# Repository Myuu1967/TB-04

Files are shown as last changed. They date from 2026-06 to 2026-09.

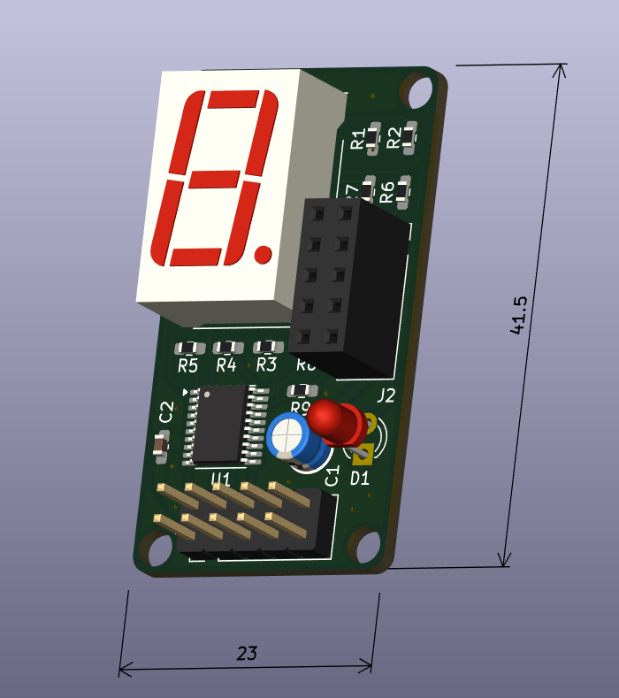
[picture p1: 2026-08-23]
peripherals/7segIF/スクリーンショット (879).png

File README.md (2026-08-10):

# TB-04

自作 4bit CPU **TB-04** のプロジェクトリポジトリです。
TD4 ライクなアーキテクチャをベースに、ALU とデコーダを ROM 実装した独自設計の 4bit CPU です。

回路図・PCB（KiCAD）から、アセンブラ・シミュレータ・テストプログラムまでを世代ごとにまとめています。

## バージョン構成

| 世代 | アドレス幅 | 状態 | ディレクトリ |
|---|---|---|---|
| **ver1** | 4bit（16命令） | 実機完成・全命令動作 | [`ver1/`](ver1/) |
| ver2 | 8bit（256語・データは4bitのまま） | 設計中 | [`ver2/`](ver2/) |
| ver3 | （12bit 化予定） | 構想中 | 追加予定 |

> ver2 以降は、本リポジトリの `ver1/` と並べて追加していきます。

## ver1 の中身

```
ver1/
  hardware/   KiCAD プロジェクト（回路図・PCB・カスタムシンボル/フットプリント）
  sim/        Python による CPU コアシミュレータ・アセンブラ・対話シミュレータ
  tools/      ROM データ生成ツール（ALU / デコーダ / プログラム）・アセンブラ・ロジアナ表示ツール
  codes/      サンプルプログラム・命令テスト（.ASM / .bin / .hex）
  pico_codes/ デバッグ用 簡易ロジックアナライザの Pico 側ファームウェア（MicroPython）
```

ハードウェアの詳細・KiCAD ライブラリの登録方法は [`ver1/hardware/README.md`](ver1/hardware/README.md) を参照してください。

### サンプルプログラム

実機で動かしたデモです。いずれも **16語ROM・4bit・16命令**という制約の中に収めています。

| プログラム | 内容 |
|---|---|
| [`LED_FLOW`](ver1/codes/LED_FLOW.ASM) | 流れるLED（シフト命令なしで実現） |
| [`counter`](ver1/codes/counter.asm) | カウントアップ／ダウン（IN で切替） |
| [`FIBONACCI`](ver1/codes/FIBONACCI.ASM) | フィボナッチ数列 mod 16（ピサノ周期 π(16)=24 で循環） |
| [`RAMEN_TIMER`](ver1/codes/RAMEN_TIMER.ASM) | ラーメンタイマー（TD4 オマージュ） |
| [`KAKEZAN_44`](ver1/codes/KAKEZAN_44.ASM) | かけ算 四四。4×4=16 が4bitで 0 になるのを停止条件に転用 |
| [`LIFE_CA`](ver1/codes/LIFE_CA.ASM) | 1次元セルオートマトン。あふれビットを帰還させ周期15で消えない |
| [`PRED_PREY`](ver1/codes/PRED_PREY.ASM) | 捕食者と被食者の個体数振動（周期6・足し算と引き算だけ） |
| [`MIXED_CORD`](ver1/codes/MIXED_CORD.ASM) | 上記7デモを1個の256語ROMに同梱。ROM上位ニブルの手動セレクタで切替 |

このほかに命令・ポートの動作確認用が17本あります。各プログラムの解説・出力列・アセンブル方法は [`ver1/codes/README.md`](ver1/codes/README.md) を参照してください。

## アーキテクチャ（ver1）

| 項目 | 仕様 |
|---|---|
| データ幅 | 4bit |
| アドレス幅 | 4bit |
| 汎用レジスタ | R0〜R3 |
| フラグ | C（キャリー）、Z（ゼロ） |
| 命令数 | 16命令（OPC 4bit） |
| ALU | ROM 実装（3bit opcode、8演算） |
| デコーダ | ROM 実装（28C256 × 2 並列） |
| プログラム ROM | 28C256 |
| 制御タイミング | 4フェーズ（WB → FCH → DCR → EXE、WB 始まり） |
| スタック | なし |

### 制御タイミングの要点

- 通常命令は開始から2クロック目でフェッチ、4クロック目で実行（全命令ディレイスロットなしの4クロック動作）
- ジャンプ命令のアドレス切り替えは EXE フェーズで実施（ディレイスロット回避）
- フラグは EXE で無条件ラッチ。`MOV`/`MOVI`/`OUT`/`OUTI` は C,Z を 0 クリアするため、**フラグを立てる演算命令の直後に分岐命令（JNC/JZ）を置く**運用とする

## シミュレータの起動

```
cd ver1/sim
python sim.py                        # デフォルト（counter）
python sim.py --prog counter         # 0〜F カウンタ
python sim.py --prog adder           # 加算デモ
python sim.py --prog counter --step  # 1ステップ実行
python sim.py --in 5                 # IN ポートを 5 に設定
```

## ROM データの生成

```
cd ver1/tools
python gen_alu_rom.py        # ALU ROM（alu_rom.bin / .hex）
python gen_decoder_rom.py    # デコーダ ROM（decoder_u22 / u23）
python gen_prog_rom.py       # プログラム ROM
```

## 関連記事

- 設計編 「【TB-04】4bitCPUの設計」: <https://tanuki-bayashin.hatenablog.com/entry/2026/05/27/140048>
- 完成編 「【TB-04】4bitCPUの完成（アドレス4bitバージョン）」: <https://tanuki-bayashin.hatenablog.com/entry/2026/06/20/164917>
- ソースコード編 「【TB-04】4bitCPUのソースコード編（シリーズ完結）」: <https://tanuki-bayashin.hatenablog.com/entry/2026/06/25/220134>
- ロジックアナライザー編 「ラズベリーパイPicoによる簡易ロジックアナライザー」: <https://tanuki-bayashin.hatenablog.com/entry/2026/06/28/074330>

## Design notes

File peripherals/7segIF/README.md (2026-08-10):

# 7segIF — TB-04 用 4bit→7セグメント表示ユニット

本回路は ちぇりーたくあん氏 の nlp リポジトリ（<https://github.com/cherry-takuan/nlp> 、`nlp-16a/Hardware/debug`、CC BY-SA 4.0）を一部参考にし、改変して作成しています。本ユニットのハードウェアも CC BY-SA 4.0 で公開します。

自作 4bit CPU **TB-04** の OUT ポート（4bit）に外付けし、`0`〜`F` を1桁の7セグメントLEDに表示する周辺ユニットです。本体改造は不要で、OUT ポート端子に接続するだけで動作します。ver1／ver2 どちらとも組み合わせられる**版非依存**ユニットのため、リポジトリ直下の `peripherals/` に置いています。

## 構成

| 項目 | 内容 |
|---|---|
| MCU | CH32V003F4P6（WCH・RISC-V, TSSOP-20） |
| 表示器 | LTS-6960HR（コモンアノード・赤・1桁） |
| 電源 | 5V 単一（TB-04 の 74HC 系と共通） |
| デコード方式 | MCU のルックアップテーブル（`0`〜`F` → セグメントパターン） |
| コネクタ | J1（TB-04 OUT 入力）／J2（WCH-Link ＋ UART 兼用ヘッダ） |

## ディレクトリ

```
peripherals/7segIF/
  hardware/            回路図・基板（KiCAD, CC BY-SA 4.0）※完成時にコピー
  firmware/
    main.c             通常版（0〜F をリアルタイム表示）
    main_dp_blink.c    お遊び版（DP を 0.5 秒周期で点滅）
  LICENSE              CC BY-SA 4.0（ハードウェア設計に適用）
  README.md            このファイル
```

## 実配線

- 入力（TB-04 OUT → J1）: `D0=PC0  D1=PC1  D2=PC2  D3=PC3`（PORTC[3:0]）
- 出力（→ 7セグ, 各3.3K）: `a=PD0 b=PD1 c=PD2 d=PD3 e=PD4 f=PD5 g=PD6 DP=PD7`（PORTD[7:0]）
- コモンアノードのため、セグメントは MCU ピン LOW(0) で点灯。

## ファームのビルド・書き込み（MounRiver Studio ＋ WCH SPL）

1. CH32V003F4P6 の新規プロジェクトを作成し、生成される `User/main.c` を `firmware/main.c`（または `main_dp_blink.c`）の内容で**置き換える**。`main()` を持つファイルは1つだけにすること。
2. 初回書き込み時にコードプロテクトで弾かれる場合は、WCH-LinkUtility の `Target → Clear All Code Flash-Protect` で保護解除。接続リセットは **by power off**（本基板は NRST 線をヘッダに出していないため）。
3. **seg b（PD1）は既定で SDI（単線デバッグ）ピン**。ファーム側で SDI を無効化しないと seg b が点灯しません（本リポジトリのファームは対応済み：`GPIO_PinRemapConfig(GPIO_Remap_SDI_Disable, ENABLE)`）。SDI 無効化後はライブデバッグ不可、再書き込みは power-off unlock で行います。
4. **DP（PD7）は既定 NRST**。DP を光らせるにはオプションバイト `RST_MODE` を GPIO 側に設定します（数字 `a`〜`g` のみなら不要）。

## ライセンス

- **ハードウェア**（`hardware/`）: CC BY-SA 4.0。詳細・帰属は [`LICENSE`](./LICENSE) を参照。
- **ファームウェア**（`firmware/`）: ちぇりー氏の著作物に由来しない独自実装で、上記 CC BY-SA の対象外です。

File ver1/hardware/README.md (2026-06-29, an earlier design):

# TB-04

自作4bitCPU **TB-04** のKiCADプロジェクトです。

## 概要

TD4ライクなアーキテクチャをベースに独自設計した4bitCPUです。
ALUとデコーダをROM実装し、汎用レジスタR0〜R3、フラグC/Zを持ちます。

## 現バージョン: 4bitアドレス版

| 項目 | 仕様 |
|---|---|
| データ幅 | 4bit |
| アドレス幅 | 4bit（16命令） |
| 汎用レジスタ | R0〜R3 |
| フラグ | C（キャリー）、Z（ゼロ） |
| ALU | ROM実装（8演算） |
| デコーダ | ROM実装（2個並列） |
| プログラムROM | 28C256（ZIFソケット） |
| 制御タイミング | 4フェーズ（FCH/DCR/EXE/WB） |

> 注記（2026-06-30）: 回路図を一部修正しました。PCBは現在、この修正を反映する改訂作業中（工事中）です。

## 将来の拡張予定

- 8bitアドレス版
- 12bitアドレス版

## ライブラリの登録

このリポジトリにはカスタムシンボル・フットプリントが含まれています。
回路図・PCBを正しく開くには、KiCADのライブラリパスに以下を登録してください。

### シンボルライブラリ

`環境設定 → シンボルライブラリを管理` で以下を追加:

| ライブラリ名 | ファイル |
|---|---|
| `New_Library` | `symbols/New_Library.kicad_sym` |
| `originalCPU` | `symbols/originalCPU.kicad_sym` |
| `74HC161` | `symbols/74HC161N.kicad_sym` |

### フットプリントライブラリ

`環境設定 → フットプリントライブラリを管理` で以下を追加:

| ライブラリ名 | フォルダ |
|---|---|
| `Library` | `footprints/Library.pretty` |

## KiCADプロジェクト構成

| シート | 内容 |
|---|---|
| TB04addr4bitVer3.kicad_sch | トップシート（電源・WEデコード） |
| RS.kicad_sch | レジスタR0〜R3（74HC161 × 4 + 74HC253 × 3） |
| RS01.kicad_sch | 追加レジスタ・プログラム入力 |
| ROM_ALU_Decoder.kicad_sch | 28C256 × 4 + PC + フラグ |
| ALU.kicad_sch | LEDモニターインターフェース |
| clk_rst.kicad_sch | クロック・リセット |
| TB04addr4bitVer3.kicad_pcb | PCBレイアウト |

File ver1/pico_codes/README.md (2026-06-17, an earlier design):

# pico_codes — Pico 簡易ロジックアナライザ（送信側）

デバッグに使用した自作ロジックアナライザの **Raspberry Pi Pico 側ファームウェア**（MicroPython）です。
PC 側の表示ツールは [`../tools/logic_monitor.py`](../tools/logic_monitor.py) を使います。

## forLogiAna.py

- Pico の **GP2〜GP8 を 7ch（CH0〜CH6）の入力**として読み取り、`UART0`（GP0=TX / GP1=RX、115200bps）で CSV 形式に送信します
- フォーマット: `経過秒,CH0,CH1,...,CH6`（10Hz サンプリング）
- 入力は分圧抵抗（例: 1kΩ + 2kΩ）経由で接続

## 使い方

1. Pico に MicroPython を書き込み、`forLogiAna.py` を `main.py` として配置（または実行）
2. Pico の GP0/GP1 を USB シリアル変換に接続し、PC 側で COM ポートを確認
3. PC 側で `python ../tools/logic_monitor.py`（COM ポートはスクリプト内の設定に合わせる）

> ロジックアナライザの製作経緯・回路の詳細は別記事で解説予定です。

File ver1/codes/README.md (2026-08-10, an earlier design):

# ver1 サンプルプログラム

自作 4bit CPU **TB-04 ver1**（データ4bit／アドレス4bit／16命令）で実機動作させたプログラム集です。

各プログラムは `.ASM`（ソース）と `.bin` / `.hex`（アセンブル済みROMイメージ）の3点セットで置いてあります。`.hex` は Intel HEX 形式で、そのまま 28C256 に焼けます。

## ver1 の制約

このCPUの制約を知っていると、コードの書き方の理由が見えてきます。

- **プログラムROMは16語**（PCが4bit）。つまり **1本あたり最大16命令**。ほとんどのデモが「ちょうど16命令」で収まっているのはそのためです
- **汎用レジスタは R0〜R3 の4本**だけ。即値は4bit（0〜15）
- **フラグ保持の機構がない**（C・Z は EXE フェーズで無条件ラッチされ、`MOV`/`MOVI`/`OUT`/`OUTI` は C,Z を0クリアしてしまう）
  → **フラグを立てる命令（`ADD`/`SUB`/`ADDI`/`SUBI`/`AND`/`OR`/`XOR`、`IN` の Z）の直後に分岐命令（`JNC`/`JZ`）を置く**のがver1の運用規約です。退避や表示は分岐より後に回します
- 4bit演算なので加減算はすべて **mod 16**。この「あふれ」を仕様として利用しているデモがいくつかあります

## アセンブルのしかた

```
cd ver1/tools
python tanuki_asm.py    ../codes/counter.asm    -o ../codes/counter      # 16語・単一ページ
python tanuki_asm256.py ../codes/MIXED_CORD.ASM -o ../codes/MIXED_CORD   # 256語・マルチページ
```

`.bin` と `.hex` が生成されます（`--no-bin` で抑止）。通常は `tanuki_asm.py` を使い、後述の `MIXED_CORD` だけ 256語版を使います。

---

## デモプログラム

| ファイル | 内容 | 出力 |
|---|---|---|
| [`LED_FLOW.ASM`](LED_FLOW.ASM) | 流れるLED | IN=0: `1,3,6,12,8,12,6,3`（8周期・往復）／IN≠0: `3,6,12,8`（4周期・一方向） |
| [`counter.asm`](counter.asm) | カウントアップ／ダウン | IN=0: `15→0` ダウン／IN≠0: `1→15→0` アップ |
| [`FIBONACCI.ASM`](FIBONACCI.ASM) | フィボナッチ数列 mod 16 | 周期24 `1,2,3,5,8,13,5,2,7,9,0,9,9,2,11,13,8,5,13,2,15,1,0,1` |
| [`RAMEN_TIMER.ASM`](RAMEN_TIMER.ASM) | ラーメンタイマー（TD4オマージュ） | `1`→`3`→`0,7` 点滅×16→`15` で停止 |
| [`KAKEZAN_44.ASM`](KAKEZAN_44.ASM) | かけ算 四四（4×4の全16積） | `1,2,3,4／2,4,6,8／3,6,9,12／4,8,12,0` で停止 |
| [`LIFE_CA.ASM`](LIFE_CA.ASM) | 1次元セルオートマトン | 周期15 `1,2,4,8,3,6,12,11,5,10,7,14,15,13,9` |
| [`PRED_PREY.ASM`](PRED_PREY.ASM) | 捕食者と被食者の個体数振動 | 周期6 (被食,捕食)=`(15,8)(15,15)(8,15)(1,8)(1,1)(8,1)` |
| [`TASHIZAN_44.ASM`](TASHIZAN_44.ASM) | 四の段を延々出力（`KAKEZAN_44` の停止なし版） | ※ `.bin`/`.hex` は未生成 |
| [`MIXED_CORD.ASM`](MIXED_CORD.ASM) | 上記7デモを1個の256語ROMに同梱（後述） | ページ切替で選択 |

### LED_FLOW — 流れるLED

`OUTI` でパターン列を直接出すだけの構成で、**シフト命令を使わずに**流れるLEDを実現しています。IN の値で往復パターンと一方向パターンを切り替えます（`IN`→`JZ` で分岐）。お披露目向きの一本。

### counter — カウントアップ／ダウン

`IN`→`JZ` で分岐し、`ADDI R0,1` を回すか `SUBI R0,1` を回すかを選びます。`IN` が Z フラグを更新することを利用した最小の分岐例です。

### FIBONACCI — フィボナッチ数列 mod 16

4bitレジスタなので自然に mod 16 になります。フィボナッチ数列を mod m で取ると必ず循環し（**ピサノ周期**）、π(16) = 24 項です。目印は「0 の次に 9 が2回続く」ところと、`15`（全点灯）。7命令/項のループで、`XOR R2,R2` をゼロクリアに使っています。

### RAMEN_TIMER — ラーメンタイマー

`ADDI R0,1` を C が立つまで回す（＝16回）ことを時間の単位に使う遅延ループです。`JNC` でループを作り、区切りごとに `OUTI` で表示を変え、最後に `15`（全点灯）を出して自己ループで停止します。

### KAKEZAN_44 — かけ算 四四

足し算の繰り返しで i×j を作ります。見どころは**レジスタ不足を「終了フラグの転用」で解決**しているところ。4×4=16 は4bitで 0 に落ちて Z=1 が立つので、これをそのまま停止条件に使い、外側ループ用のカウンタを不要にしています。おかげで R0=作業/内側カウンタ、R1=積、R2=被乗数、R3=定数4 の**4本ちょうど**で成立し、**16語ROMにちょうど16命令**で収まりました。

### LIFE_CA — “生きている”1次元セルオートマトン

4セル（=OUT の4LED）だけの素直なセルオートマトンは、線形性のせいで必ず全滅（→0000）してしまいます。そこで**あふれたビットを帰還させて自己再生させる** 4bit最大長LFSR（周期15）＝「Rule60＋帰還」にしました。種 `0001` から非ゼロ15状態を巡回し、消えません。

- 左シフト = `ADD R1,R1`（C = あふれた最上位）
- `JNC` で分岐 → C=1 のとき `XOR R1,M`（帰還タップ M=`0b0011`）
- `IN`→`AND`（マスク `0b0111`）→`OR` でセルを注入し、インタラクティブに軌道をかき乱せます

**XOR / AND / OR を全部使う**のもこのプログラムの役どころです。なお本家コンウェイのライフゲームは盤面用のRAMが要るので ver1 では不可能で、これは ver2（データメモリ導入）への動機になりました。

### PRED_PREY — 捕食者と被食者の個体数振動

本物のロトカ・ヴォルテラ方程式は `prey×pred` の積の項が要るので、乗算のない4bit・16命令では重すぎます。そこで平衡点 K=8 まわりの**線形振動子**を**シンプレクティック更新**（pred の更新に、更新後の prey' を使う）で解き、軌道が閉じる周期6の個体数サイクルにしました。**足し算と引き算だけ**で成立します。

```
prey' = prey + (K - pred)     ; 捕食者が少ないと草食が増える
pred' = pred + (prey' - K)    ; 草食が多いと肉食が増える（更新後の prey' を使う）
```

線形写像 M = [[1,-1],[1,0]] は M⁶ = I（固有値 e^{±iπ/3}）なので、mod 16 でも**厳密に周期6**になります。初期値 prey=8, pred=1 で 1〜15 をフルスイングし、草食のピークから**1世代遅れて**肉食がピークを迎える位相遅れが観察できます。条件分岐を使わない純算術＋`JMP` なので、フラグ運用規約の制約を受けません。

> 軌道は平衡点 (8,8) を通らない閉軌道です。「被食==捕食」になるループが2回（`(15,15)` と `(1,1)`）あり、そこでは LED の見た目が変わらないため止まって見えますが、実際は循環し続けています。

### MIXED_CORD — 7デモを1個のROMに同梱

上の7デモを**16語ページ境界に `.org` で並べて**、256語のROM1個にまとめたものです。

| ページ | デモ | | ページ | デモ |
|---|---|---|---|---|
| `0x00` | LED_FLOW | | `0x80` | LIFE_CA |
| `0x20` | Counter | | `0xA0` | RAMEN_TIMER |
| `0x40` | FIBONACCI | | `0xC0` | PRED_PREY |
| `0x60` | TASHIZAN_44 | | | |

**切り替えはプログラムROM（28C256）の上位ニブル A4–A7 を手動セレクタで選ぶだけ**です。PC 本体は4bitのままで、各デモは自ページ内でループし `JMP` も下位4bitで同ページ内に閉じるので、ページの外へは出ません。**CPU側の変更は不要**で、A4–A7 を選択可能にするだけで動きます（実機確認済み）。

ソフトだけでメニュー切替を作ることはできません。`JMP` が下位4bitしか書けずページを跨げないためで、ハード側のページセレクタが素直な解になります。

アセンブルには **`tanuki_asm256.py`** を使ってください（ラベルを16語ページ単位でスコープ化し、`JMP`/`JZ`/`JNC` を下位4bitで符号化、ページ跨ぎはエラーにします）。

---

## 命令の動作確認用

実機の立ち上げ・デバッグ時に、命令やポートを1つずつ潰していくために書いたものです。ほとんどが16語を埋める形になっています。

| ファイル | 確認内容 |
|---|---|
| `NOP.ASM` | `NOP` ×16（PCが進むことの確認） |
| `MOV.ASM` | `IN` で値を入れて R0〜R3 の全転送組み合わせ |
| `MOVI.ASM` | `MOVI 0`〜`MOVI 15`（即値16通り） |
| `ADD.ASM` | `IN` で値を入れてレジスタ間加算 |
| `ADDI.ASM` / `SUBI.ASM` | 即値 0〜15 の加算／減算（桁上げ・借りの確認） |
| `OUT_I.ASM` | `OUT` と `OUTI` の両方。`1,2,4,8,4,2,1` で単LEDが往復 |
| `JMP_N.ASM` | 全16番地への `JMP`（アドレス各ビットの確認） |
| `JNC.ASM` | `ADDI`→`JNC` のループと `SUBI`→`JZ` のループを両方通す |
| `IN_OUT.ASM` / `IN_ADD.ASM` / `IN_MOV.ASM` | IN ポートと各命令の組み合わせ |
| `IN_AND.ASM` / `IN_OR.ASM` / `IN_XOR.ASM` / `IN_SUB.ASM` | 論理演算・減算の全パターン掃引 |

`IN_AND.ASM` は実機デバッグで役に立った一本で、AND 命令の全レジスタ組み合わせを掃引しながらロジックアナライザでセレクト信号を同時観測し、**MUXの誤結線**（74HC253 の S1 と `/E2` の取り違え）を突き止めました。

---

## 関連

- 設計の解説: [【TB-04】4bitCPUの設計](https://tanuki-bayashin.hatenablog.com/entry/2026/05/27/140048)
- 完成の様子とデモ動画: [【TB-04】4bitCPUの完成（アドレス4bitバージョン）](https://tanuki-bayashin.hatenablog.com/entry/2026/06/20/164917)
- ROM生成・アセンブラ・シミュレータの解説: [【TB-04】4bitCPUのソースコード編](https://tanuki-bayashin.hatenablog.com/entry/2026/06/25/220134)
- シミュレータでの実行方法はリポジトリ直下の [README](../../README.md) を参照

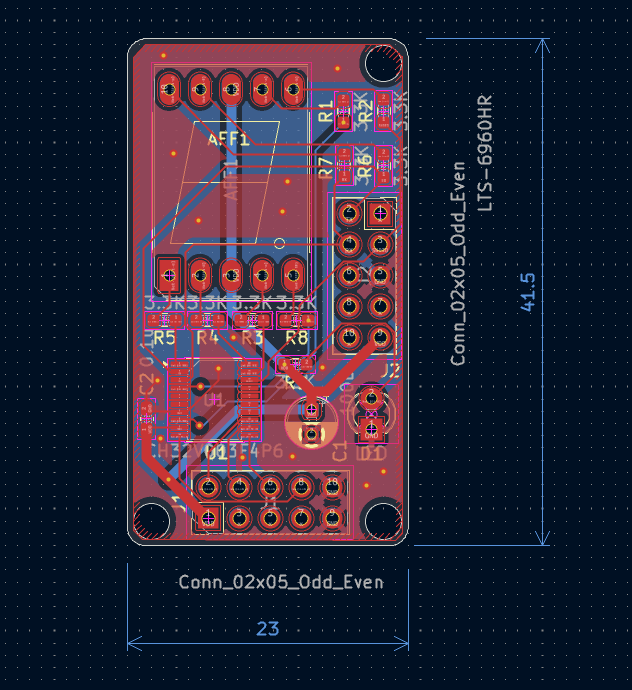
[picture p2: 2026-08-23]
peripherals/7segIF/スクリーンショット (878).png

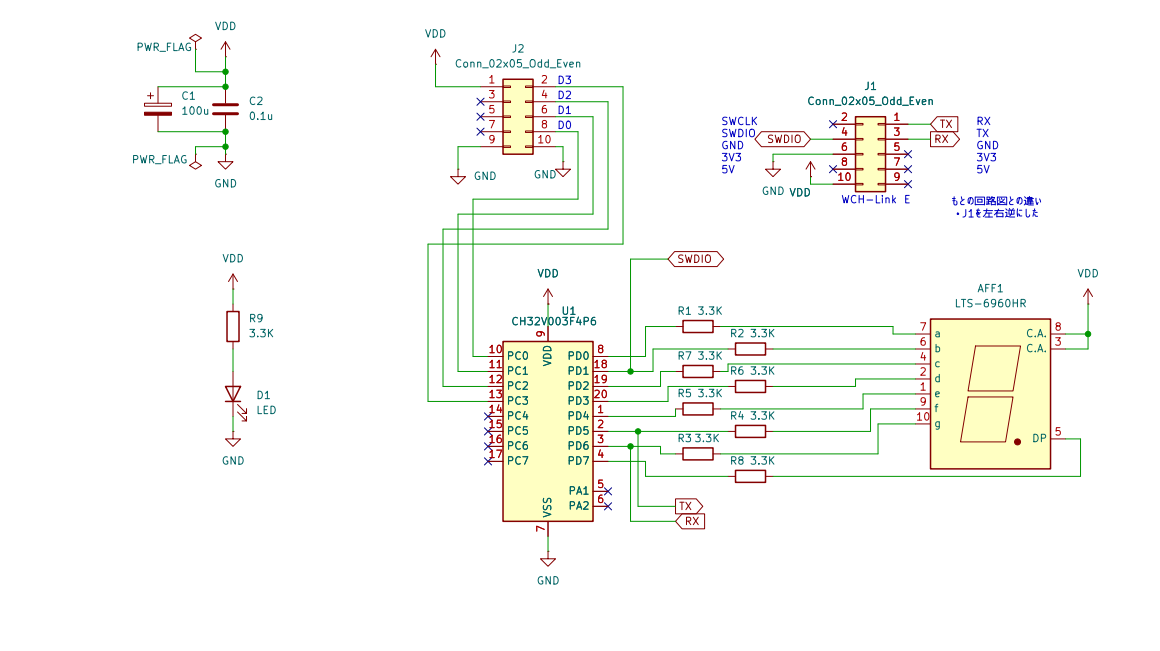
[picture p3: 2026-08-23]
peripherals/7segIF/スクリーンショット (913).png

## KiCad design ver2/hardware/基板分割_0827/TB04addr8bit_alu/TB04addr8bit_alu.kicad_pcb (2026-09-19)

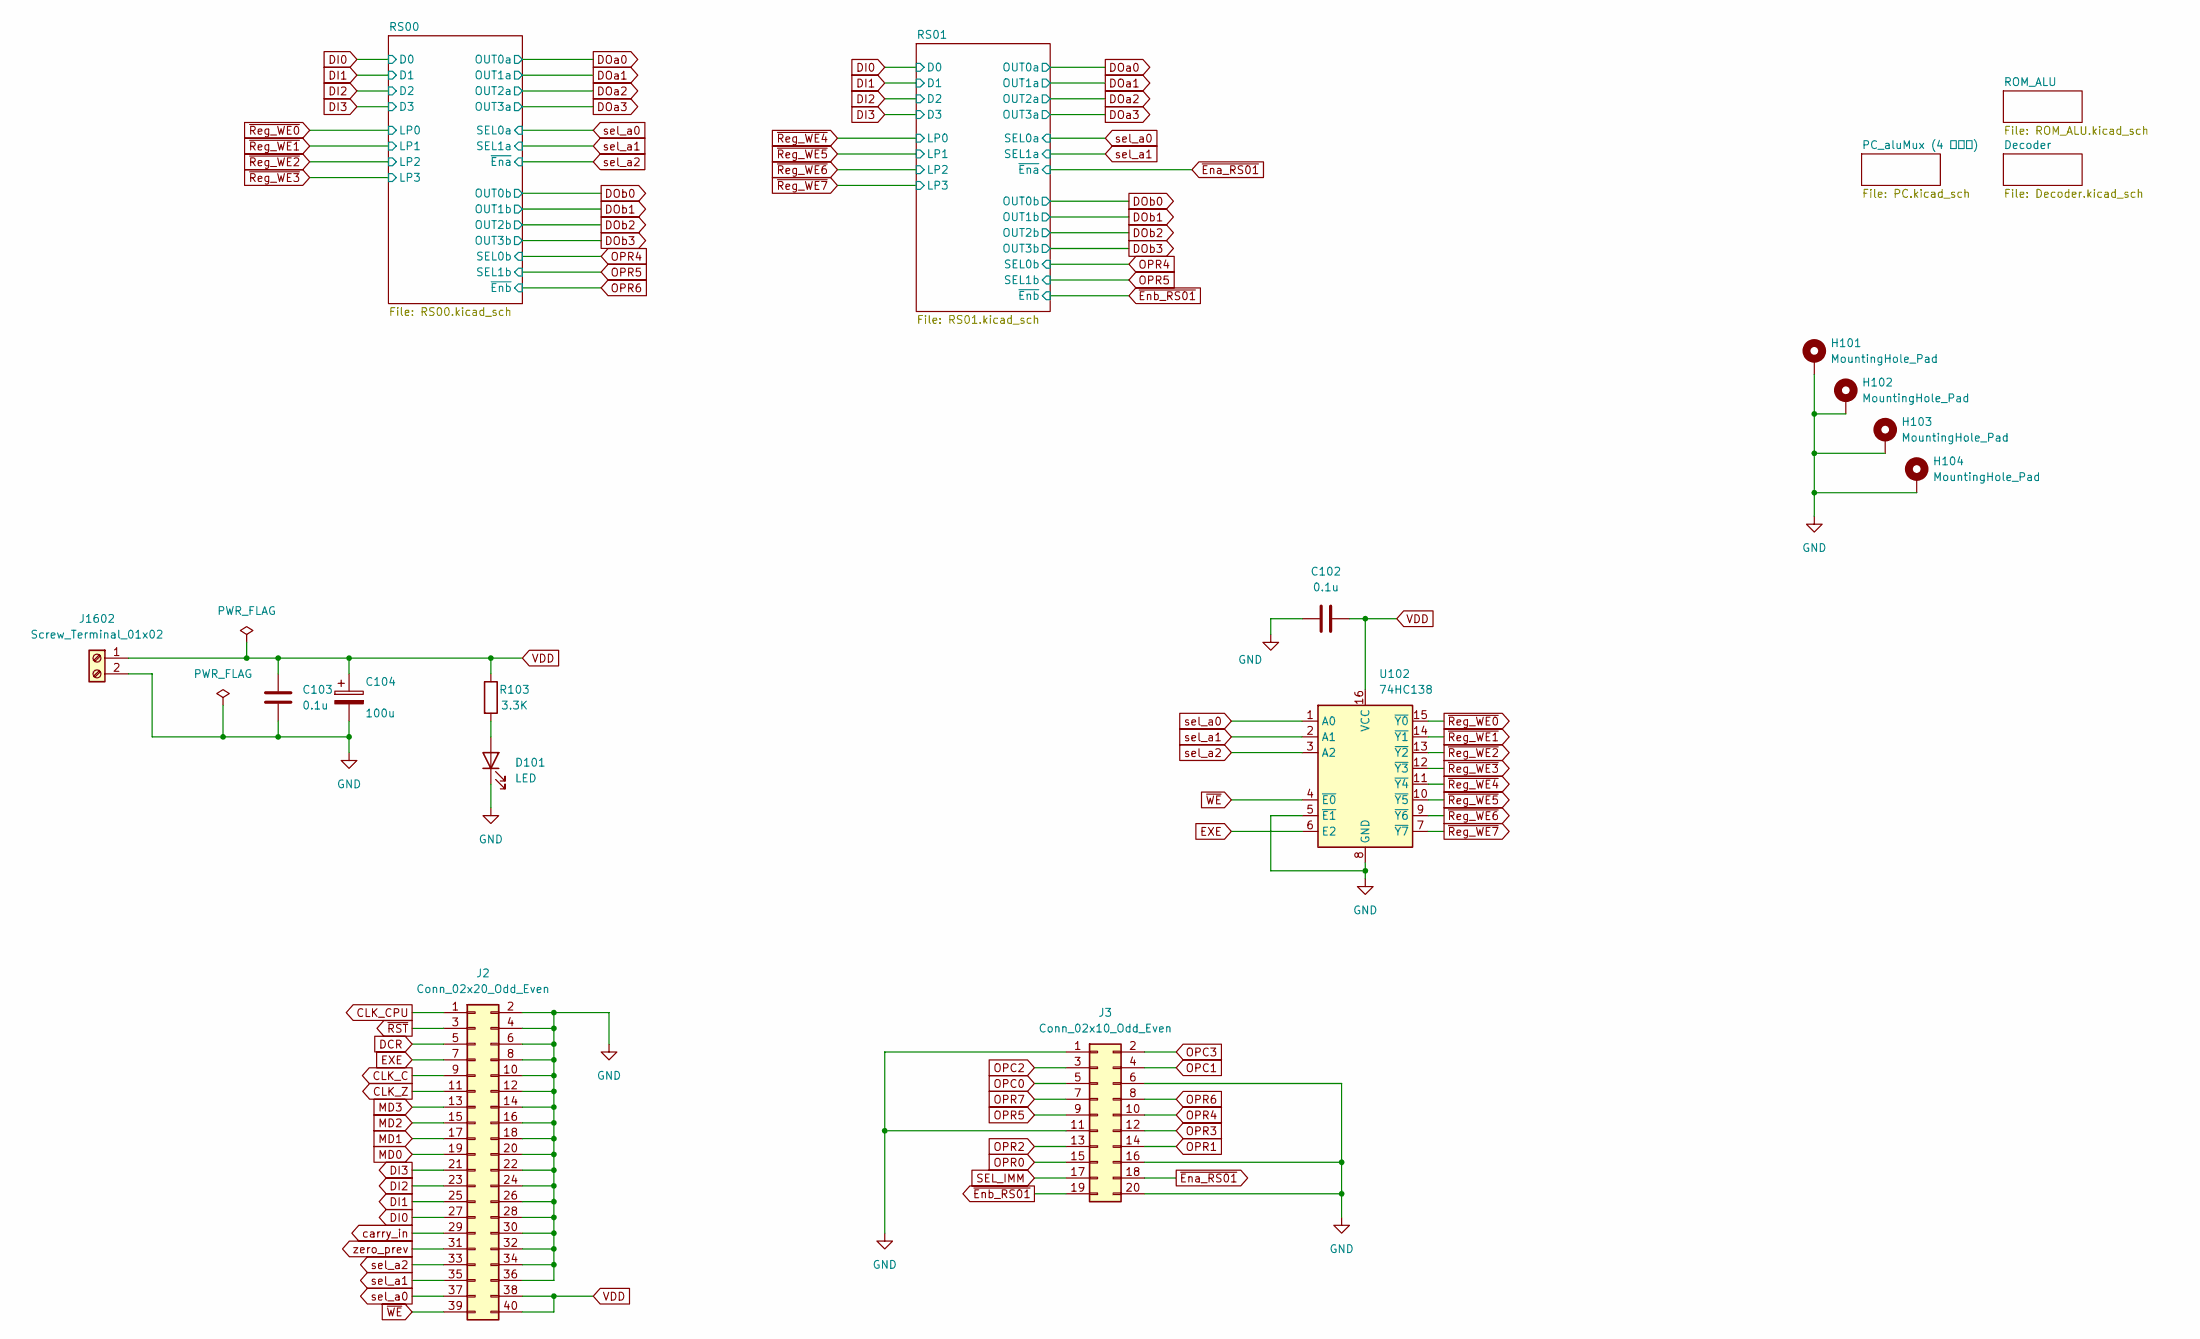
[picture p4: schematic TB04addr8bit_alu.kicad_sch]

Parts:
C102, C103: 0.1u; C_Disc_D4.3mm_W1.9mm_P5.00mm
C104: 100u; CP_Radial_D5.0mm_P2.00mm
D101: LED; LED_D3.0mm_Clear
H101, H102, H103, H104: MountingHole_Pad; MountingHole_3.2mm_M3_Pad_Via
J2: Conn_02x20_Odd_Even; PinSocket_2x20_P2.54mm_Vertical
J3: Conn_02x10_Odd_Even; PinSocket_2x10_P2.54mm_Vertical
J1602: Screw_Terminal_01x02; TerminalBlock_MaiXu_MX126-5.0-02P_1x02_P5.00mm
R103: 3.3K; R_Axial_DIN0207_L6.3mm_D2.5mm_P7.62mm_Horizontal
U102: 74HC138; DIP-16_W7.62mm_Socket

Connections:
CLK_C: J2.9; also elsewhere on the board
CLK_CPU: J2.1; also elsewhere on the board
CLK_Z: J2.11; also elsewhere on the board
DCR: J2.5; also elsewhere on the board
DI0: J2.27; also elsewhere on the board
DI1: J2.25; also elsewhere on the board
DI2: J2.23; also elsewhere on the board
DI3: J2.21; also elsewhere on the board
EXE: J2.7, U102.6 (E2)
GND: C102.2, C103.2, C104.2, D101.1 (K), H101.1 (1_1), H102.1 (1_1), H103.1 (1_1), H104.1 (1_1), J2.2, J2.4, J2.6, J2.8, J2.10, J2.12, J2.14, J2.16, J2.18, J2.20, J2.22, J2.24, J2.26, J2.28, J2.30, J2.32, J2.34, J2.36, J3.1, J3.6, J3.11, J3.16, J3.20, J1602.2, U102.5 (~E1), U102.8 (GND); also elsewhere on the board
MD0: J2.19; also elsewhere on the board
MD1: J2.17; also elsewhere on the board
MD2: J2.15; also elsewhere on the board
MD3: J2.13; also elsewhere on the board
unnamed: D101.2 (A), R103.2
OPC0: J3.5; also elsewhere on the board
OPC1: J3.4; also elsewhere on the board
OPC2: J3.3; also elsewhere on the board
OPC3: J3.2; also elsewhere on the board
OPR0: J3.15; also elsewhere on the board
OPR1: J3.14; also elsewhere on the board
OPR2: J3.13; also elsewhere on the board
OPR3: J3.12; also elsewhere on the board
OPR4: J3.10; also elsewhere on the board
OPR5: J3.9; also elsewhere on the board
OPR6: J3.8; also elsewhere on the board
OPR7: J3.7; also elsewhere on the board
SEL_IMM: J3.17; also elsewhere on the board
VDD: C102.1, C103.1, C104.1, J2.38, J2.40, J1602.1, R103.1, U102.16 (VCC); also elsewhere on the board
carry_in: J2.29; also elsewhere on the board
sel_a0: J2.37, U102.1 (A0); also elsewhere on the board
sel_a1: J2.35, U102.2 (A1); also elsewhere on the board
sel_a2: J2.33, U102.3 (A2); also elsewhere on the board
zero_prev: J2.31; also elsewhere on the board
~Ena_RS01: J3.18; also elsewhere on the board
~Enb_RS01: J3.19; also elsewhere on the board
~RST: J2.3; also elsewhere on the board
~Reg_WE0: U102.15 (~Y0); also elsewhere on the board
~Reg_WE1: U102.14 (~Y1); also elsewhere on the board
~Reg_WE2: U102.13 (~Y2); also elsewhere on the board
~Reg_WE3: U102.12 (~Y3); also elsewhere on the board
~Reg_WE4: U102.11 (~Y4); also elsewhere on the board
~Reg_WE5: U102.10 (~Y5); also elsewhere on the board
~Reg_WE6: U102.9 (~Y6); also elsewhere on the board
~Reg_WE7: U102.7 (~Y7); also elsewhere on the board
~WE: J2.39, U102.4 (~E0)

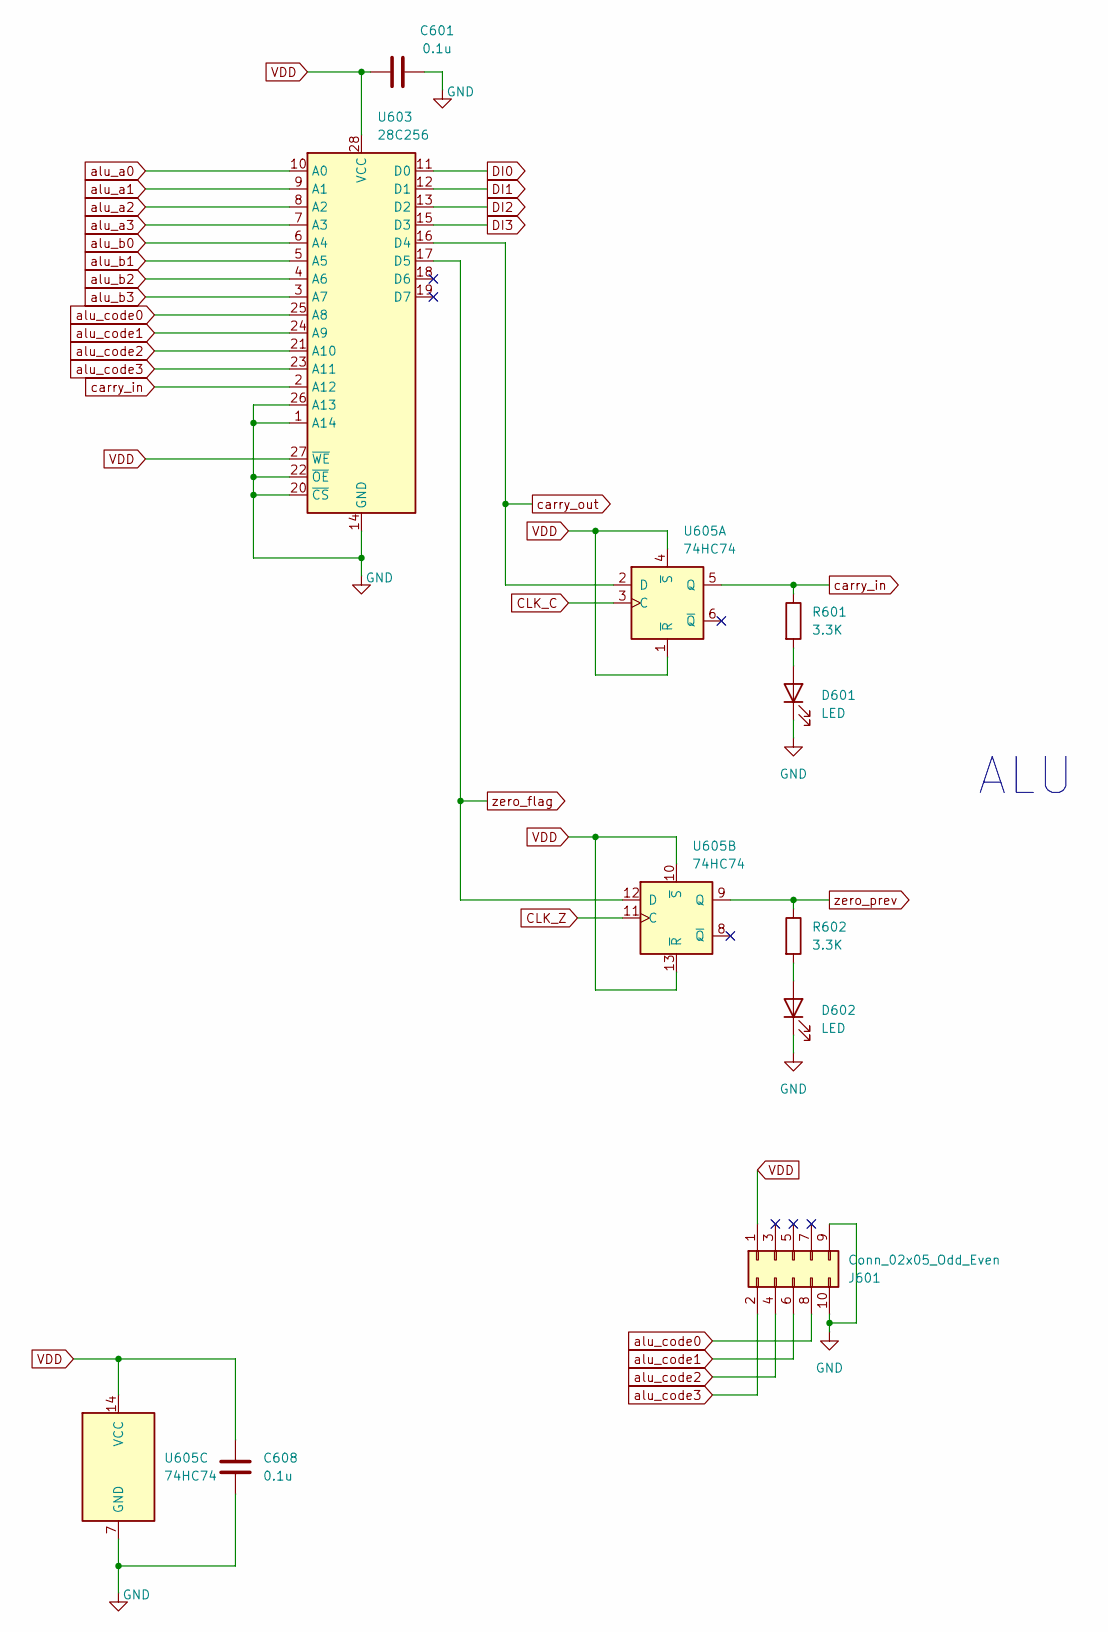
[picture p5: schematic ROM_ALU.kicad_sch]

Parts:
C601, C608: 0.1u; C_Disc_D4.3mm_W1.9mm_P5.00mm
D601, D602: LED; LED_D3.0mm_Clear
J601: Conn_02x05_Odd_Even; PinSocket_2x05_P2.54mm_Vertical
R601, R602: 3.3K; R_Axial_DIN0207_L6.3mm_D2.5mm_P7.62mm_Horizontal
U603: 28C256; DIP-28_W15.24mm_Socket
U605: 74HC74; DIP-14_W7.62mm_Socket

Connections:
CLK_C: U605.3 (C); also elsewhere on the board
CLK_Z: U605.11 (C); also elsewhere on the board
DI0: U603.11 (D0); also elsewhere on the board
DI1: U603.12 (D1); also elsewhere on the board
DI2: U603.13 (D2); also elsewhere on the board
DI3: U603.15 (D3); also elsewhere on the board
GND: C601.1, C608.2, D601.1 (K), D602.1 (K), J601.9, J601.10, U603.1 (A14), U603.14 (GND), U603.20 (~CS), U603.22 (~OE), U603.26 (A13), U605.7 (GND); also elsewhere on the board
unnamed: D601.2 (A), R601.2
unnamed: D602.2 (A), R602.2
VDD: C601.2, C608.1, J601.1, U603.27 (~WE), U603.28 (VCC), U605.1 (~R), U605.4 (~S), U605.10 (~S), U605.13 (~R), U605.14 (VCC); also elsewhere on the board
alu_a0: U603.10 (A0); also elsewhere on the board
alu_a1: U603.9 (A1); also elsewhere on the board
alu_a2: U603.8 (A2); also elsewhere on the board
alu_a3: U603.7 (A3); also elsewhere on the board
alu_b0: U603.6 (A4); also elsewhere on the board
alu_b1: U603.5 (A5); also elsewhere on the board
alu_b2: U603.4 (A6); also elsewhere on the board
alu_b3: U603.3 (A7); also elsewhere on the board
alu_code0: J601.8, U603.25 (A8); also elsewhere on the board
alu_code1: J601.6, U603.24 (A9); also elsewhere on the board
alu_code2: J601.4, U603.21 (A10); also elsewhere on the board
alu_code3: J601.2, U603.23 (A11); also elsewhere on the board
carry_in: R601.1, U603.2 (A12), U605.5 (Q); also elsewhere on the board
carry_out: U603.16 (D4), U605.2 (D)
zero_flag: U603.17 (D5), U605.12 (D)
zero_prev: R602.1, U605.9 (Q); also elsewhere on the board

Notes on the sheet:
ALU

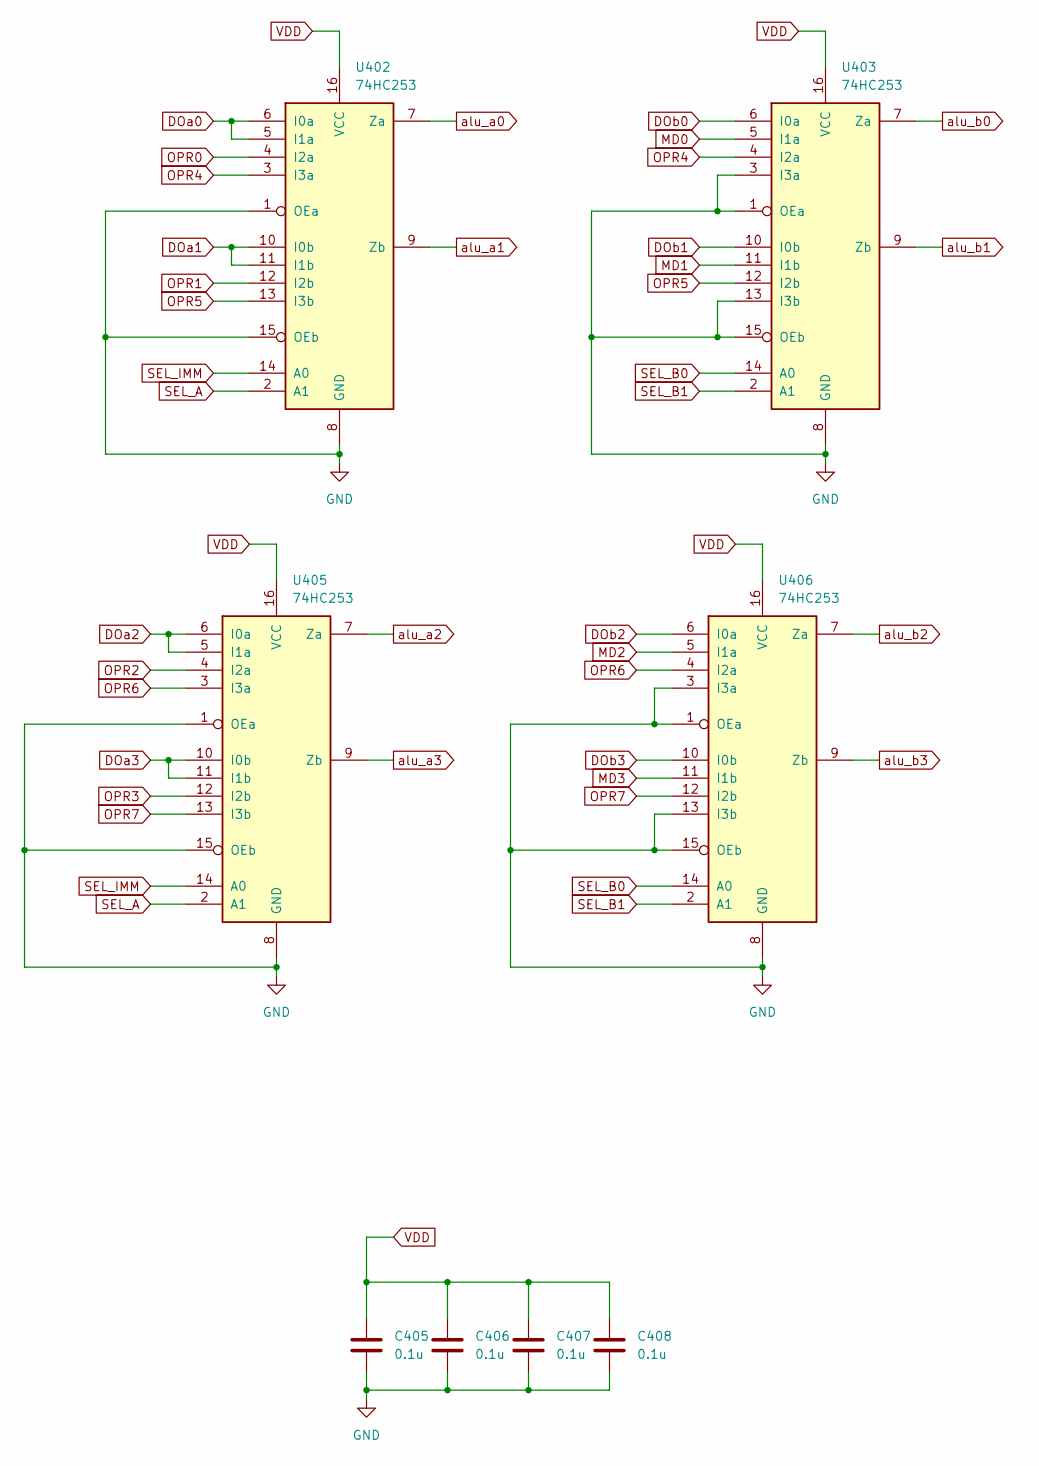
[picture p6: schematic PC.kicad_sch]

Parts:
C405, C406, C407, C408: 0.1u; C_Disc_D4.3mm_W1.9mm_P5.00mm
U402, U403, U405, U406: 74HC253; DIP-16_W7.62mm_Socket

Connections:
DOa0: U402.5 (I1a), U402.6 (I0a); also elsewhere on the board
DOa1: U402.10 (I0b), U402.11 (I1b); also elsewhere on the board
DOa2: U405.5 (I1a), U405.6 (I0a); also elsewhere on the board
DOa3: U405.10 (I0b), U405.11 (I1b); also elsewhere on the board
DOb0: U403.6 (I0a); also elsewhere on the board
DOb1: U403.10 (I0b); also elsewhere on the board
DOb2: U406.6 (I0a); also elsewhere on the board
DOb3: U406.10 (I0b); also elsewhere on the board
GND: C405.1, C406.1, C407.1, C408.1, U402.1 (OEa), U402.8 (GND), U402.15 (OEb), U403.1 (OEa), U403.3 (I3a), U403.8 (GND), U403.13 (I3b), U403.15 (OEb), U405.1 (OEa), U405.8 (GND), U405.15 (OEb), U406.1 (OEa), U406.3 (I3a), U406.8 (GND), U406.13 (I3b), U406.15 (OEb); also elsewhere on the board
MD0: U403.5 (I1a); also elsewhere on the board
MD1: U403.11 (I1b); also elsewhere on the board
MD2: U406.5 (I1a); also elsewhere on the board
MD3: U406.11 (I1b); also elsewhere on the board
OPR0: U402.4 (I2a); also elsewhere on the board
OPR1: U402.12 (I2b); also elsewhere on the board
OPR2: U405.4 (I2a); also elsewhere on the board
OPR3: U405.12 (I2b); also elsewhere on the board
OPR4: U402.3 (I3a), U403.4 (I2a); also elsewhere on the board
OPR5: U402.13 (I3b), U403.12 (I2b); also elsewhere on the board
OPR6: U405.3 (I3a), U406.4 (I2a); also elsewhere on the board
OPR7: U405.13 (I3b), U406.12 (I2b); also elsewhere on the board
SEL_A: U402.2 (A1), U405.2 (A1); also elsewhere on the board
SEL_B0: U403.14 (A0), U406.14 (A0); also elsewhere on the board
SEL_B1: U403.2 (A1), U406.2 (A1); also elsewhere on the board
SEL_IMM: U402.14 (A0), U405.14 (A0); also elsewhere on the board
VDD: C405.2, C406.2, C407.2, C408.2, U402.16 (VCC), U403.16 (VCC), U405.16 (VCC), U406.16 (VCC); also elsewhere on the board
alu_a0: U402.7 (Za); also elsewhere on the board
alu_a1: U402.9 (Zb); also elsewhere on the board
alu_a2: U405.7 (Za); also elsewhere on the board
alu_a3: U405.9 (Zb); also elsewhere on the board
alu_b0: U403.7 (Za); also elsewhere on the board
alu_b1: U403.9 (Zb); also elsewhere on the board
alu_b2: U406.7 (Za); also elsewhere on the board
alu_b3: U406.9 (Zb); also elsewhere on the board

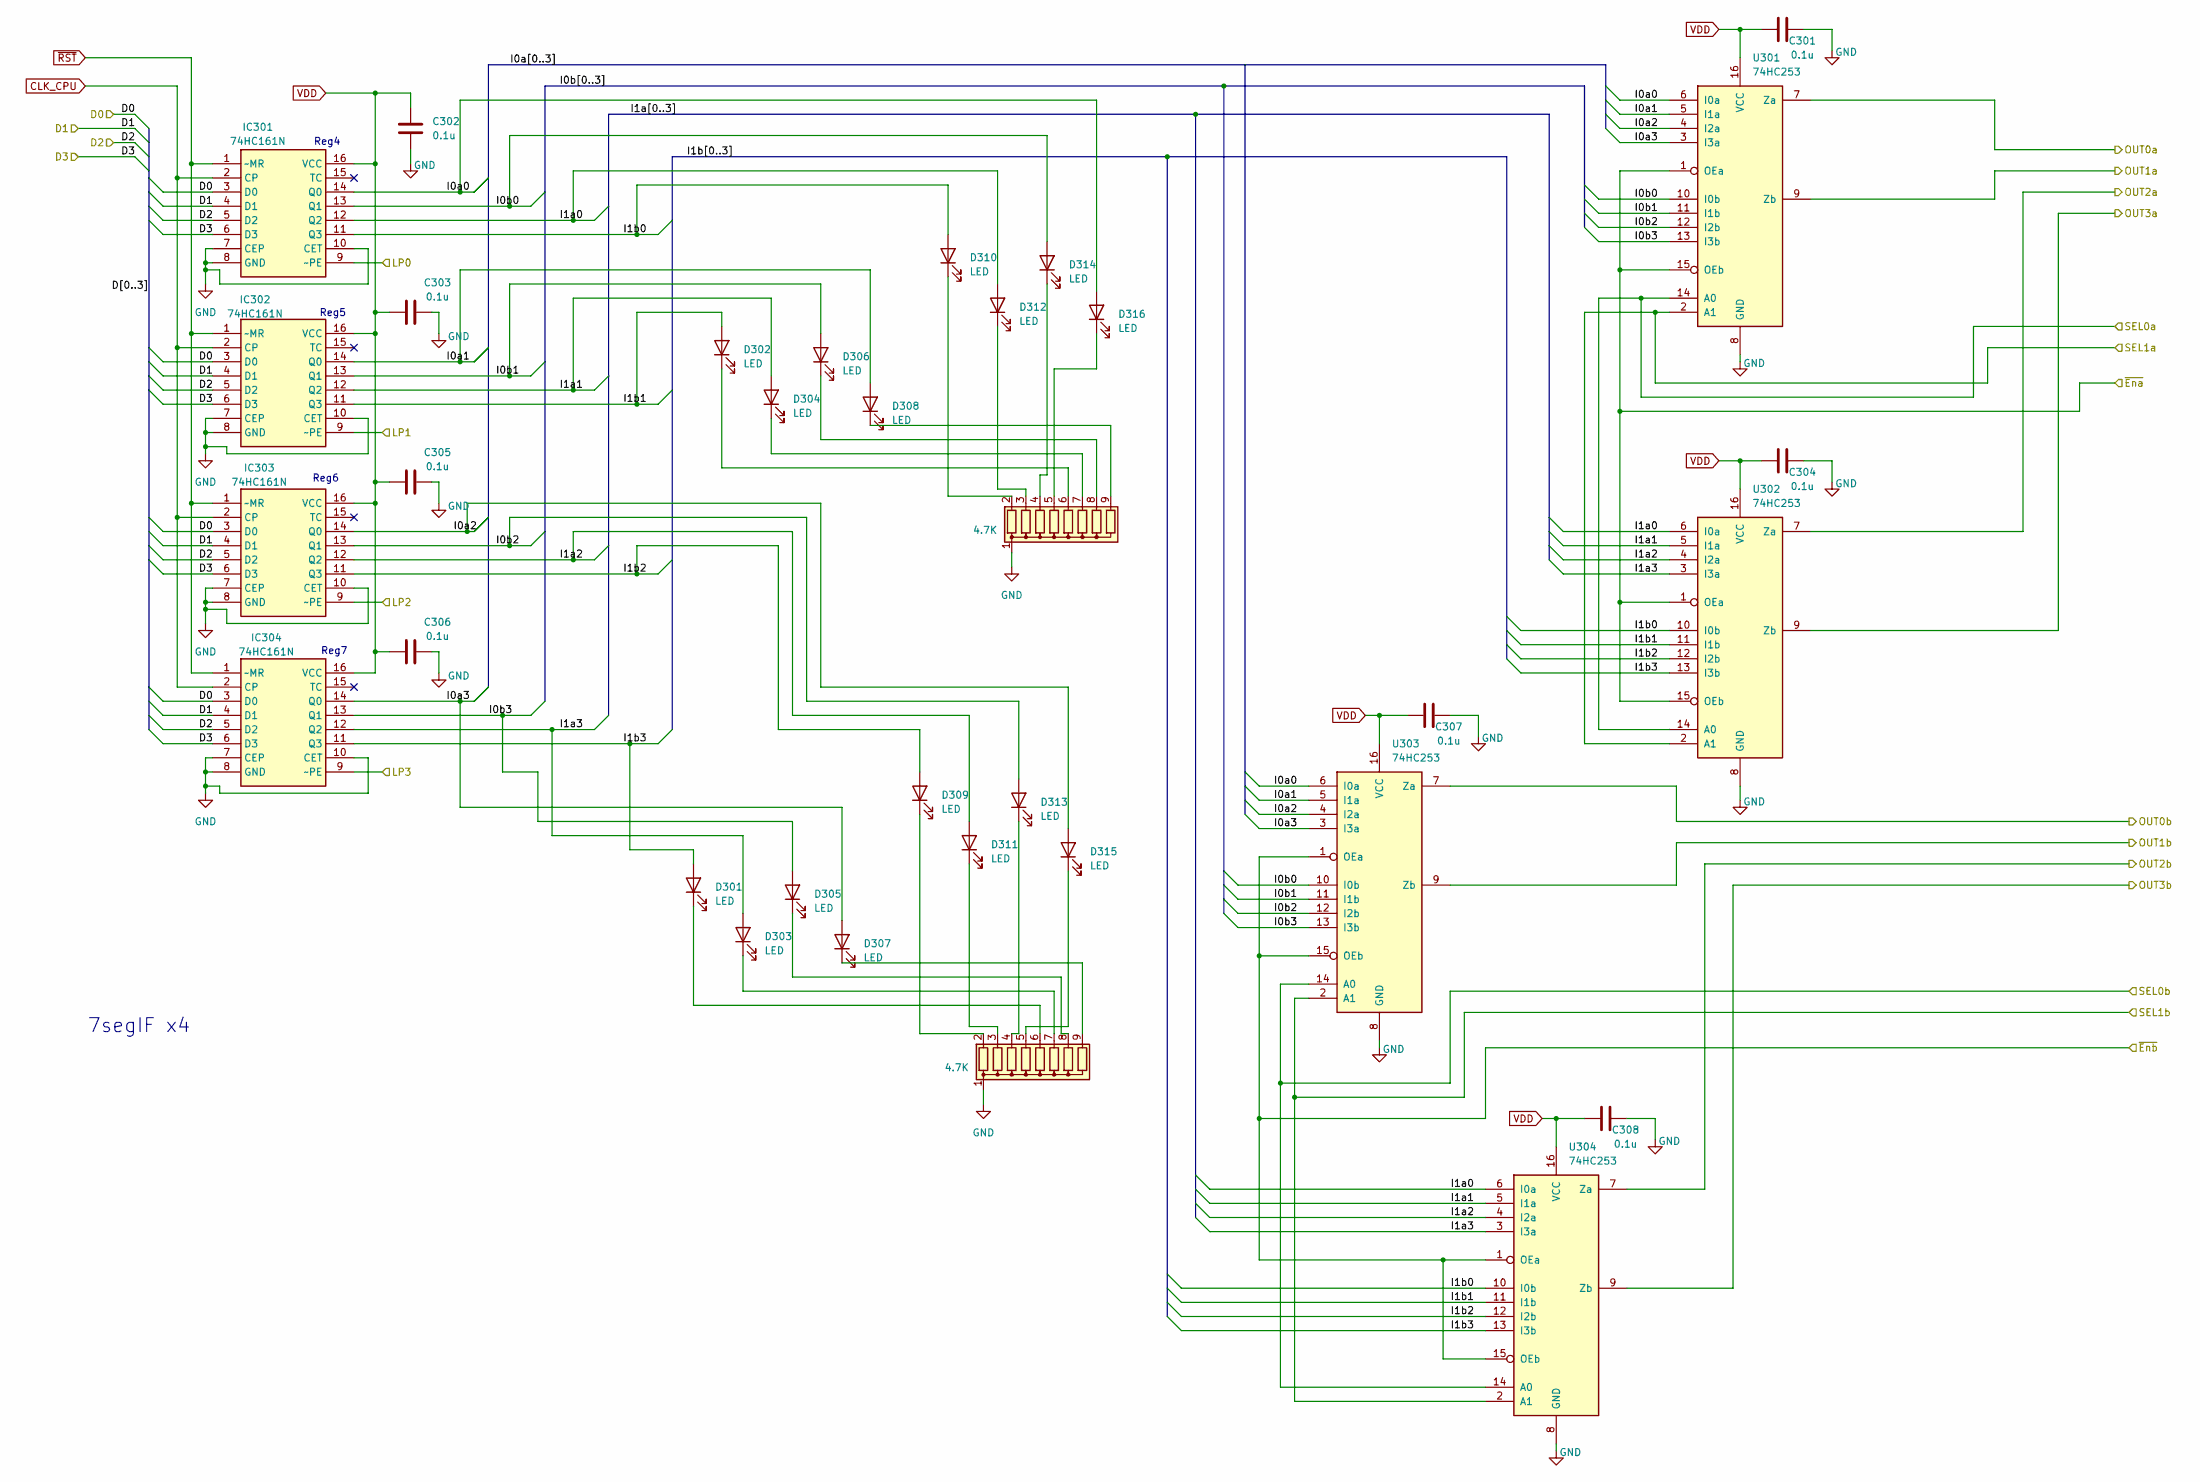
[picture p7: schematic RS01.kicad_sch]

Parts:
C301, C302, C303, C304, C305, C306, C307, C308: 0.1u; C_Disc_D4.3mm_W1.9mm_P5.00mm
D301, D302, D303, D304, D305, D306, D307, D308, D309, D310, D311, D312, D313, D314, D315, D316: LED; LED_D3.0mm_Clear
IC301, IC302, IC303, IC304: 74HC161N; DIP-16_W7.62mm_Socket; Manufacturer_Part_Number 74HC161N
RN301, RN302: 4.7K; R_Array_SIP9
U301, U302, U303, U304: 74HC253; DIP-16_W7.62mm_Socket

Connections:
/RS01/I0a0: D316.2 (A), IC301.14 (Q0), U301.6 (I0a), U303.6 (I0a)
/RS01/I0a1: D308.2 (A), IC302.14 (Q0), U301.5 (I1a), U303.5 (I1a)
/RS01/I0a2: D315.2 (A), IC303.14 (Q0), U301.4 (I2a), U303.4 (I2a)
/RS01/I0a3: D307.2 (A), IC304.14 (Q0), U301.3 (I3a), U303.3 (I3a)
/RS01/I0b0: D314.2 (A), IC301.13 (Q1), U301.10 (I0b), U303.10 (I0b)
/RS01/I0b1: D306.2 (A), IC302.13 (Q1), U301.11 (I1b), U303.11 (I1b)
/RS01/I0b2: D313.2 (A), IC303.13 (Q1), U301.12 (I2b), U303.12 (I2b)
/RS01/I0b3: D305.2 (A), IC304.13 (Q1), U301.13 (I3b), U303.13 (I3b)
/RS01/I1a0: D312.2 (A), IC301.12 (Q2), U302.6 (I0a), U304.6 (I0a)
/RS01/I1a1: D304.2 (A), IC302.12 (Q2), U302.5 (I1a), U304.5 (I1a)
/RS01/I1a2: D311.2 (A), IC303.12 (Q2), U302.4 (I2a), U304.4 (I2a)
/RS01/I1a3: D303.2 (A), IC304.12 (Q2), U302.3 (I3a), U304.3 (I3a)
/RS01/I1b0: D310.2 (A), IC301.11 (Q3), U302.10 (I0b), U304.10 (I0b)
/RS01/I1b1: D302.2 (A), IC302.11 (Q3), U302.11 (I1b), U304.11 (I1b)
/RS01/I1b2: D309.2 (A), IC303.11 (Q3), U302.12 (I2b), U304.12 (I2b)
/RS01/I1b3: D301.2 (A), IC304.11 (Q3), U302.13 (I3b), U304.13 (I3b)
CLK_CPU: IC301.2 (CP), IC302.2 (CP), IC303.2 (CP), IC304.2 (CP); also elsewhere on the board
DI0: IC301.3 (D0), IC302.3 (D0), IC303.3 (D0), IC304.3 (D0); also elsewhere on the board
DI1: IC301.4 (D1), IC302.4 (D1), IC303.4 (D1), IC304.4 (D1); also elsewhere on the board
DI2: IC301.5 (D2), IC302.5 (D2), IC303.5 (D2), IC304.5 (D2); also elsewhere on the board
DI3: IC301.6 (D3), IC302.6 (D3), IC303.6 (D3), IC304.6 (D3); also elsewhere on the board
DOa0: U301.7 (Za); also elsewhere on the board
DOa1: U301.9 (Zb); also elsewhere on the board
DOa2: U302.7 (Za); also elsewhere on the board
DOa3: U302.9 (Zb); also elsewhere on the board
DOb0: U303.7 (Za); also elsewhere on the board
DOb1: U303.9 (Zb); also elsewhere on the board
DOb2: U304.7 (Za); also elsewhere on the board
DOb3: U304.9 (Zb); also elsewhere on the board
GND: C301.1, C302.1, C303.1, C304.1, C305.1, C306.1, C307.1, C308.1, IC301.7 (CEP), IC301.8 (GND), IC301.10 (CET), IC302.7 (CEP), IC302.8 (GND), IC302.10 (CET), IC303.7 (CEP), IC303.8 (GND), IC303.10 (CET), IC304.7 (CEP), IC304.8 (GND), IC304.10 (CET), RN301.1 (common), RN302.1 (common), U301.8 (GND), U302.8 (GND), U303.8 (GND), U304.8 (GND); also elsewhere on the board
unnamed: D301.1 (K), RN301.6 (R5)
unnamed: D302.1 (K), RN302.6 (R5)
unnamed: D303.1 (K), RN301.7 (R6)
unnamed: D304.1 (K), RN302.7 (R6)
unnamed: D305.1 (K), RN301.8 (R7)
unnamed: D306.1 (K), RN302.8 (R7)
unnamed: D307.1 (K), RN301.9 (R8)
unnamed: D308.1 (K), RN302.9 (R8)
unnamed: D309.1 (K), RN301.2 (R1)
unnamed: D310.1 (K), RN302.2 (R1)
unnamed: D311.1 (K), RN301.3 (R2)
unnamed: D312.1 (K), RN302.3 (R2)
unnamed: D313.1 (K), RN301.4 (R3)
unnamed: D314.1 (K), RN302.4 (R3)
unnamed: D315.1 (K), RN301.5 (R4)
unnamed: D316.1 (K), RN302.5 (R4)
OPR4: U303.14 (A0), U304.14 (A0); also elsewhere on the board
OPR5: U303.2 (A1), U304.2 (A1); also elsewhere on the board
VDD: C301.2, C302.2, C303.2, C304.2, C305.2, C306.2, C307.2, C308.2, IC301.16 (VCC), IC302.16 (VCC), IC303.16 (VCC), IC304.16 (VCC), U301.16 (VCC), U302.16 (VCC), U303.16 (VCC), U304.16 (VCC); also elsewhere on the board
sel_a0: U301.14 (A0), U302.14 (A0); also elsewhere on the board
sel_a1: U301.2 (A1), U302.2 (A1); also elsewhere on the board
~Ena_RS01: U301.1 (OEa), U301.15 (OEb), U302.1 (OEa), U302.15 (OEb); also elsewhere on the board
~Enb_RS01: U303.1 (OEa), U303.15 (OEb), U304.1 (OEa), U304.15 (OEb); also elsewhere on the board
~RST: IC301.1 (~MR), IC302.1 (~MR), IC303.1 (~MR), IC304.1 (~MR); also elsewhere on the board
~Reg_WE4: IC301.9 (~PE); also elsewhere on the board
~Reg_WE5: IC302.9 (~PE); also elsewhere on the board
~Reg_WE6: IC303.9 (~PE); also elsewhere on the board
~Reg_WE7: IC304.9 (~PE); also elsewhere on the board

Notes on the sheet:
Reg5
Reg4
Reg7
7segIF x4
Reg6

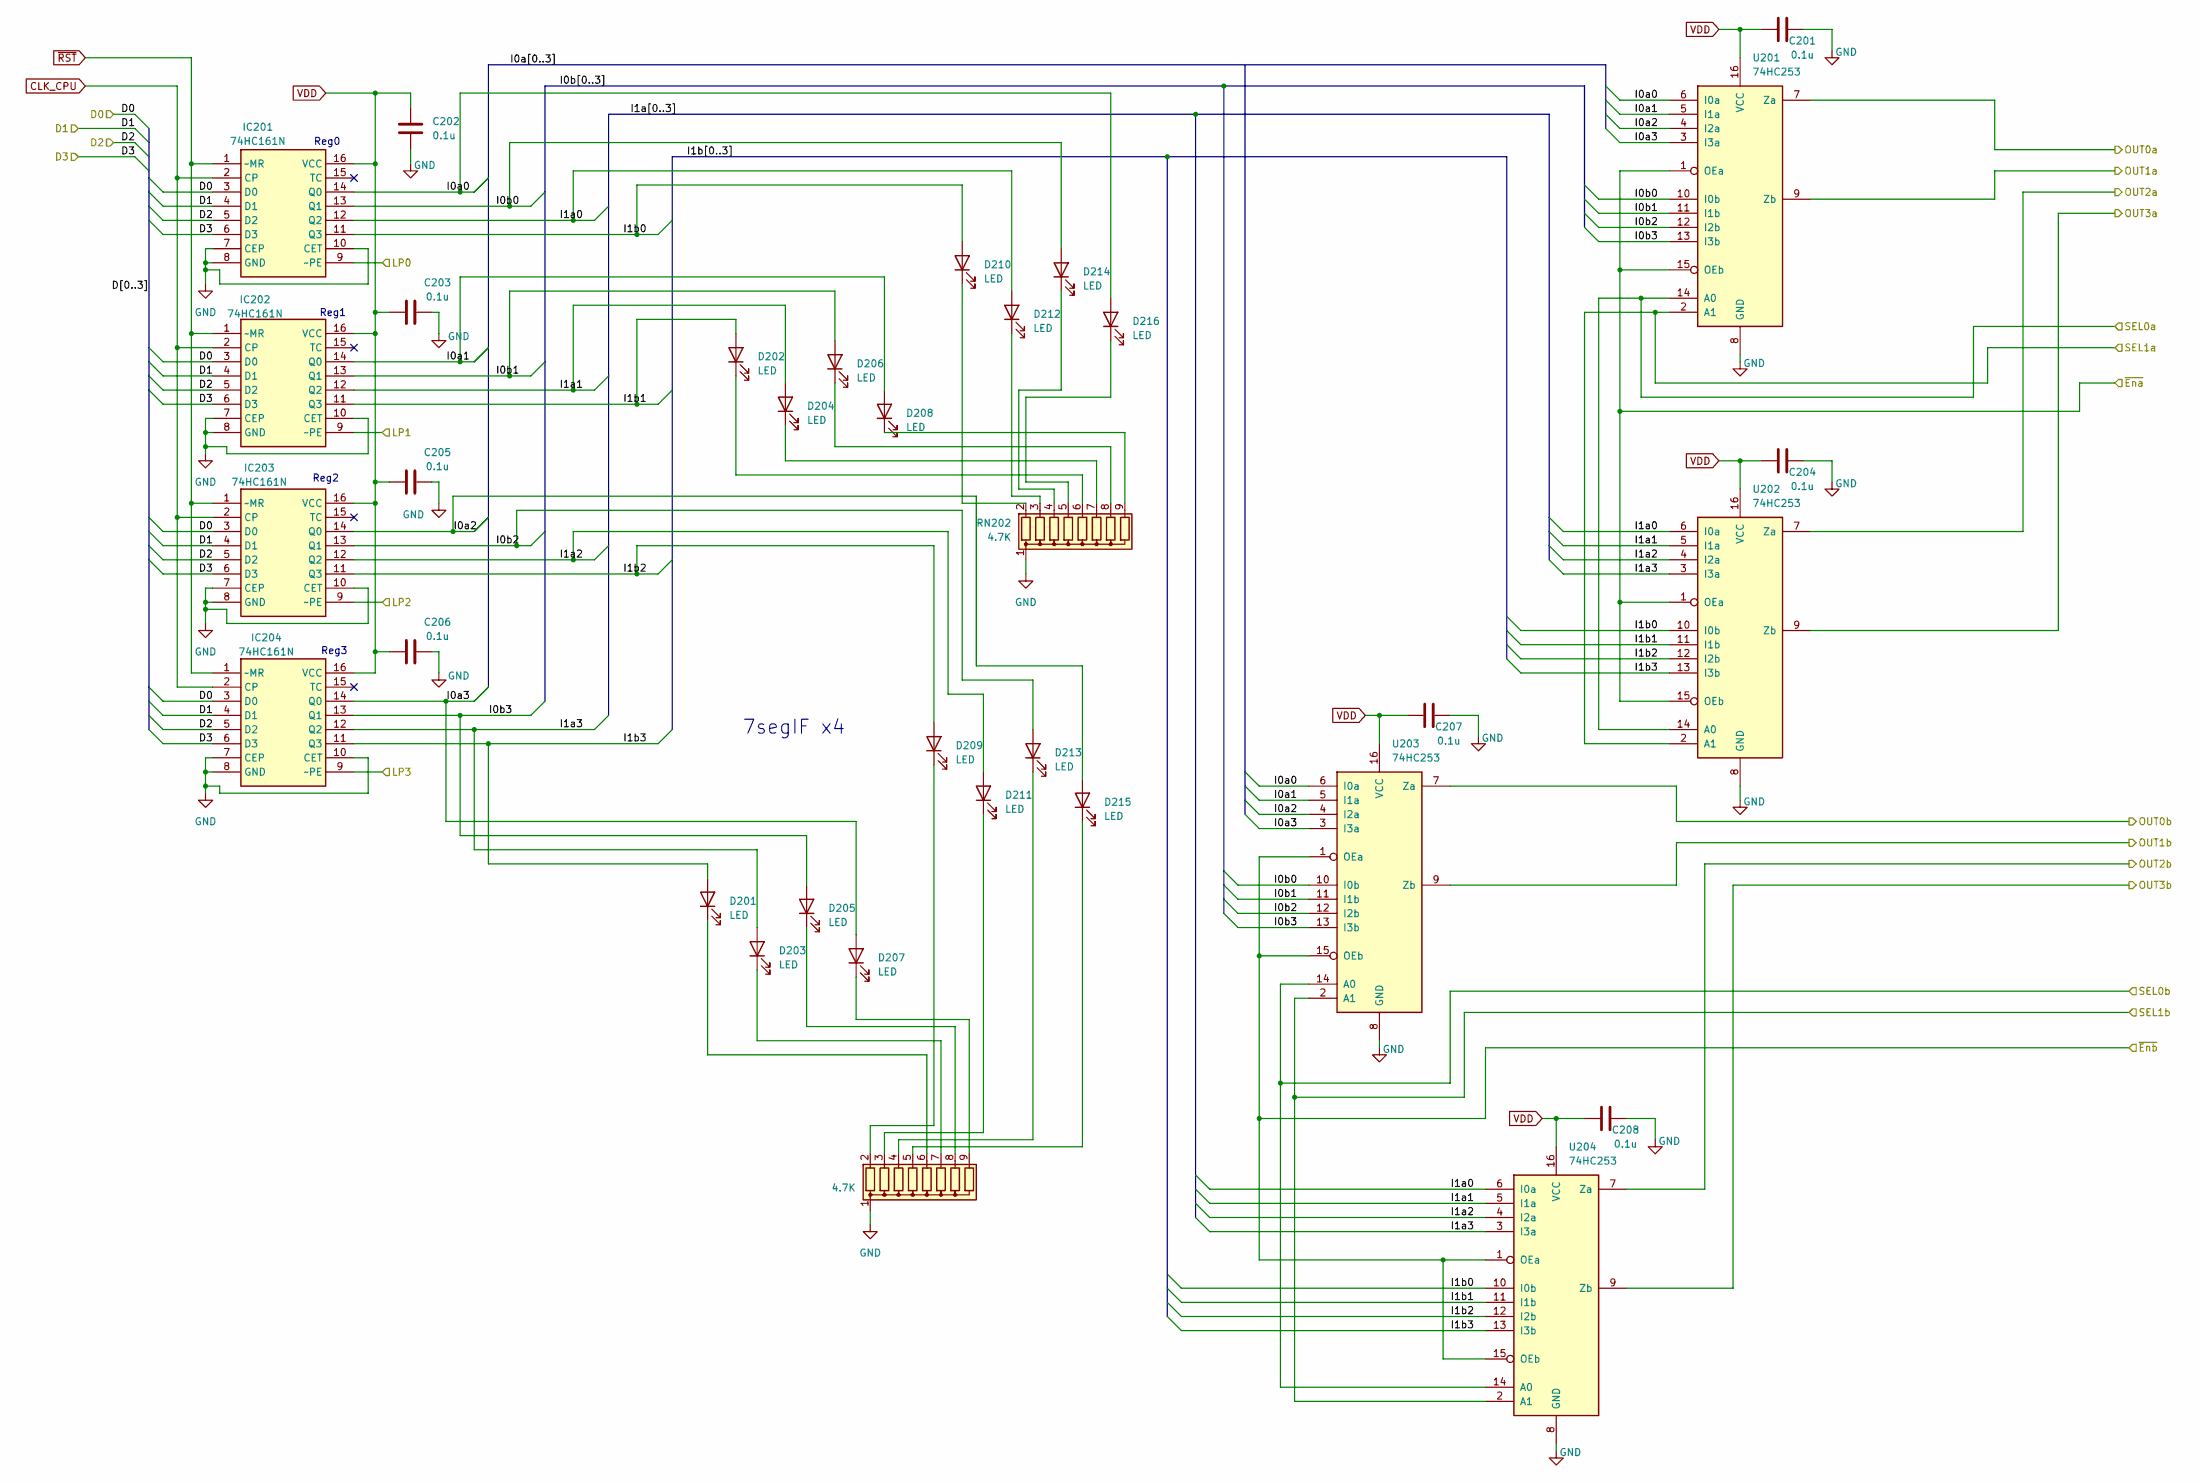
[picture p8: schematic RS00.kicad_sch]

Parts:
C201, C202, C203, C204, C205, C206, C207, C208: 0.1u; C_Disc_D4.3mm_W1.9mm_P5.00mm
D201, D202, D203, D204, D205, D206, D207, D208, D209, D210, D211, D212, D213, D214, D215, D216: LED; LED_D3.0mm_Clear
IC201, IC202, IC203, IC204: 74HC161N; DIP-16_W7.62mm_Socket; Manufacturer_Part_Number 74HC161N
RN201, RN202: 4.7K; R_Array_SIP9
U201, U202, U203, U204: 74HC253; DIP-16_W7.62mm_Socket

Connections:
/RS00/I0a0: D216.2 (A), IC201.14 (Q0), U201.6 (I0a), U203.6 (I0a)
/RS00/I0a1: D208.2 (A), IC202.14 (Q0), U201.5 (I1a), U203.5 (I1a)
/RS00/I0a2: D215.2 (A), IC203.14 (Q0), U201.4 (I2a), U203.4 (I2a)
/RS00/I0a3: D207.2 (A), IC204.14 (Q0), U201.3 (I3a), U203.3 (I3a)
/RS00/I0b0: D214.2 (A), IC201.13 (Q1), U201.10 (I0b), U203.10 (I0b)
/RS00/I0b1: D206.2 (A), IC202.13 (Q1), U201.11 (I1b), U203.11 (I1b)
/RS00/I0b2: D213.2 (A), IC203.13 (Q1), U201.12 (I2b), U203.12 (I2b)
/RS00/I0b3: D205.2 (A), IC204.13 (Q1), U201.13 (I3b), U203.13 (I3b)
/RS00/I1a0: D212.2 (A), IC201.12 (Q2), U202.6 (I0a), U204.6 (I0a)
/RS00/I1a1: D204.2 (A), IC202.12 (Q2), U202.5 (I1a), U204.5 (I1a)
/RS00/I1a2: D211.2 (A), IC203.12 (Q2), U202.4 (I2a), U204.4 (I2a)
/RS00/I1a3: D203.2 (A), IC204.12 (Q2), U202.3 (I3a), U204.3 (I3a)
/RS00/I1b0: D210.2 (A), IC201.11 (Q3), U202.10 (I0b), U204.10 (I0b)
/RS00/I1b1: D202.2 (A), IC202.11 (Q3), U202.11 (I1b), U204.11 (I1b)
/RS00/I1b2: D209.2 (A), IC203.11 (Q3), U202.12 (I2b), U204.12 (I2b)
/RS00/I1b3: D201.2 (A), IC204.11 (Q3), U202.13 (I3b), U204.13 (I3b)
CLK_CPU: IC201.2 (CP), IC202.2 (CP), IC203.2 (CP), IC204.2 (CP); also elsewhere on the board
DI0: IC201.3 (D0), IC202.3 (D0), IC203.3 (D0), IC204.3 (D0); also elsewhere on the board
DI1: IC201.4 (D1), IC202.4 (D1), IC203.4 (D1), IC204.4 (D1); also elsewhere on the board
DI2: IC201.5 (D2), IC202.5 (D2), IC203.5 (D2), IC204.5 (D2); also elsewhere on the board
DI3: IC201.6 (D3), IC202.6 (D3), IC203.6 (D3), IC204.6 (D3); also elsewhere on the board
DOa0: U201.7 (Za); also elsewhere on the board
DOa1: U201.9 (Zb); also elsewhere on the board
DOa2: U202.7 (Za); also elsewhere on the board
DOa3: U202.9 (Zb); also elsewhere on the board
DOb0: U203.7 (Za); also elsewhere on the board
DOb1: U203.9 (Zb); also elsewhere on the board
DOb2: U204.7 (Za); also elsewhere on the board
DOb3: U204.9 (Zb); also elsewhere on the board
GND: C201.1, C202.1, C203.1, C204.1, C205.1, C206.1, C207.1, C208.1, IC201.7 (CEP), IC201.8 (GND), IC201.10 (CET), IC202.7 (CEP), IC202.8 (GND), IC202.10 (CET), IC203.7 (CEP), IC203.8 (GND), IC203.10 (CET), IC204.7 (CEP), IC204.8 (GND), IC204.10 (CET), RN201.1 (common), RN202.1 (common), U201.8 (GND), U202.8 (GND), U203.8 (GND), U204.8 (GND); also elsewhere on the board
unnamed: D201.1 (K), RN201.6 (R5)
unnamed: D202.1 (K), RN202.6 (R5)
unnamed: D203.1 (K), RN201.7 (R6)
unnamed: D204.1 (K), RN202.7 (R6)
unnamed: D205.1 (K), RN201.8 (R7)
unnamed: D206.1 (K), RN202.8 (R7)
unnamed: D207.1 (K), RN201.9 (R8)
unnamed: D208.1 (K), RN202.9 (R8)
unnamed: D209.1 (K), RN201.2 (R1)
unnamed: D210.1 (K), RN202.2 (R1)
unnamed: D211.1 (K), RN201.3 (R2)
unnamed: D212.1 (K), RN202.3 (R2)
unnamed: D213.1 (K), RN201.4 (R3)
unnamed: D214.1 (K), RN202.4 (R3)
unnamed: D215.1 (K), RN201.5 (R4)
unnamed: D216.1 (K), RN202.5 (R4)
OPR4: U203.14 (A0), U204.14 (A0); also elsewhere on the board
OPR5: U203.2 (A1), U204.2 (A1); also elsewhere on the board
OPR6: U203.1 (OEa), U203.15 (OEb), U204.1 (OEa), U204.15 (OEb); also elsewhere on the board
VDD: C201.2, C202.2, C203.2, C204.2, C205.2, C206.2, C207.2, C208.2, IC201.16 (VCC), IC202.16 (VCC), IC203.16 (VCC), IC204.16 (VCC), U201.16 (VCC), U202.16 (VCC), U203.16 (VCC), U204.16 (VCC); also elsewhere on the board
sel_a0: U201.14 (A0), U202.14 (A0); also elsewhere on the board
sel_a1: U201.2 (A1), U202.2 (A1); also elsewhere on the board
sel_a2: U201.1 (OEa), U201.15 (OEb), U202.1 (OEa), U202.15 (OEb); also elsewhere on the board
~RST: IC201.1 (~MR), IC202.1 (~MR), IC203.1 (~MR), IC204.1 (~MR); also elsewhere on the board
~Reg_WE0: IC201.9 (~PE); also elsewhere on the board
~Reg_WE1: IC202.9 (~PE); also elsewhere on the board
~Reg_WE2: IC203.9 (~PE); also elsewhere on the board
~Reg_WE3: IC204.9 (~PE); also elsewhere on the board

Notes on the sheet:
7segIF x4
Reg3
Reg2
Reg0
Reg1

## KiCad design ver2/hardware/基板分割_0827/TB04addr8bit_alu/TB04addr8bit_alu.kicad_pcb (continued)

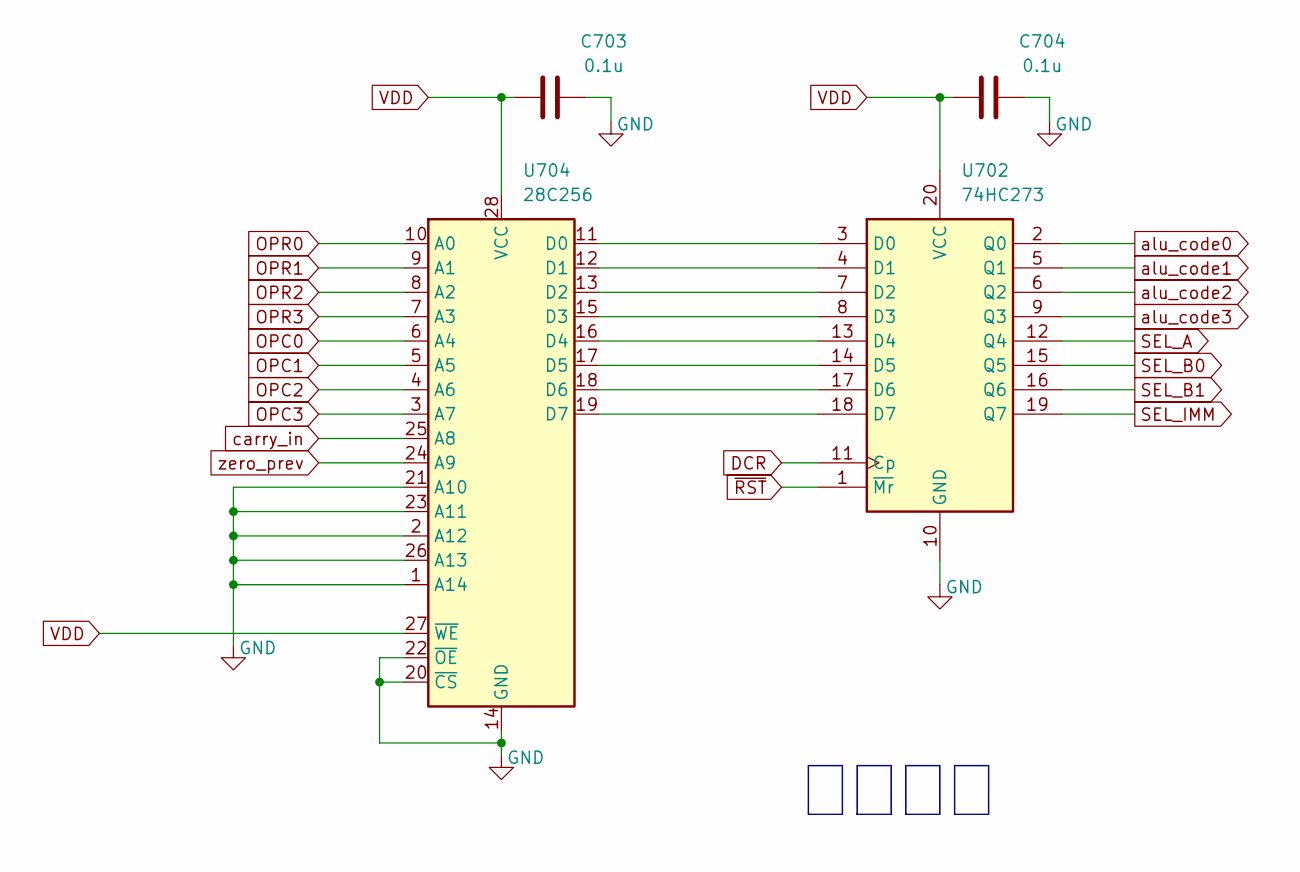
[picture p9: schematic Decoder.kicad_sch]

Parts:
C703, C704: 0.1u; C_Disc_D4.3mm_W1.9mm_P5.00mm
U702: 74HC273; DIP-20_W7.62mm_Socket
U704: 28C256; DIP-28_W15.24mm_Socket

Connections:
DCR: U702.11 (Cp); also elsewhere on the board
GND: C703.1, C704.1, U702.10 (GND), U704.1 (A14), U704.2 (A12), U704.14 (GND), U704.20 (~CS), U704.21 (A10), U704.22 (~OE), U704.23 (A11), U704.26 (A13); also elsewhere on the board
unnamed: U702.3 (D0), U704.11 (D0)
unnamed: U702.4 (D1), U704.12 (D1)
unnamed: U702.7 (D2), U704.13 (D2)
unnamed: U702.8 (D3), U704.15 (D3)
unnamed: U702.13 (D4), U704.16 (D4)
unnamed: U702.14 (D5), U704.17 (D5)
unnamed: U702.17 (D6), U704.18 (D6)
unnamed: U702.18 (D7), U704.19 (D7)
OPC0: U704.6 (A4); also elsewhere on the board
OPC1: U704.5 (A5); also elsewhere on the board
OPC2: U704.4 (A6); also elsewhere on the board
OPC3: U704.3 (A7); also elsewhere on the board
OPR0: U704.10 (A0); also elsewhere on the board
OPR1: U704.9 (A1); also elsewhere on the board
OPR2: U704.8 (A2); also elsewhere on the board
OPR3: U704.7 (A3); also elsewhere on the board
SEL_A: U702.12 (Q4); also elsewhere on the board
SEL_B0: U702.15 (Q5); also elsewhere on the board
SEL_B1: U702.16 (Q6); also elsewhere on the board
SEL_IMM: U702.19 (Q7); also elsewhere on the board
VDD: C703.2, C704.2, U702.20 (VCC), U704.27 (~WE), U704.28 (VCC); also elsewhere on the board
alu_code0: U702.2 (Q0); also elsewhere on the board
alu_code1: U702.5 (Q1); also elsewhere on the board
alu_code2: U702.6 (Q2); also elsewhere on the board
alu_code3: U702.9 (Q3); also elsewhere on the board
carry_in: U704.25 (A8); also elsewhere on the board
zero_prev: U704.24 (A9); also elsewhere on the board
~RST: U702.1 (~Mr); also elsewhere on the board

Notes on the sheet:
デコーダ

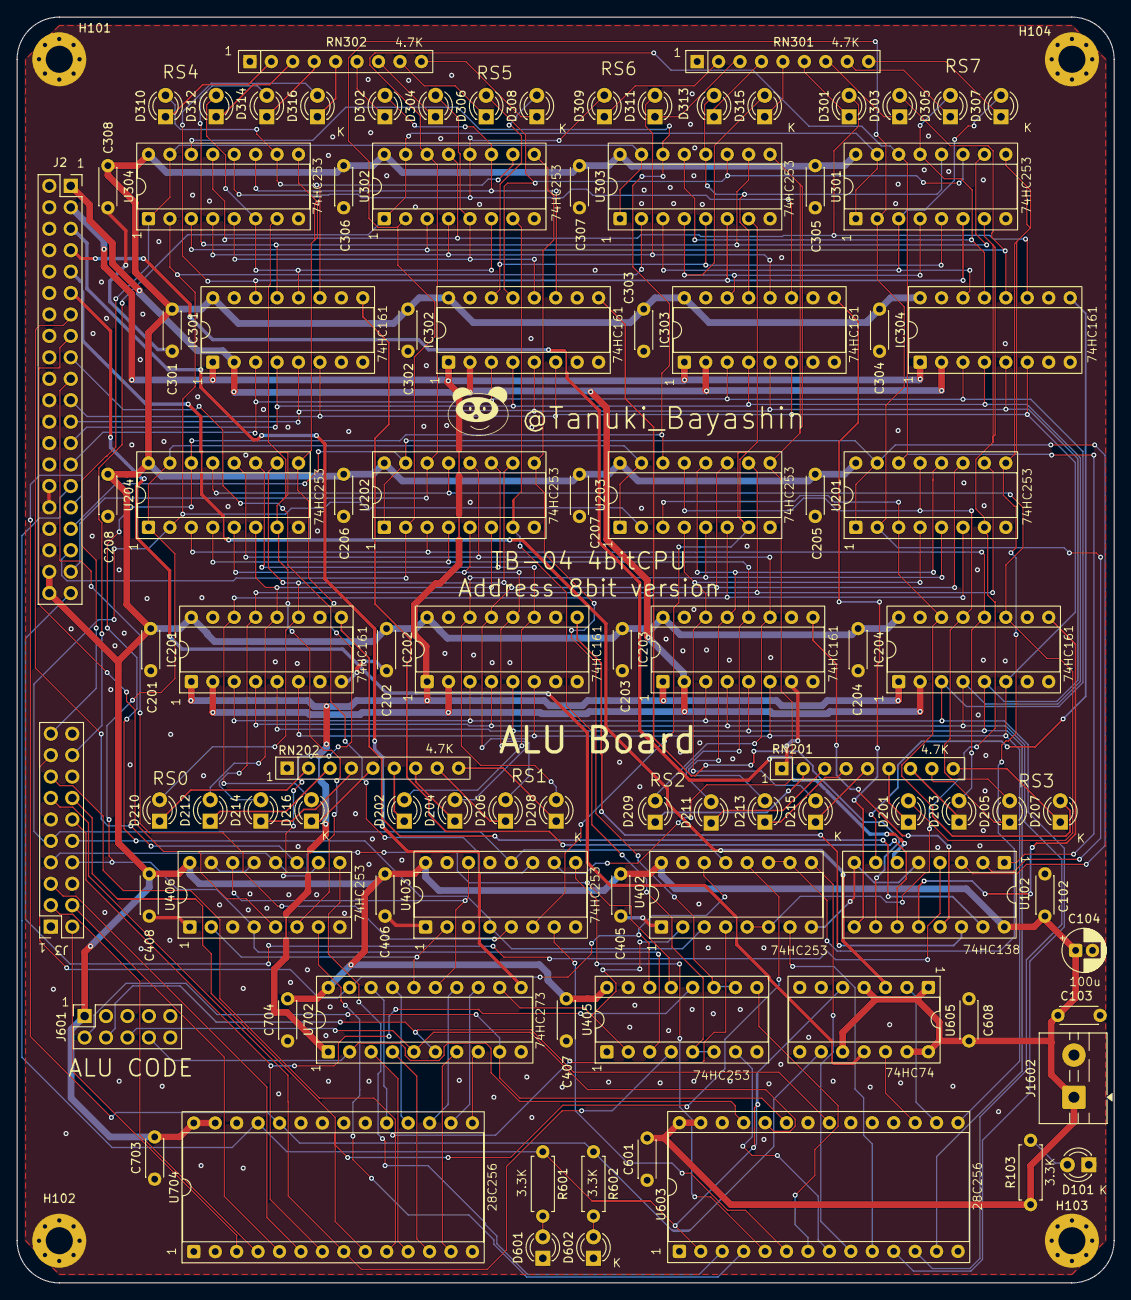
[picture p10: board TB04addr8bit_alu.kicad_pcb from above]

Board: 2 copper layers, 130.0 x 150.0 mm, 102 parts (0 on the bottom side), 145 nets.

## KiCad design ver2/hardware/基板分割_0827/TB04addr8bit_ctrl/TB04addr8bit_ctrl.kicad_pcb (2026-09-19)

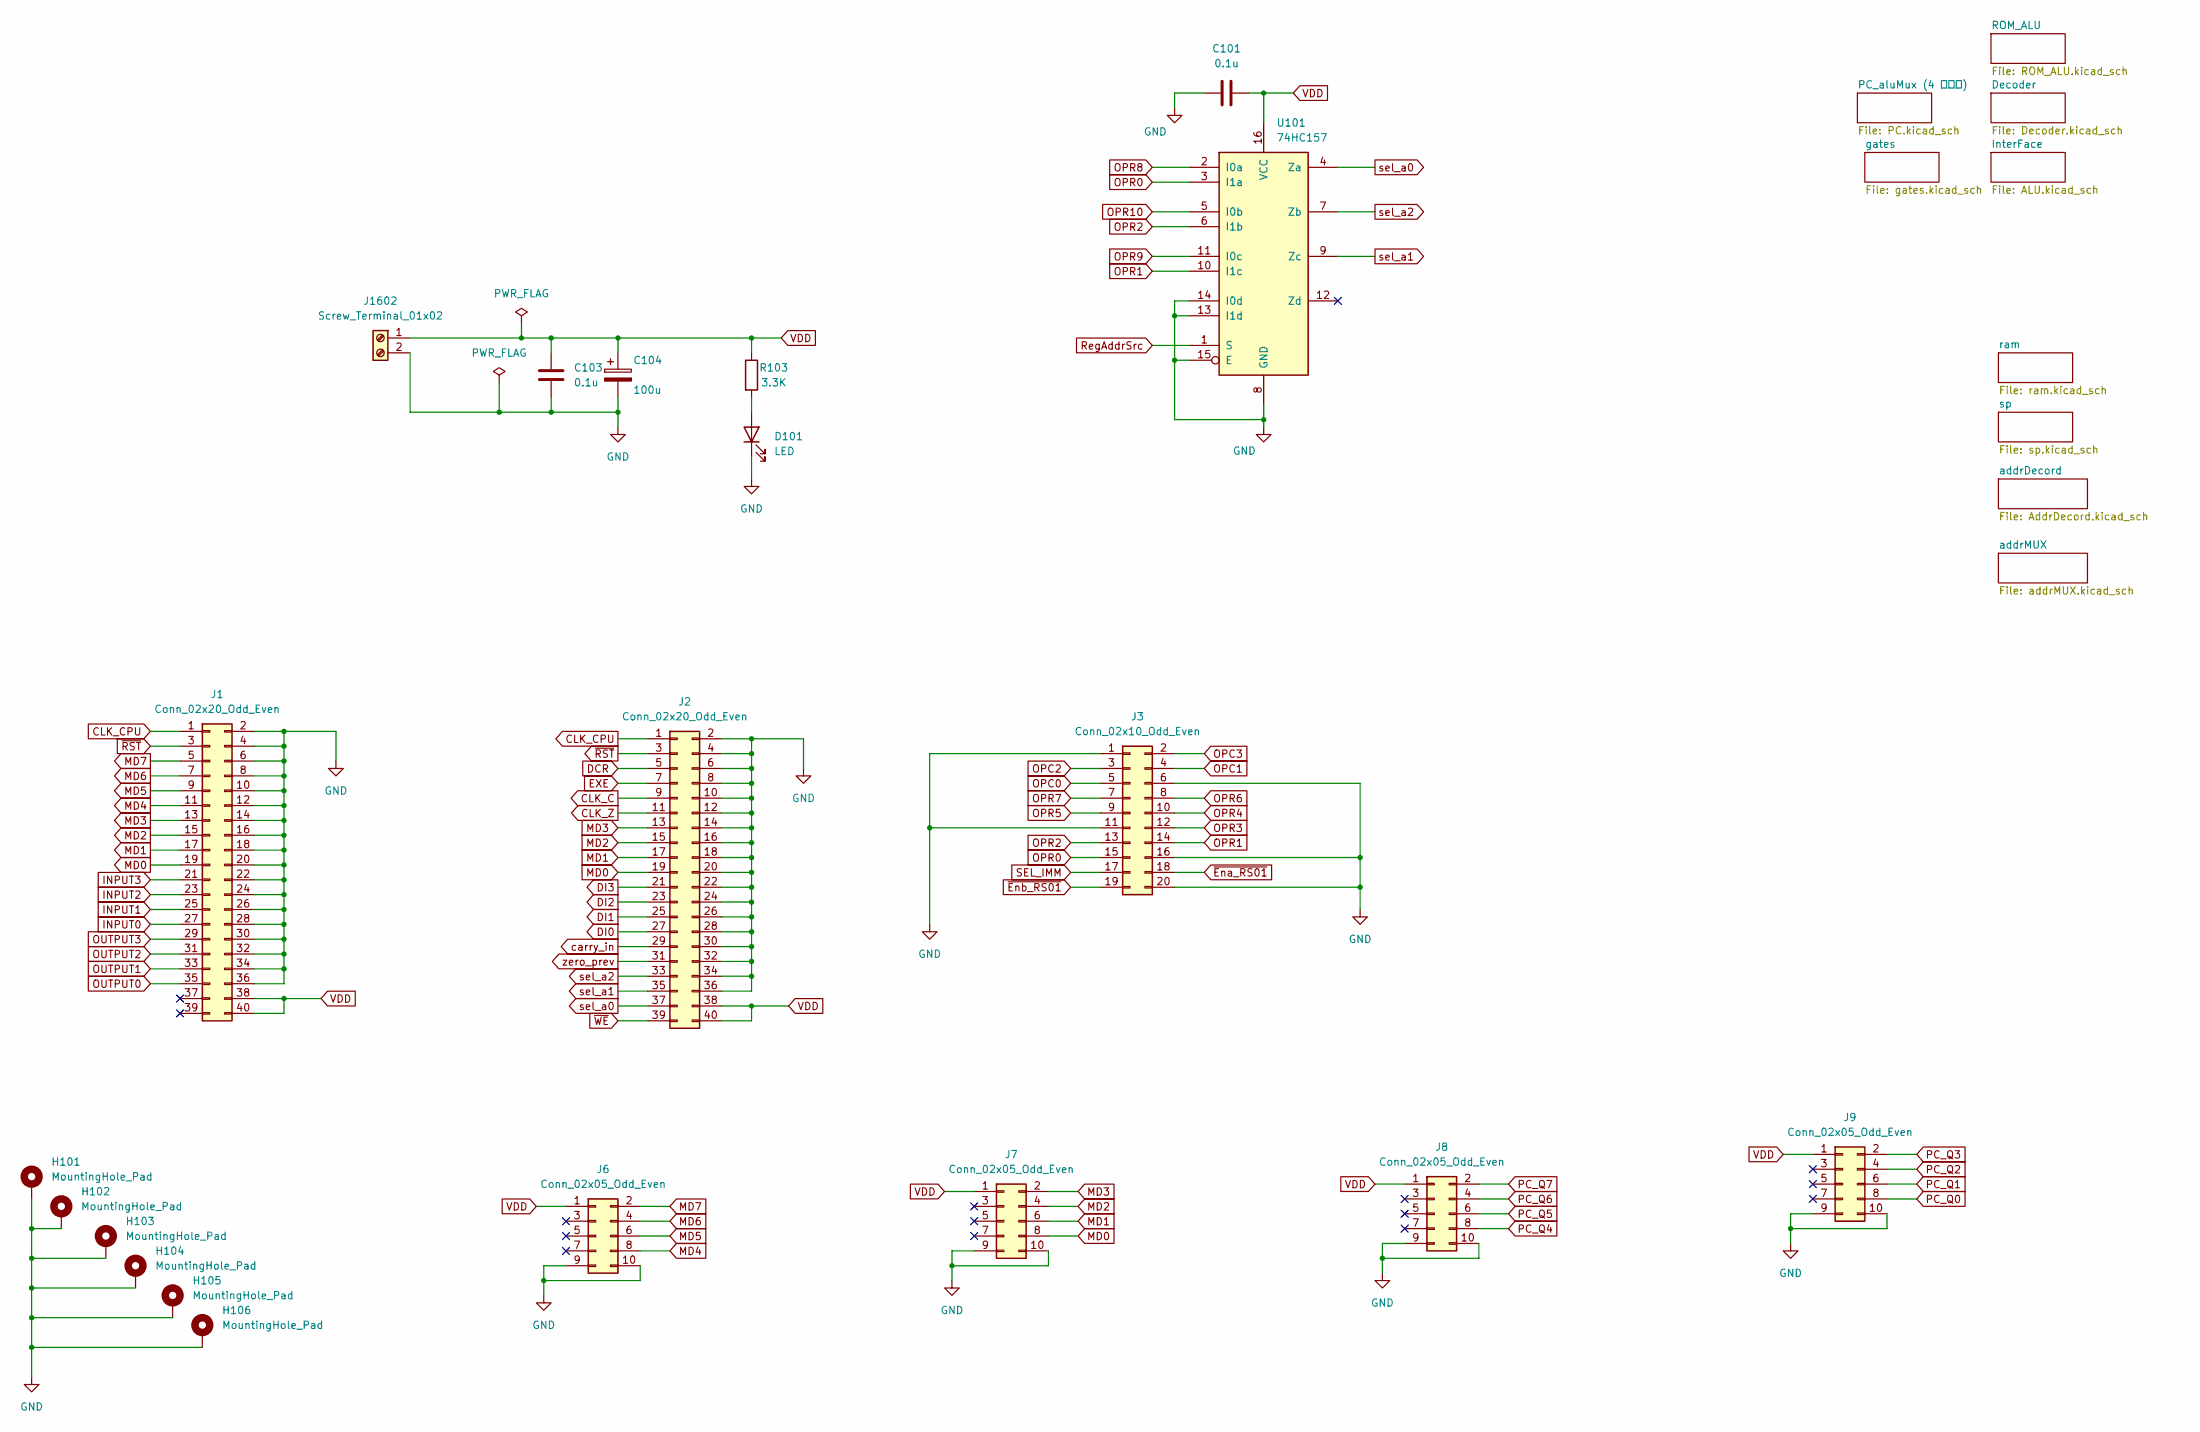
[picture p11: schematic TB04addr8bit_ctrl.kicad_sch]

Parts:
C101, C103: 0.1u; C_Disc_D4.3mm_W1.9mm_P5.00mm
C104: 100u; CP_Radial_D5.0mm_P2.00mm
D101: LED; LED_D3.0mm_Clear
H101, H102, H103, H104, H105, H106: MountingHole_Pad; MountingHole_3.2mm_M3_Pad_Via
J1, J2: Conn_02x20_Odd_Even; PinSocket_2x20_P2.54mm_Vertical
J3: Conn_02x10_Odd_Even; PinSocket_2x10_P2.54mm_Vertical
J6, J7, J8, J9: Conn_02x05_Odd_Even; PinSocket_2x05_P2.54mm_Vertical
J1602: Screw_Terminal_01x02; TerminalBlock_MaiXu_MX126-5.0-02P_1x02_P5.00mm
R103: 3.3K; R_Axial_DIN0207_L6.3mm_D2.5mm_P7.62mm_Horizontal
U101: 74HC157; DIP-16_W7.62mm_Socket

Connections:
CLK_C: J2.9; also elsewhere on the board
CLK_CPU: J1.1, J2.1; also elsewhere on the board
CLK_Z: J2.11; also elsewhere on the board
DCR: J2.5; also elsewhere on the board
DI0: J2.27; also elsewhere on the board
DI1: J2.25; also elsewhere on the board
DI2: J2.23; also elsewhere on the board
DI3: J2.21; also elsewhere on the board
EXE: J2.7; also elsewhere on the board
GND: C101.2, C103.2, C104.2, D101.1 (K), H101.1 (1_1), H102.1 (1_1), H103.1 (1_1), H104.1 (1_1), H105.1 (1_1), H106.1 (1_1), J1.2, J1.4, J1.6, J1.8, J1.10, J1.12, J1.14, J1.16, J1.18, J1.20, J1.22, J1.24, J1.26, J1.28, J1.30, J1.32, J1.34, J1.36, J2.2, J2.4, J2.6, J2.8, J2.10, J2.12, J2.14, J2.16, J2.18, J2.20, J2.22, J2.24, J2.26, J2.28, J2.30, J2.32, J2.34, J2.36, J3.1, J3.6, J3.11, J3.16, J3.20, J6.9, J6.10, J7.9, J7.10, J8.9, J8.10, J9.9, J9.10, J1602.2, U101.8 (GND), U101.13 (I1d), U101.14 (I0d), U101.15 (E); also elsewhere on the board
INPUT0: J1.27; also elsewhere on the board
INPUT1: J1.25; also elsewhere on the board
INPUT2: J1.23; also elsewhere on the board
INPUT3: J1.21; also elsewhere on the board
MD0: J1.19, J2.19, J7.8; also elsewhere on the board
MD1: J1.17, J2.17, J7.6; also elsewhere on the board
MD2: J1.15, J2.15, J7.4; also elsewhere on the board
MD3: J1.13, J2.13, J7.2; also elsewhere on the board
MD4: J1.11, J6.8; also elsewhere on the board
MD5: J1.9, J6.6; also elsewhere on the board
MD6: J1.7, J6.4; also elsewhere on the board
MD7: J1.5, J6.2; also elsewhere on the board
unnamed: D101.2 (A), R103.2
OPC0: J3.5; also elsewhere on the board
OPC1: J3.4; also elsewhere on the board
OPC2: J3.3; also elsewhere on the board
OPC3: J3.2; also elsewhere on the board
OPR0: J3.15, U101.3 (I1a); also elsewhere on the board
OPR1: J3.14, U101.10 (I1c); also elsewhere on the board
OPR2: J3.13, U101.6 (I1b); also elsewhere on the board
OPR3: J3.12; also elsewhere on the board
OPR4: J3.10; also elsewhere on the board
OPR5: J3.9; also elsewhere on the board
OPR6: J3.8; also elsewhere on the board
OPR7: J3.7; also elsewhere on the board
OPR8: U101.2 (I0a); also elsewhere on the board
OPR9: U101.11 (I0c); also elsewhere on the board
OPR10: U101.5 (I0b); also elsewhere on the board
OUTPUT0: J1.35; also elsewhere on the board
OUTPUT1: J1.33; also elsewhere on the board
OUTPUT2: J1.31; also elsewhere on the board
OUTPUT3: J1.29; also elsewhere on the board
PC_Q0: J9.8; also elsewhere on the board
PC_Q1: J9.6; also elsewhere on the board
PC_Q2: J9.4; also elsewhere on the board
PC_Q3: J9.2; also elsewhere on the board
PC_Q4: J8.8; also elsewhere on the board
PC_Q5: J8.6; also elsewhere on the board
PC_Q6: J8.4; also elsewhere on the board
PC_Q7: J8.2; also elsewhere on the board
RegAddrSrc: U101.1 (S); also elsewhere on the board
SEL_IMM: J3.17; also elsewhere on the board
VDD: C101.1, C103.1, C104.1, J1.38, J1.40, J2.38, J2.40, J6.1, J7.1, J8.1, J9.1, J1602.1, R103.1, U101.16 (VCC); also elsewhere on the board
carry_in: J2.29; also elsewhere on the board
sel_a0: J2.37, U101.4 (Za)
sel_a1: J2.35, U101.9 (Zc)
sel_a2: J2.33, U101.7 (Zb); also elsewhere on the board
zero_prev: J2.31; also elsewhere on the board
~Ena_RS01: J3.18; also elsewhere on the board
~Enb_RS01: J3.19; also elsewhere on the board
~RST: J1.3, J2.3; also elsewhere on the board
~WE: J2.39; also elsewhere on the board

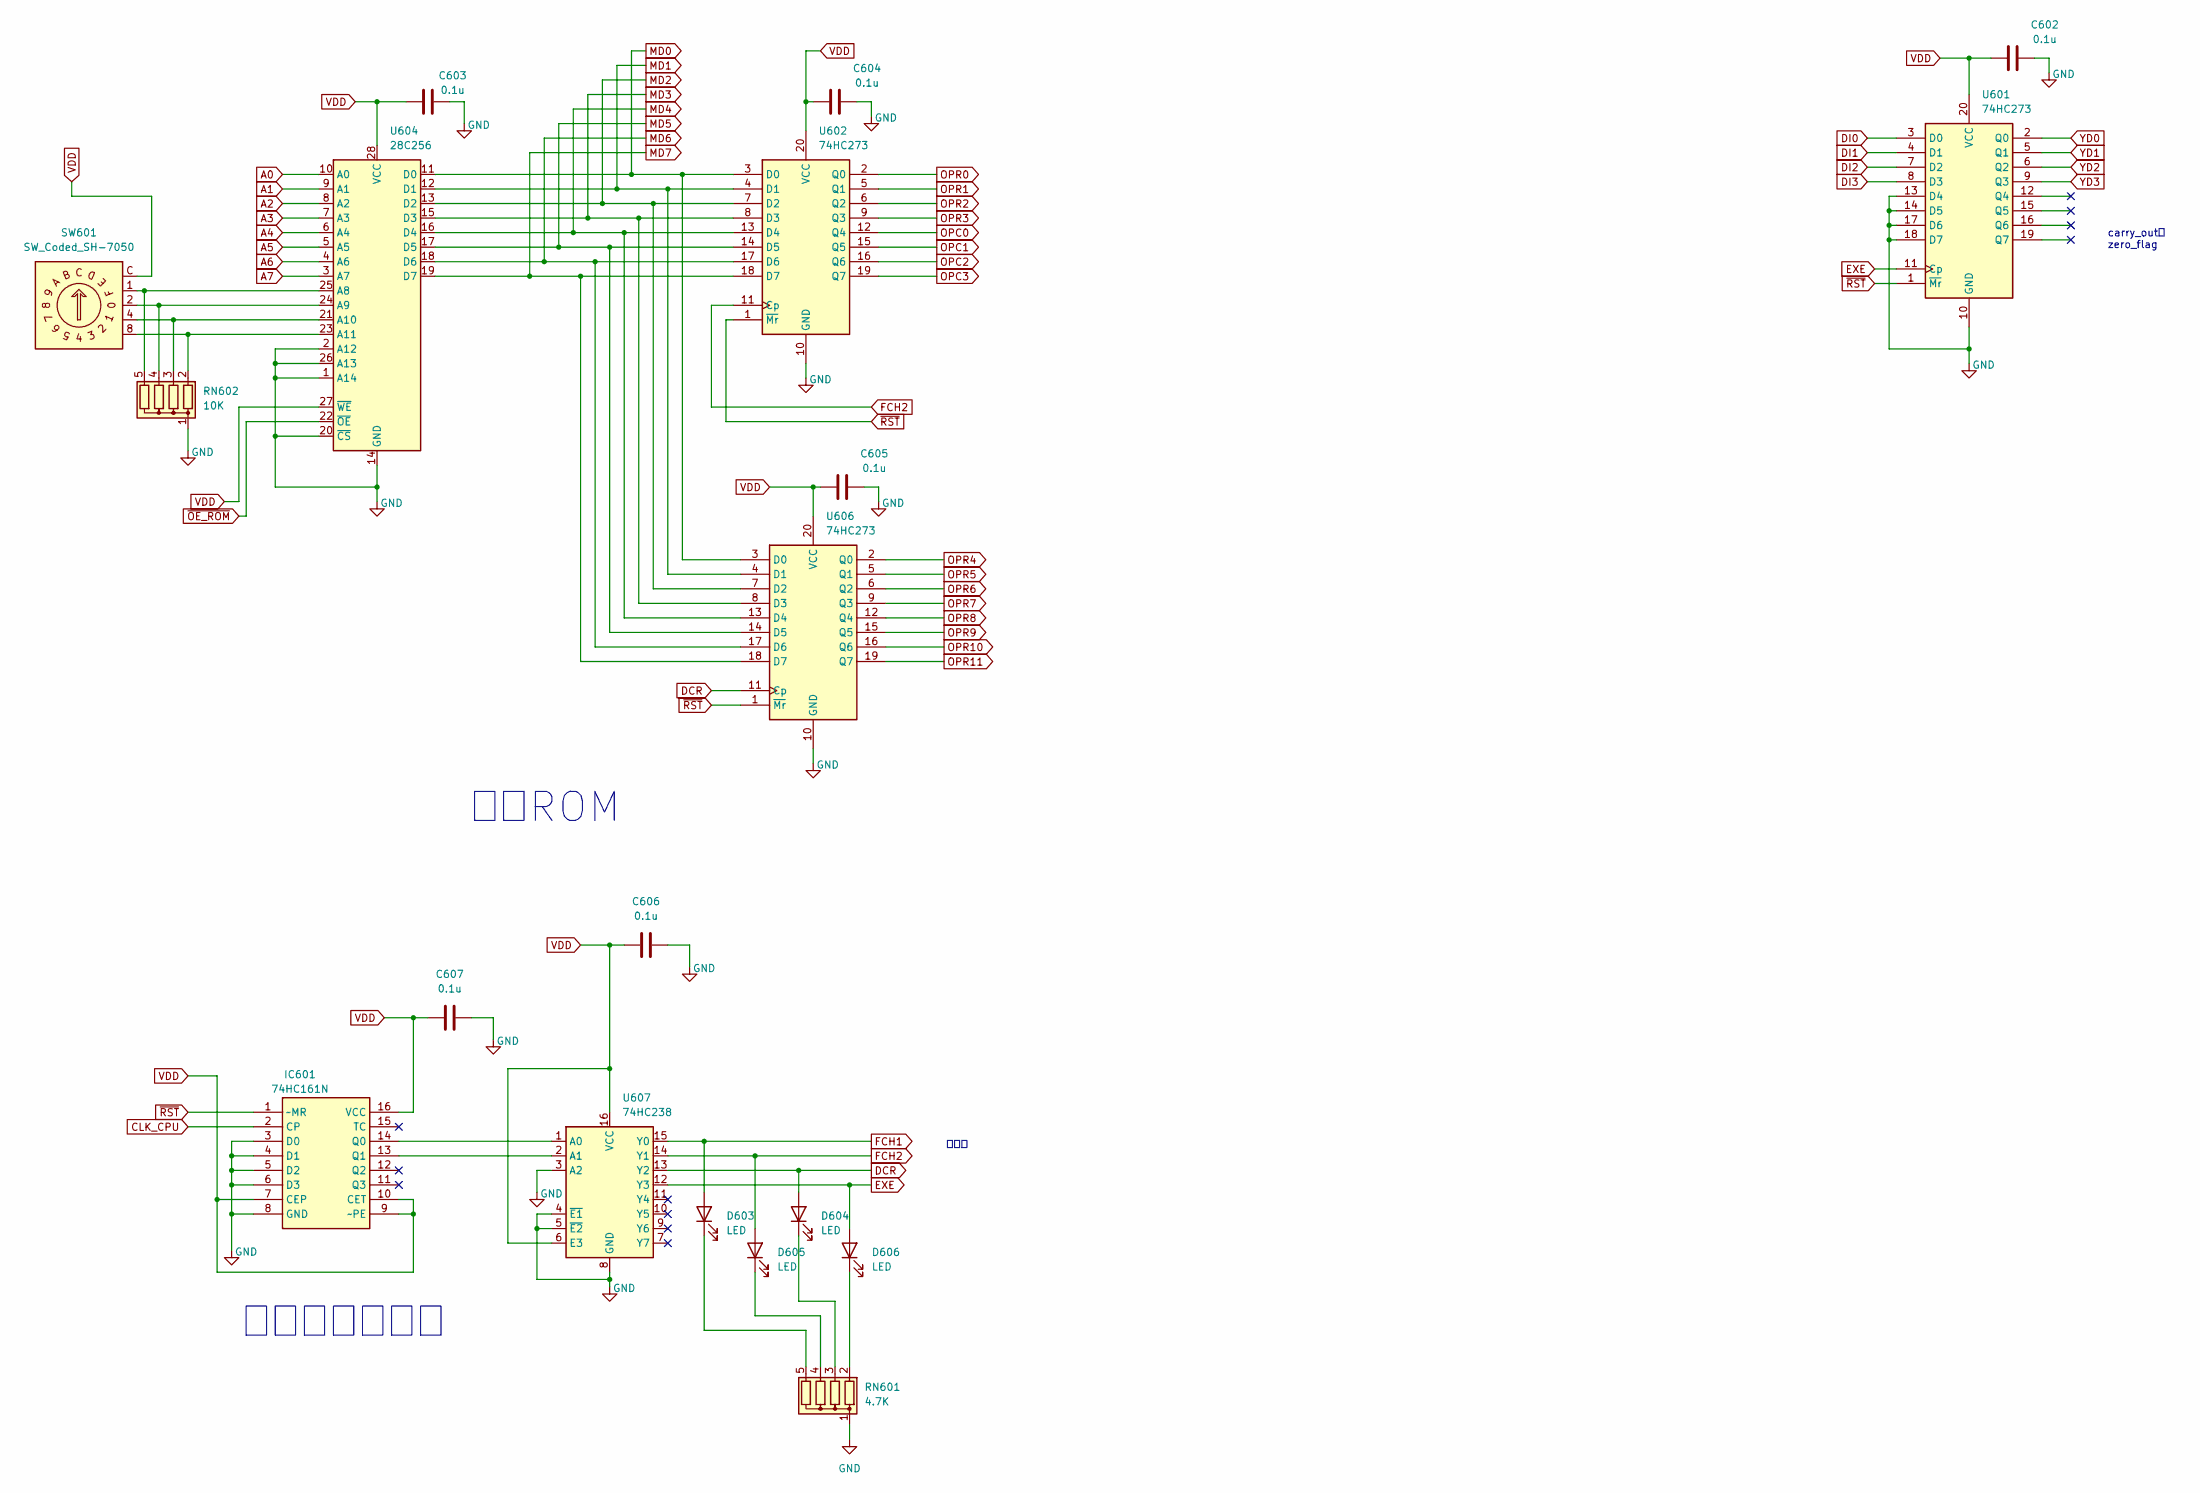
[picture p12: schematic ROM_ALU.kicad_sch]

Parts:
C602, C603, C604, C605, C606, C607: 0.1u; C_Disc_D4.3mm_W1.9mm_P5.00mm
D603, D604, D605, D606: LED; LED_D3.0mm_Clear
IC601: 74HC161N; DIP-16_W7.62mm_Socket; Manufacturer_Part_Number 74HC161N
RN601: 4.7K; R_Array_SIP5
RN602: 10K; R_Array_SIP5
SW601: SW_Coded_SH-7050; dip_rotary_sw
U601, U602, U606: 74HC273; DIP-20_W7.62mm_Socket
U604: 28C256; DIP_Socket-28_W11.9mm_W12.7mm_W15.24mm_W17.78mm_W18.5mm_3M_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
U607: 74HC238; DIP-16_W7.62mm_Socket

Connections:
A0: U604.10 (A0); also elsewhere on the board
A1: U604.9 (A1); also elsewhere on the board
A2: U604.8 (A2); also elsewhere on the board
A3: U604.7 (A3); also elsewhere on the board
A4: U604.6 (A4); also elsewhere on the board
A5: U604.5 (A5); also elsewhere on the board
A6: U604.4 (A6); also elsewhere on the board
A7: U604.3 (A7); also elsewhere on the board
CLK_CPU: IC601.2 (CP); also elsewhere on the board
DCR: D604.2 (A), U606.11 (Cp), U607.13 (Y2); also elsewhere on the board
DI0: U601.3 (D0); also elsewhere on the board
DI1: U601.4 (D1); also elsewhere on the board
DI2: U601.7 (D2); also elsewhere on the board
DI3: U601.8 (D3); also elsewhere on the board
EXE: D606.2 (A), U601.11 (Cp), U607.12 (Y3); also elsewhere on the board
FCH1: D603.2 (A), U607.15 (Y0); also elsewhere on the board
FCH2: D605.2 (A), U602.11 (Cp), U607.14 (Y1); also elsewhere on the board
GND: C602.1, C603.1, C604.1, C605.1, C606.2, C607.2, IC601.3 (D0), IC601.4 (D1), IC601.5 (D2), IC601.6 (D3), IC601.8 (GND), RN601.1 (common), RN602.1 (common), U601.10 (GND), U601.13 (D4), U601.14 (D5), U601.17 (D6), U601.18 (D7), U602.10 (GND), U604.1 (A14), U604.2 (A12), U604.14 (GND), U604.20 (~CS), U604.26 (A13), U606.10 (GND), U607.3 (A2), U607.4 (~E1), U607.5 (~E2), U607.8 (GND); also elsewhere on the board
MD0: U602.3 (D0), U604.11 (D0), U606.3 (D0); also elsewhere on the board
MD1: U602.4 (D1), U604.12 (D1), U606.4 (D1); also elsewhere on the board
MD2: U602.7 (D2), U604.13 (D2), U606.7 (D2); also elsewhere on the board
MD3: U602.8 (D3), U604.15 (D3), U606.8 (D3); also elsewhere on the board
MD4: U602.13 (D4), U604.16 (D4), U606.13 (D4); also elsewhere on the board
MD5: U602.14 (D5), U604.17 (D5), U606.14 (D5); also elsewhere on the board
MD6: U602.17 (D6), U604.18 (D6), U606.17 (D6); also elsewhere on the board
MD7: U602.18 (D7), U604.19 (D7), U606.18 (D7); also elsewhere on the board
unnamed: D603.1 (K), RN601.5 (R4)
unnamed: D604.1 (K), RN601.3 (R2)
unnamed: D605.1 (K), RN601.4 (R3)
unnamed: D606.1 (K), RN601.2 (R1)
unnamed: IC601.14 (Q0), U607.1 (A0)
unnamed: IC601.13 (Q1), U607.2 (A1)
unnamed: RN602.2 (R1), SW601.8, U604.23 (A11)
unnamed: RN602.3 (R2), SW601.4, U604.21 (A10)
unnamed: RN602.4 (R3), SW601.2, U604.24 (A9)
unnamed: RN602.5 (R4), SW601.1, U604.25 (A8)
OPC0: U602.12 (Q4); also elsewhere on the board
OPC1: U602.15 (Q5); also elsewhere on the board
OPC2: U602.16 (Q6); also elsewhere on the board
OPC3: U602.19 (Q7); also elsewhere on the board
OPR0: U602.2 (Q0); also elsewhere on the board
OPR1: U602.5 (Q1); also elsewhere on the board
OPR2: U602.6 (Q2); also elsewhere on the board
OPR3: U602.9 (Q3); also elsewhere on the board
OPR4: U606.2 (Q0); also elsewhere on the board
OPR5: U606.5 (Q1); also elsewhere on the board
OPR6: U606.6 (Q2); also elsewhere on the board
OPR7: U606.9 (Q3); also elsewhere on the board
OPR8: U606.12 (Q4); also elsewhere on the board
OPR9: U606.15 (Q5); also elsewhere on the board
OPR10: U606.16 (Q6); also elsewhere on the board
OPR11: U606.19 (Q7); also elsewhere on the board
VDD: C602.2, C603.2, C604.2, C605.2, C606.1, C607.1, IC601.7 (CEP), IC601.9 (~PE), IC601.10 (CET), IC601.16 (VCC), SW601.C, U601.20 (VCC), U602.20 (VCC), U604.27 (~WE), U604.28 (VCC), U606.20 (VCC), U607.6 (E3), U607.16 (VCC); also elsewhere on the board
YD0: U601.2 (Q0); also elsewhere on the board
YD1: U601.5 (Q1); also elsewhere on the board
YD2: U601.6 (Q2); also elsewhere on the board
YD3: U601.9 (Q3); also elsewhere on the board
~OE_ROM: U604.22 (~OE); also elsewhere on the board
~RST: IC601.1 (~MR), U601.1 (~Mr), U602.1 (~Mr), U606.1 (~Mr); also elsewhere on the board

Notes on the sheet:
命令ROM
フェーズ発生器
正論理
carry_outと zero_flag

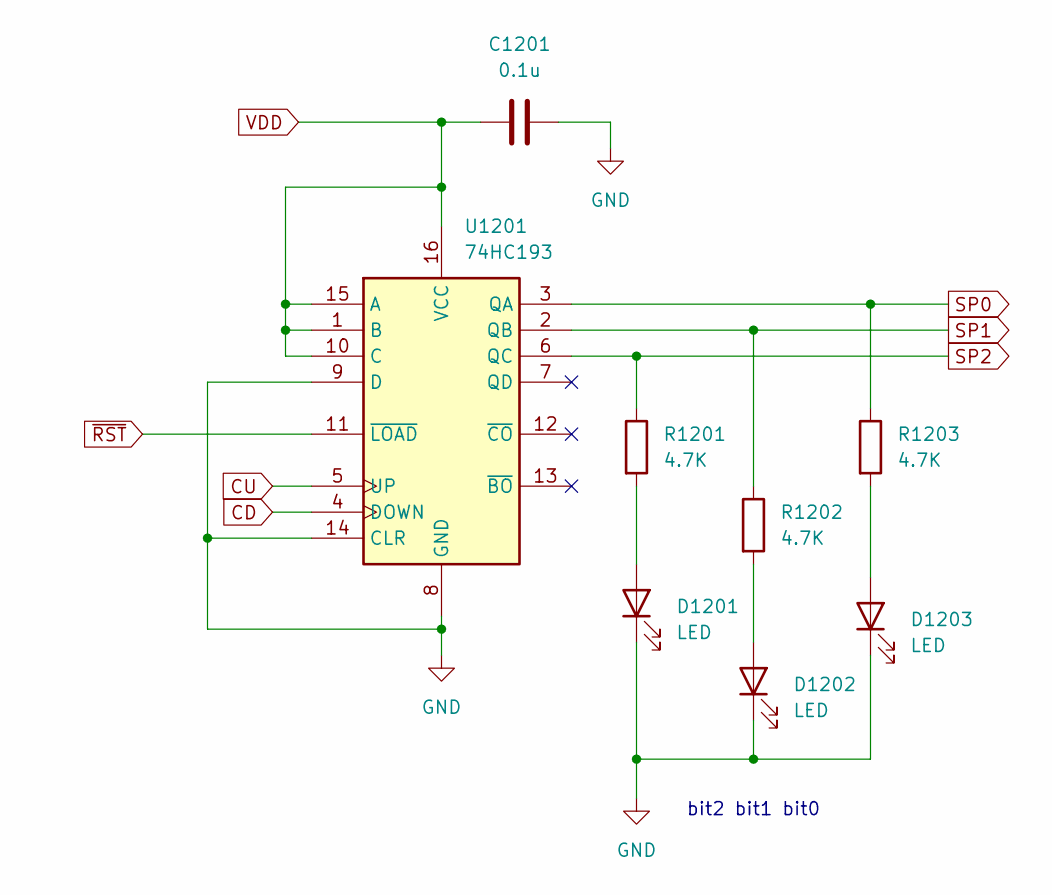
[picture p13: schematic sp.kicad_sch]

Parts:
C1201: 0.1u; C_Disc_D4.3mm_W1.9mm_P5.00mm
D1201, D1202, D1203: LED; LED_D3.0mm_Clear
R1201, R1202, R1203: 4.7K; R_Axial_DIN0207_L6.3mm_D2.5mm_P10.16mm_Horizontal
U1201: 74HC193; DIP-16_W7.62mm_Socket

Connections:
CD: U1201.4 (DOWN); also elsewhere on the board
CU: U1201.5 (UP); also elsewhere on the board
GND: C1201.2, D1201.1 (K), D1202.1 (K), D1203.1 (K), U1201.8 (GND), U1201.9 (D), U1201.14 (CLR); also elsewhere on the board
unnamed: D1201.2 (A), R1201.2
unnamed: D1202.2 (A), R1202.2
unnamed: D1203.2 (A), R1203.2
SP0: R1203.1, U1201.3 (QA); also elsewhere on the board
SP1: R1202.1, U1201.2 (QB); also elsewhere on the board
SP2: R1201.1, U1201.6 (QC); also elsewhere on the board
VDD: C1201.1, U1201.1 (B), U1201.10 (C), U1201.15 (A), U1201.16 (VCC); also elsewhere on the board
~RST: U1201.11 (~LOAD); also elsewhere on the board

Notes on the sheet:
bit2 bit1 bit0

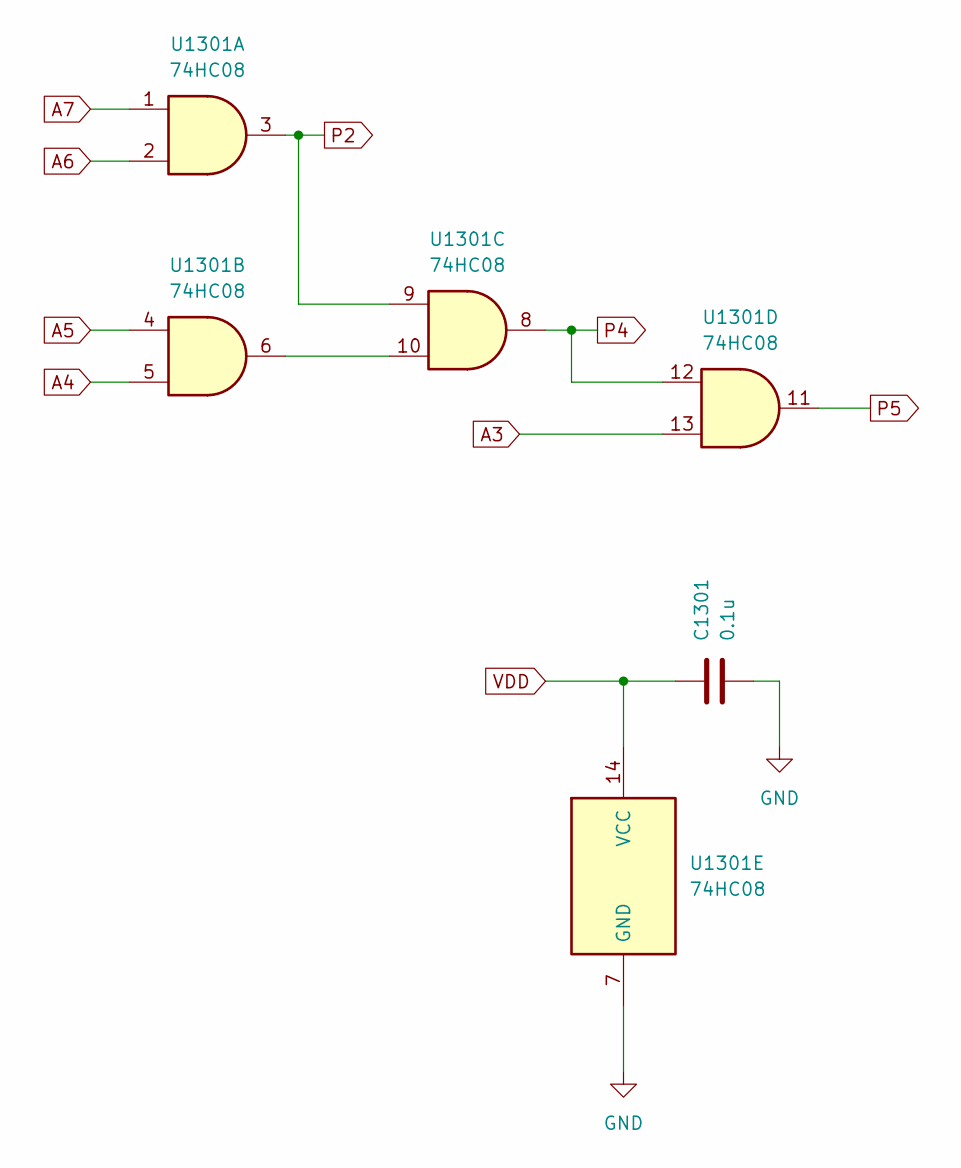
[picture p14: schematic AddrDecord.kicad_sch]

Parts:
C1301: 0.1u; C_Disc_D4.3mm_W1.9mm_P5.00mm
U1301: 74HC08; DIP-14_W7.62mm_Socket

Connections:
A3: U1301.13; also elsewhere on the board
A4: U1301.5; also elsewhere on the board
A5: U1301.4; also elsewhere on the board
A6: U1301.2; also elsewhere on the board
A7: U1301.1; also elsewhere on the board
GND: C1301.2, U1301.7 (GND); also elsewhere on the board
unnamed: U1301.6, U1301.10
P2: U1301.3, U1301.9; also elsewhere on the board
P4: U1301.8, U1301.12
P5: U1301.11; also elsewhere on the board
VDD: C1301.1, U1301.14 (VCC); also elsewhere on the board

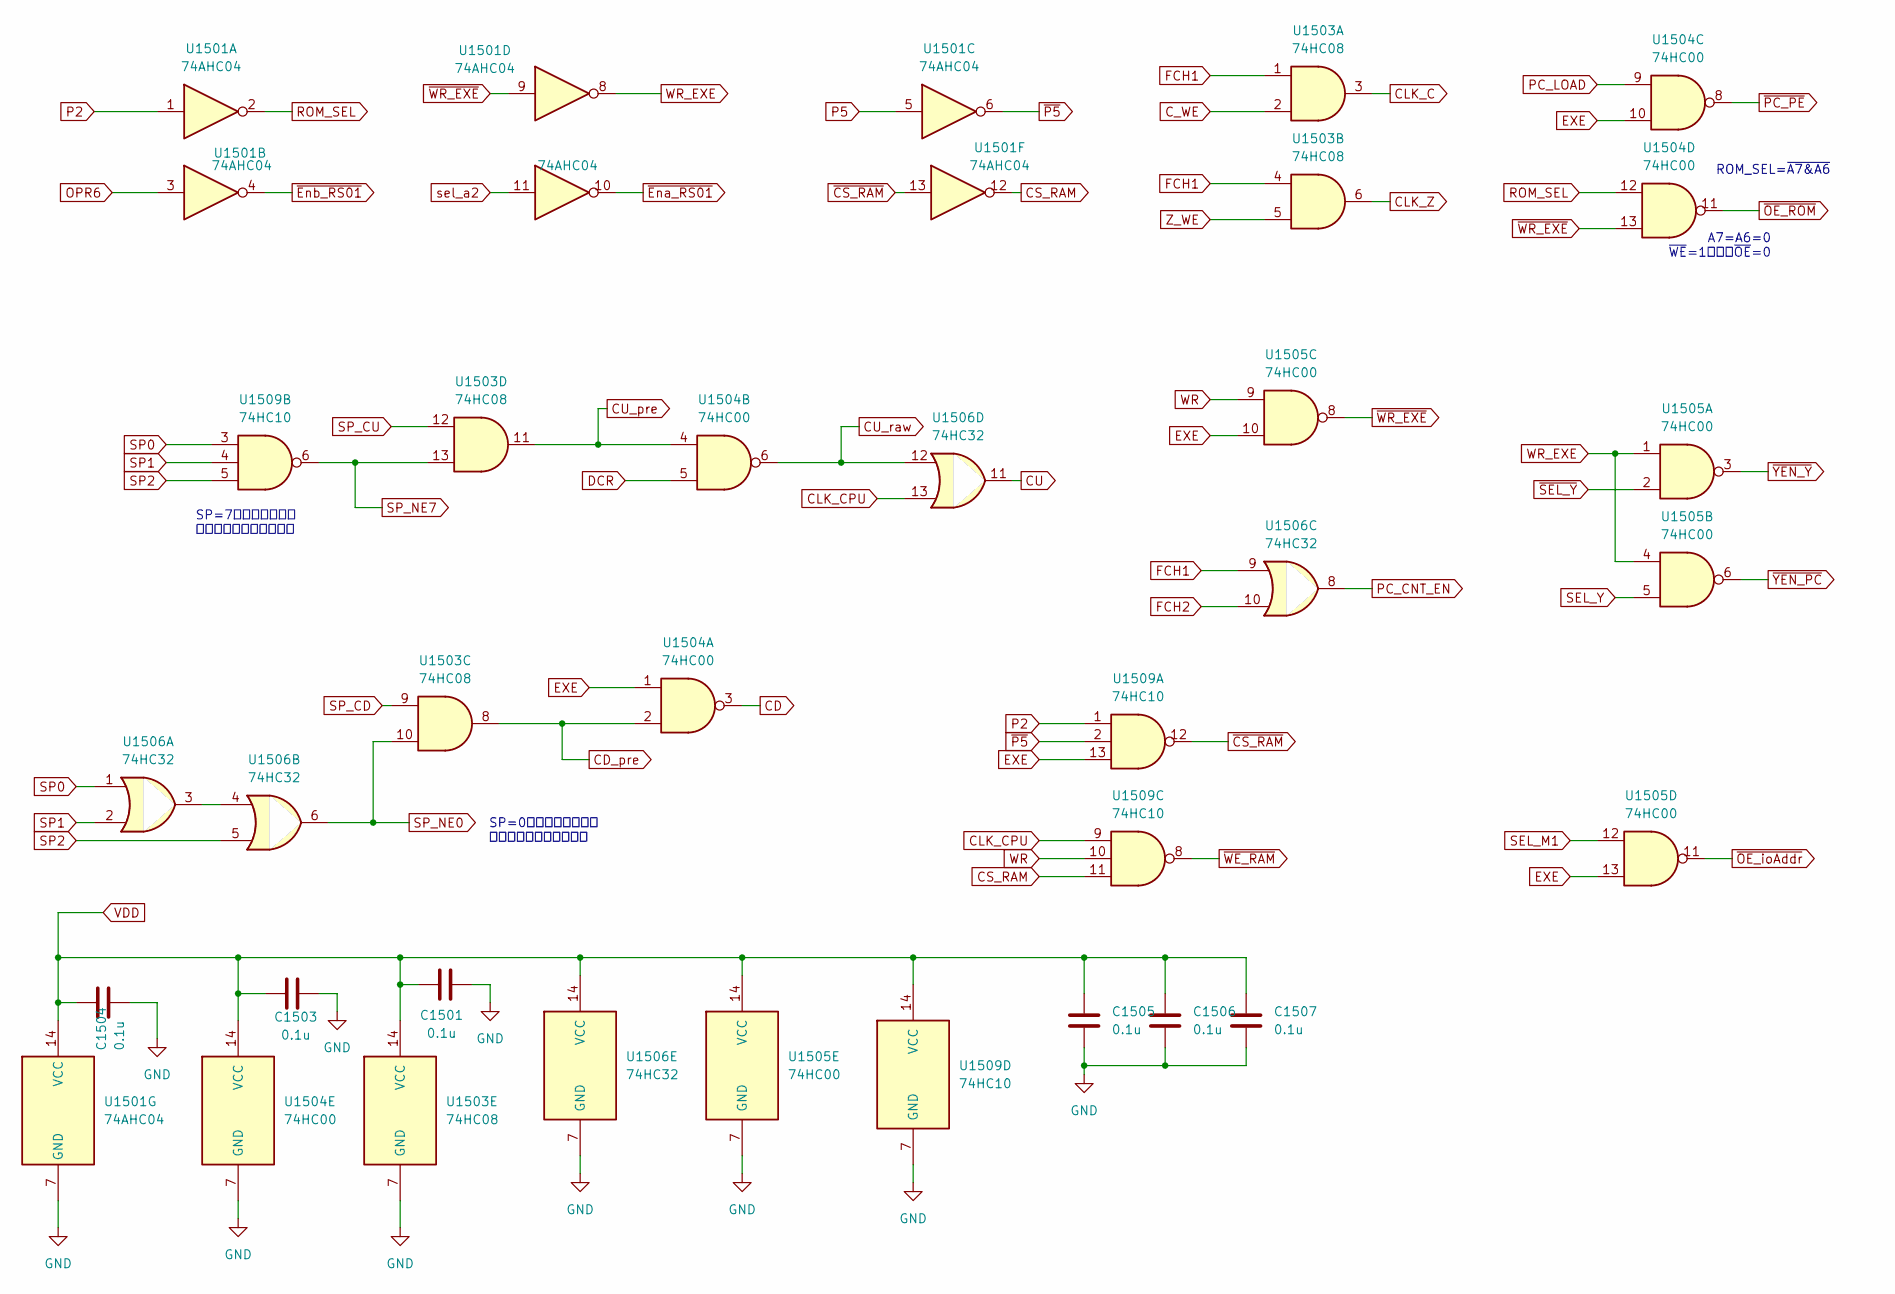
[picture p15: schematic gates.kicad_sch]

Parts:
C1501, C1503, C1504, C1505, C1506, C1507: 0.1u; C_Disc_D4.3mm_W1.9mm_P5.00mm
U1501: 74AHC04; DIP-14_W7.62mm_Socket
U1503: 74HC08; DIP-14_W7.62mm_Socket
U1504, U1505: 74HC00; DIP-14_W7.62mm_Socket
U1506: 74HC32; DIP-14_W7.62mm_Socket
U1509: 74HC10; DIP-14_W7.62mm_Socket

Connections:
CD: U1504.3; also elsewhere on the board
CD_pre: U1503.8, U1504.2
CLK_C: U1503.3; also elsewhere on the board
CLK_CPU: U1506.13, U1509.9; also elsewhere on the board
CLK_Z: U1503.6; also elsewhere on the board
CS_RAM: U1501.12, U1509.11
CU: U1506.11; also elsewhere on the board
CU_pre: U1503.11, U1504.4
CU_raw: U1504.6, U1506.12
C_WE: U1503.2; also elsewhere on the board
DCR: U1504.5; also elsewhere on the board
EXE: U1504.1, U1504.10, U1505.10, U1505.13, U1509.13; also elsewhere on the board
FCH1: U1503.1, U1503.4, U1506.9; also elsewhere on the board
FCH2: U1506.10; also elsewhere on the board
GND: C1501.2, C1503.2, C1504.2, C1505.1, C1506.1, C1507.1, U1501.7 (GND), U1503.7 (GND), U1504.7 (GND), U1505.7 (GND), U1506.7 (GND), U1509.7 (GND); also elsewhere on the board
unnamed: U1506.3, U1506.4
OPR6: U1501.3; also elsewhere on the board
P2: U1501.1, U1509.1; also elsewhere on the board
P5: U1501.5; also elsewhere on the board
PC_CNT_EN: U1506.8; also elsewhere on the board
PC_LOAD: U1504.9; also elsewhere on the board
ROM_SEL: U1501.2, U1504.12
SEL_M1: U1505.12; also elsewhere on the board
SEL_Y: U1505.5; also elsewhere on the board
SP0: U1506.1, U1509.3; also elsewhere on the board
SP1: U1506.2, U1509.4; also elsewhere on the board
SP2: U1506.5, U1509.5; also elsewhere on the board
SP_CD: U1503.9; also elsewhere on the board
SP_CU: U1503.12; also elsewhere on the board
SP_NE0: U1503.10, U1506.6
SP_NE7: U1503.13, U1509.6
VDD: C1501.1, C1503.1, C1504.1, C1505.2, C1506.2, C1507.2, U1501.14 (VCC), U1503.14 (VCC), U1504.14 (VCC), U1505.14 (VCC), U1506.14 (VCC), U1509.14 (VCC); also elsewhere on the board
WR: U1505.9, U1509.10; also elsewhere on the board
WR_EXE: U1501.8, U1505.1, U1505.4
Z_WE: U1503.5; also elsewhere on the board
sel_a2: U1501.11; also elsewhere on the board
~CS_RAM: U1501.13, U1509.12; also elsewhere on the board
~Ena_RS01: U1501.10; also elsewhere on the board
~Enb_RS01: U1501.4; also elsewhere on the board
~OE_ROM: U1504.11; also elsewhere on the board
~OE_ioAddr: U1505.11; also elsewhere on the board
~P5: U1501.6, U1509.2
~PC_PE: U1504.8; also elsewhere on the board
~SEL_Y: U1505.2; also elsewhere on the board
~WE_RAM: U1509.8; also elsewhere on the board
~WR_EXE: U1501.9, U1504.13, U1505.8
~YEN_PC: U1505.6; also elsewhere on the board
~YEN_Y: U1505.3; also elsewhere on the board

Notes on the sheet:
ROM_SEL=~{A7&A6}
A7=A6=0 ~{WE}=1のとき~{OE}=0
SP=7のときそれ以上 カウントアップさせない
SP=0のときそれ以下に カウントダウンさせない

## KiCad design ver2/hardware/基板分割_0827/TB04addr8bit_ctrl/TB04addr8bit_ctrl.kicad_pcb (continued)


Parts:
C401, C402, C403, C404: 0.1u; C_Disc_D4.3mm_W1.9mm_P5.00mm
IC401, IC402: 74HC161N; DIP-16_W7.62mm_Socket; Manufacturer_Part_Number 74HC161N
U401, U404: 74HC157; DIP-16_W7.62mm_Socket

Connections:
CLK_CPU: IC401.2 (CP), IC402.2 (CP); also elsewhere on the board
GND: C401.1, C402.1, C403.1, C404.1, IC401.8 (GND), IC402.8 (GND), U401.8 (GND), U401.15 (E), U404.8 (GND), U404.15 (E); also elsewhere on the board
MD0: U401.10 (I1c); also elsewhere on the board
MD1: U401.6 (I1b); also elsewhere on the board
MD2: U401.13 (I1d); also elsewhere on the board
MD3: U401.3 (I1a); also elsewhere on the board
MD4: U404.3 (I1a); also elsewhere on the board
MD5: U404.13 (I1d); also elsewhere on the board
MD6: U404.6 (I1b); also elsewhere on the board
MD7: U404.10 (I1c); also elsewhere on the board
unnamed: IC401.10 (CET), IC402.15 (TC)
OPR4: U401.11 (I0c); also elsewhere on the board
OPR5: U401.5 (I0b); also elsewhere on the board
OPR6: U401.14 (I0d); also elsewhere on the board
OPR7: U401.2 (I0a); also elsewhere on the board
OPR8: U404.2 (I0a); also elsewhere on the board
OPR9: U404.14 (I0d); also elsewhere on the board
OPR10: U404.5 (I0b); also elsewhere on the board
OPR11: U404.11 (I0c); also elsewhere on the board
PC0: IC402.3 (D0), U401.9 (Zc)
PC1: IC402.4 (D1), U401.7 (Zb)
PC2: IC402.5 (D2), U401.12 (Zd)
PC3: IC402.6 (D3), U401.4 (Za)
PC4: IC401.3 (D0), U404.4 (Za)
PC5: IC401.4 (D1), U404.12 (Zd)
PC6: IC401.5 (D2), U404.7 (Zb)
PC7: IC401.6 (D3), U404.9 (Zc)
PC_CNT_EN: IC401.7 (CEP), IC402.7 (CEP), IC402.10 (CET); also elsewhere on the board
PC_Q0: IC402.14 (Q0); also elsewhere on the board
PC_Q1: IC402.13 (Q1); also elsewhere on the board
PC_Q2: IC402.12 (Q2); also elsewhere on the board
PC_Q3: IC402.11 (Q3); also elsewhere on the board
PC_Q4: IC401.14 (Q0); also elsewhere on the board
PC_Q5: IC401.13 (Q1); also elsewhere on the board
PC_Q6: IC401.12 (Q2); also elsewhere on the board
PC_Q7: IC401.11 (Q3); also elsewhere on the board
SEL_PC: U401.1 (S), U404.1 (S); also elsewhere on the board
VDD: C401.2, C402.2, C403.2, C404.2, IC401.16 (VCC), IC402.16 (VCC), U401.16 (VCC), U404.16 (VCC); also elsewhere on the board
~PC_PE: IC401.9 (~PE), IC402.9 (~PE); also elsewhere on the board
~RST: IC401.1 (~MR), IC402.1 (~MR); also elsewhere on the board

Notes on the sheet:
PC_L
mAddrH
PC_H


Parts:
J801, J802, J803, J804: Conn_02x05_Odd_Even; PinSocket_2x05_P2.54mm_Vertical

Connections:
GND: J801.9, J801.10, J802.9, J802.10, J803.9, J803.10, J804.9, J804.10; also elsewhere on the board
OPC0: J801.8; also elsewhere on the board
OPC1: J801.6; also elsewhere on the board
OPC2: J801.4; also elsewhere on the board
OPC3: J801.2; also elsewhere on the board
OPR0: J802.8; also elsewhere on the board
OPR1: J802.6; also elsewhere on the board
OPR2: J802.4; also elsewhere on the board
OPR3: J802.2; also elsewhere on the board
OPR4: J803.8; also elsewhere on the board
OPR5: J803.6; also elsewhere on the board
OPR6: J803.4; also elsewhere on the board
OPR7: J803.2; also elsewhere on the board
OPR8: J804.8; also elsewhere on the board
OPR9: J804.6; also elsewhere on the board
OPR10: J804.4; also elsewhere on the board
OPR11: J804.2; also elsewhere on the board
VDD: J801.1, J802.1, J803.1, J804.1; also elsewhere on the board

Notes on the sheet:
7segIF x4


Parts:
C1101, C1102, C1103: 0.1u; C_Disc_D4.3mm_W1.9mm_P5.00mm
U1101: 6116; DIP-24_W15.24mm_Socket
U1102, U1103: 74HC244; DIP-20_W7.62mm_Socket

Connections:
A0: U1101.8 (A0); also elsewhere on the board
A1: U1101.7 (A1); also elsewhere on the board
A2: U1101.6 (A2); also elsewhere on the board
A3: U1101.5 (A3); also elsewhere on the board
A4: U1101.4 (A4); also elsewhere on the board
A5: U1101.3 (A5); also elsewhere on the board
A6: U1101.2 (A6); also elsewhere on the board
A7: U1101.1 (A7); also elsewhere on the board
GND: C1101.2, C1102.1, C1103.1, U1101.12 (GND), U1101.19 (A10), U1101.22 (A9), U1101.23 (A8), U1102.10 (GND), U1102.11 (2A3), U1102.13 (2A2), U1102.15 (2A1), U1102.17 (2A0), U1103.10 (GND); also elsewhere on the board
MD0: U1101.9 (D0), U1102.12 (1Y3), U1103.12 (1Y3); also elsewhere on the board
MD1: U1101.10 (D1), U1102.14 (1Y2), U1103.14 (1Y2); also elsewhere on the board
MD2: U1101.11 (D2), U1102.16 (1Y1), U1103.16 (1Y1); also elsewhere on the board
MD3: U1101.13 (D3), U1102.18 (1Y0), U1103.18 (1Y0); also elsewhere on the board
MD4: U1101.14 (D4), U1102.3 (2Y0), U1103.3 (2Y0); also elsewhere on the board
MD5: U1101.15 (D5), U1102.5 (2Y1), U1103.5 (2Y1); also elsewhere on the board
MD6: U1101.16 (D6), U1102.7 (2Y2), U1103.7 (2Y2); also elsewhere on the board
MD7: U1101.17 (D7), U1102.9 (2Y3), U1103.9 (2Y3); also elsewhere on the board
PC_Q0: U1103.8 (1A3); also elsewhere on the board
PC_Q1: U1103.6 (1A2); also elsewhere on the board
PC_Q2: U1103.4 (1A1); also elsewhere on the board
PC_Q3: U1103.2 (1A0); also elsewhere on the board
PC_Q4: U1103.17 (2A0); also elsewhere on the board
PC_Q5: U1103.15 (2A1); also elsewhere on the board
PC_Q6: U1103.13 (2A2); also elsewhere on the board
PC_Q7: U1103.11 (2A3); also elsewhere on the board
VDD: C1101.1, C1102.2, C1103.2, U1101.24 (VCC), U1102.20 (VCC), U1103.20 (VCC); also elsewhere on the board
WR: U1101.20 (~OE); also elsewhere on the board
YD0: U1102.8 (1A3); also elsewhere on the board
YD1: U1102.6 (1A2); also elsewhere on the board
YD2: U1102.4 (1A1); also elsewhere on the board
YD3: U1102.2 (1A0); also elsewhere on the board
~CS_RAM: U1101.18 (~CS); also elsewhere on the board
~WE_RAM: U1101.21 (~W); also elsewhere on the board
~YEN_PC: U1103.1 (1OE), U1103.19 (2OE); also elsewhere on the board
~YEN_Y: U1102.1 (1OE), U1102.19 (2OE); also elsewhere on the board

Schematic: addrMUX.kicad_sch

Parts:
C1401, C1402, C1403, C1404, C1407, C1408, C1409: 0.1u; C_Disc_D4.3mm_W1.9mm_P5.00mm
U1401: 74HC138; DIP-16_W7.62mm_Socket
U1402, U1403, U1404, U1405: 74HC244; DIP-20_W7.62mm_Socket
U1406: 74HC157; DIP-16_W7.62mm_Socket
U1407: 74HC139; DIP-16_W7.62mm_Socket

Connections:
A0: U1402.18 (1Y0), U1403.18 (1Y0), U1404.18 (1Y0), U1405.18 (1Y0); also elsewhere on the board
A1: U1402.14 (1Y2), U1403.16 (1Y1), U1404.16 (1Y1), U1405.16 (1Y1); also elsewhere on the board
A2: U1402.16 (1Y1), U1403.14 (1Y2), U1404.14 (1Y2), U1405.14 (1Y2); also elsewhere on the board
A3: U1402.12 (1Y3), U1403.12 (1Y3), U1404.12 (1Y3), U1405.12 (1Y3); also elsewhere on the board
A4: U1402.3 (2Y0), U1403.3 (2Y0), U1404.3 (2Y0), U1405.3 (2Y0); also elsewhere on the board
A5: U1402.5 (2Y1), U1403.5 (2Y1), U1404.5 (2Y1), U1405.5 (2Y1); also elsewhere on the board
A6: U1402.7 (2Y2), U1403.7 (2Y2), U1404.7 (2Y2), U1405.7 (2Y2); also elsewhere on the board
A7: U1402.9 (2Y3), U1403.9 (2Y3), U1404.9 (2Y3), U1405.9 (2Y3); also elsewhere on the board
EXE: U1401.6 (E2), U1403.1 (1OE), U1403.19 (2OE); also elsewhere on the board
GND: C1401.2, C1402.2, C1403.2, C1404.2, C1407.2, C1408.2, C1409.2, U1401.3 (A2), U1401.4 (~E0), U1401.5 (~E1), U1401.8 (GND), U1402.10 (GND), U1403.10 (GND), U1404.8 (1A3), U1404.10 (GND), U1405.10 (GND), U1406.8 (GND), U1406.10 (I1c), U1406.11 (I0c), U1406.13 (I1d), U1406.14 (I0d), U1406.15 (E), U1407.8 (GND); also elsewhere on the board
INPUT0: U1407.4 (O0); also elsewhere on the board
INPUT1: U1407.5 (O1); also elsewhere on the board
INPUT2: U1407.6 (O2); also elsewhere on the board
INPUT3: U1407.7 (O3); also elsewhere on the board
OPR4: U1402.2 (1A0), U1406.2 (I0a); also elsewhere on the board
OPR5: U1402.6 (1A2), U1406.5 (I0b); also elsewhere on the board
OPR6: U1402.4 (1A1); also elsewhere on the board
OPR7: U1402.8 (1A3); also elsewhere on the board
OPR8: U1402.17 (2A0), U1406.3 (I1a); also elsewhere on the board
OPR9: U1402.15 (2A1), U1406.6 (I1b); also elsewhere on the board
OPR10: U1402.13 (2A2); also elsewhere on the board
OPR11: U1402.11 (2A3); also elsewhere on the board
OUTPUT0: U1407.12 (O0); also elsewhere on the board
OUTPUT1: U1407.11 (O1); also elsewhere on the board
OUTPUT2: U1407.10 (O2); also elsewhere on the board
OUTPUT3: U1407.9 (O3); also elsewhere on the board
PC_Q0: U1403.2 (1A0); also elsewhere on the board
PC_Q1: U1403.4 (1A1); also elsewhere on the board
PC_Q2: U1403.6 (1A2); also elsewhere on the board
PC_Q3: U1403.8 (1A3); also elsewhere on the board
PC_Q4: U1403.17 (2A0); also elsewhere on the board
PC_Q5: U1403.15 (2A1); also elsewhere on the board
PC_Q6: U1403.13 (2A2); also elsewhere on the board
PC_Q7: U1403.11 (2A3); also elsewhere on the board
SEL_IMM: U1406.1 (S); also elsewhere on the board
SEL_M0: U1401.1 (A0), U1405.6 (1A2); also elsewhere on the board
SEL_M1: U1401.2 (A1); also elsewhere on the board
SP0: U1404.2 (1A0); also elsewhere on the board
SP1: U1404.4 (1A1); also elsewhere on the board
SP2: U1404.6 (1A2); also elsewhere on the board
VDD: C1401.1, C1402.1, C1403.1, C1404.1, C1407.1, C1408.1, C1409.1, U1401.16 (VCC), U1402.20 (VCC), U1403.20 (VCC), U1404.11 (2A3), U1404.13 (2A2), U1404.15 (2A1), U1404.17 (2A0), U1404.20 (VCC), U1405.8 (1A3), U1405.11 (2A3), U1405.13 (2A2), U1405.15 (2A1), U1405.17 (2A0), U1405.20 (VCC), U1406.16 (VCC), U1407.16 (VCC); also elsewhere on the board
port0: U1405.2 (1A0), U1406.4 (Za), U1407.2 (A0), U1407.14 (A0)
port1: U1405.4 (1A1), U1406.7 (Zb), U1407.3 (A1), U1407.13 (A1)
~OE_iAddr: U1401.13 (~Y2), U1407.1 (E)
~OE_ioAddr: U1405.1 (1OE), U1405.19 (2OE); also elsewhere on the board
~OE_mAddr: U1401.15 (~Y0), U1402.1 (1OE), U1402.19 (2OE)
~OE_oAddr: U1401.12 (~Y3), U1407.15 (E)
~OE_spAddr: U1401.14 (~Y1), U1404.1 (1OE), U1404.19 (2OE)

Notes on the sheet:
mAddr
I/Oチャネル指定用の244 他のアドレスを選択しないようにしている

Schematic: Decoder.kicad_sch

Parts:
C701, C702, C705, C706: 0.1u; C_Disc_D4.3mm_W1.9mm_P5.00mm
U701, U705: 74HC273; DIP-20_W7.62mm_Socket
U703, U706: 28C256; DIP-28_W15.24mm_Socket

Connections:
C_WE: U705.5 (Q1); also elsewhere on the board
DCR: U701.11 (Cp), U705.11 (Cp); also elsewhere on the board
GND: C701.1, C702.1, C705.1, C706.1, U701.10 (GND), U703.1 (A14), U703.2 (A12), U703.14 (GND), U703.20 (~CS), U703.21 (A10), U703.22 (~OE), U703.23 (A11), U703.26 (A13), U705.10 (GND), U706.1 (A14), U706.2 (A12), U706.14 (GND), U706.20 (~CS), U706.21 (A10), U706.22 (~OE), U706.23 (A11), U706.26 (A13); also elsewhere on the board
unnamed: U701.3 (D0), U703.11 (D0)
unnamed: U701.4 (D1), U703.12 (D1)
unnamed: U701.7 (D2), U703.13 (D2)
unnamed: U701.8 (D3), U703.15 (D3)
unnamed: U701.13 (D4), U703.16 (D4)
unnamed: U701.14 (D5), U703.17 (D5)
unnamed: U701.17 (D6), U703.18 (D6)
unnamed: U701.18 (D7), U703.19 (D7)
unnamed: U705.3 (D0), U706.11 (D0)
unnamed: U705.4 (D1), U706.12 (D1)
unnamed: U705.7 (D2), U706.13 (D2)
unnamed: U705.8 (D3), U706.15 (D3)
unnamed: U705.13 (D4), U706.16 (D4)
unnamed: U705.14 (D5), U706.17 (D5)
unnamed: U705.17 (D6), U706.18 (D6)
unnamed: U705.18 (D7), U706.19 (D7)
OPC0: U703.6 (A4), U706.6 (A4); also elsewhere on the board
OPC1: U703.5 (A5), U706.5 (A5); also elsewhere on the board
OPC2: U703.4 (A6), U706.4 (A6); also elsewhere on the board
OPC3: U703.3 (A7), U706.3 (A7); also elsewhere on the board
OPR0: U703.10 (A0), U706.10 (A0); also elsewhere on the board
OPR1: U703.9 (A1), U706.9 (A1); also elsewhere on the board
OPR2: U703.8 (A2), U706.8 (A2); also elsewhere on the board
OPR3: U703.7 (A3), U706.7 (A3); also elsewhere on the board
PC_LOAD: U701.15 (Q5); also elsewhere on the board
RegAddrSrc: U701.12 (Q4); also elsewhere on the board
SEL_M0: U701.5 (Q1); also elsewhere on the board
SEL_M1: U701.6 (Q2); also elsewhere on the board
SEL_PC: U701.9 (Q3); also elsewhere on the board
SEL_Y: U701.2 (Q0); also elsewhere on the board
SP_CD: U701.19 (Q7); also elsewhere on the board
SP_CU: U701.16 (Q6); also elsewhere on the board
VDD: C701.2, C702.2, C705.2, C706.2, U701.20 (VCC), U703.27 (~WE), U703.28 (VCC), U705.20 (VCC), U706.27 (~WE), U706.28 (VCC); also elsewhere on the board
WR: U705.9 (Q3); also elsewhere on the board
Z_WE: U705.6 (Q2); also elsewhere on the board
carry_in: U703.25 (A8), U706.25 (A8); also elsewhere on the board
zero_prev: U703.24 (A9), U706.24 (A9); also elsewhere on the board
~RST: U701.1 (~Mr), U705.1 (~Mr); also elsewhere on the board
~SEL_Y: U705.12 (Q4); also elsewhere on the board
~WE: U705.2 (Q0); also elsewhere on the board

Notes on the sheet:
デコーダ


Board: 2 copper layers, 210.0 x 170.0 mm, 101 parts (0 on the bottom side), 160 nets.

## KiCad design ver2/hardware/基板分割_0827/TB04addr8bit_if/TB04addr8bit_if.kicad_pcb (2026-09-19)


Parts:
C103: 0.1u; C_Disc_D4.3mm_W1.9mm_P5.00mm
C104: 100u; CP_Radial_D5.0mm_P2.00mm
D101: LED; LED_D3.0mm_Clear
J1: Conn_02x20_Odd_Even; PinSocket_2x20_P2.54mm_Vertical
J10, J11, J12, J13: Conn_02x05_Odd_Even; PinSocket_2x05_P2.54mm_Vertical
J101: USB_C_Receptacle_PowerOnly_6P; USB_C_receptacle_onlypower_tanuki
J1602: Screw_Terminal_01x02; TerminalBlock_MaiXu_MX126-5.0-02P_1x02_P5.00mm
R101, R102: 5.1K; R_Axial_DIN0207_L6.3mm_D2.5mm_P10.16mm_Horizontal
R103: 3.3K; R_Axial_DIN0207_L6.3mm_D2.5mm_P7.62mm_Horizontal
SW101: SW_SPDT; sw_slide

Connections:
CLK_CPU: J1.1; also elsewhere on the board
GND: C103.2, C104.2, D101.1 (K), J1.2, J1.4, J1.6, J1.8, J1.10, J1.12, J1.14, J1.16, J1.18, J1.20, J1.22, J1.24, J1.26, J1.28, J1.30, J1.32, J1.34, J1.36, J10.9, J10.10, J11.9, J11.10, J12.9, J12.10, J13.9, J13.10, J101.1 (B_12_GND), J101.6 (A12_GND), J1602.2, R101.1, R102.1; also elsewhere on the board
IN0_0: J10.8; also elsewhere on the board
IN0_1: J10.6; also elsewhere on the board
IN0_2: J10.4; also elsewhere on the board
IN0_3: J10.2; also elsewhere on the board
IN1_0: J11.8; also elsewhere on the board
IN1_1: J11.6; also elsewhere on the board
IN1_2: J11.4; also elsewhere on the board
IN1_3: J11.2; also elsewhere on the board
IN2_0: J12.8; also elsewhere on the board
IN2_1: J12.6; also elsewhere on the board
IN2_2: J12.4; also elsewhere on the board
IN2_3: J12.2; also elsewhere on the board
IN3_0: J13.8; also elsewhere on the board
IN3_1: J13.6; also elsewhere on the board
IN3_2: J13.4; also elsewhere on the board
IN3_3: J13.2; also elsewhere on the board
INPUT0: J1.27; also elsewhere on the board
INPUT1: J1.25; also elsewhere on the board
INPUT2: J1.23; also elsewhere on the board
INPUT3: J1.21; also elsewhere on the board
MD0: J1.19; also elsewhere on the board
MD1: J1.17; also elsewhere on the board
MD2: J1.15; also elsewhere on the board
MD3: J1.13; also elsewhere on the board
MD4: J1.11; also elsewhere on the board
MD5: J1.9; also elsewhere on the board
MD6: J1.7; also elsewhere on the board
MD7: J1.5; also elsewhere on the board
unnamed: D101.2 (A), R103.2
unnamed: J101.3 (A5_CC1), R102.2
unnamed: J101.2 (B9_VBUS), J101.5 (A9_VBUS), SW101.2 (B)
unnamed: J101.4 (B5_CC2), R101.2
OUTPUT0: J1.35; also elsewhere on the board
OUTPUT1: J1.33; also elsewhere on the board
OUTPUT2: J1.31; also elsewhere on the board
OUTPUT3: J1.29; also elsewhere on the board
VDD: C103.1, C104.1, J1.38, J1.40, J10.1, J11.1, J12.1, J13.1, J1602.1, R103.1, SW101.3 (C); also elsewhere on the board
~RST: J1.3; also elsewhere on the board

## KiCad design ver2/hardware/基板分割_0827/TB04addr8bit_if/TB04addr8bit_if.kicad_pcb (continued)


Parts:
C901, C902, C903, C904: 0.1u; C_Disc_D4.3mm_W1.9mm_P5.00mm
D901, D902, D903, D904, D905, D906, D907, D908, D909, D910, D911, D912, D913, D914, D915, D916: LED; LED_D3.0mm_Clear
J901, J902, J903, J904: Conn_02x05_Odd_Even; PinSocket_2x05_P2.54mm_Vertical
RN901, RN902: 4.7K; R_Array_SIP9
U901, U902, U903, U905: 74HC377; DIP-20_W7.62mm_Socket

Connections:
GND: C901.1, C902.1, C903.1, C904.1, J901.9, J901.10, J902.9, J902.10, J903.9, J903.10, J904.9, J904.10, RN901.1 (R1), RN902.1 (R1), U901.10 (GND), U901.13 (D4), U901.14 (D5), U901.17 (D6), U901.18 (D7), U902.10 (GND), U902.13 (D4), U902.14 (D5), U902.17 (D6), U902.18 (D7), U903.10 (GND), U903.13 (D4), U903.14 (D5), U903.17 (D6), U903.18 (D7), U905.10 (GND), U905.13 (D4), U905.14 (D5), U905.17 (D6), U905.18 (D7); also elsewhere on the board
MD0: U901.3 (D0), U902.3 (D0), U903.3 (D0), U905.3 (D0); also elsewhere on the board
MD1: U901.4 (D1), U902.4 (D1), U903.4 (D1), U905.4 (D1); also elsewhere on the board
MD2: U901.7 (D2), U902.7 (D2), U903.7 (D2), U905.7 (D2); also elsewhere on the board
MD3: U901.8 (D3), U902.8 (D3), U903.8 (D3), U905.8 (D3); also elsewhere on the board
unnamed: D901.2 (A), J901.2, U905.9 (Q3)
unnamed: D901.1 (K), RN901.2 (R1.2)
unnamed: D902.2 (A), J901.6, U905.5 (Q1)
unnamed: D902.1 (K), RN901.4 (R3.2)
unnamed: D903.2 (A), J901.4, U905.6 (Q2)
unnamed: D903.1 (K), RN901.3 (R2.2)
unnamed: D904.2 (A), J901.8, U905.2 (Q0)
unnamed: D904.1 (K), RN901.5 (R4.2)
unnamed: D905.2 (A), J902.2, U901.9 (Q3)
unnamed: D905.1 (K), RN901.6 (R5.2)
unnamed: D906.2 (A), J902.4, U901.6 (Q2)
unnamed: D906.1 (K), RN901.7 (R6.2)
unnamed: D907.2 (A), J902.6, U901.5 (Q1)
unnamed: D907.1 (K), RN901.8 (R7.2)
unnamed: D908.2 (A), J902.8, U901.2 (Q0)
unnamed: D908.1 (K), RN901.9 (R8.2)
unnamed: D909.2 (A), J903.2, U902.9 (Q3)
unnamed: D909.1 (K), RN902.2 (R1.2)
unnamed: D910.2 (A), J903.4, U902.6 (Q2)
unnamed: D910.1 (K), RN902.3 (R2.2)
unnamed: D911.2 (A), J903.6, U902.5 (Q1)
unnamed: D911.1 (K), RN902.4 (R3.2)
unnamed: D912.2 (A), J903.8, U902.2 (Q0)
unnamed: D912.1 (K), RN902.5 (R4.2)
unnamed: D913.2 (A), J904.2, U903.9 (Q3)
unnamed: D913.1 (K), RN902.6 (R5.2)
unnamed: D914.2 (A), J904.4, U903.6 (Q2)
unnamed: D914.1 (K), RN902.7 (R6.2)
unnamed: D915.2 (A), J904.6, U903.5 (Q1)
unnamed: D915.1 (K), RN902.8 (R7.2)
unnamed: D916.2 (A), J904.8, U903.2 (Q0)
unnamed: D916.1 (K), RN902.9 (R8.2)
OUTPUT0: U905.1 (~E); also elsewhere on the board
OUTPUT1: U901.1 (~E); also elsewhere on the board
OUTPUT2: U902.1 (~E); also elsewhere on the board
OUTPUT3: U903.1 (~E); also elsewhere on the board
VDD: C901.2, C902.2, C903.2, C904.2, J901.1, J902.1, J903.1, J904.1, U901.20 (VCC), U902.20 (VCC), U903.20 (VCC), U905.20 (VCC); also elsewhere on the board
~CLK_CPU: U901.11 (CP), U902.11 (CP), U903.11 (CP), U905.11 (CP); also elsewhere on the board


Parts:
C501, C502: 10u 16V; CP_Radial_D5.0mm_P2.00mm
C503, C504: 0.1u; C_Disc_D4.3mm_W1.9mm_P5.00mm
C505, C506: 22p; C_Disc_D4.3mm_W1.9mm_P5.00mm
D501, D502: LED; LED_D3.0mm_Clear
H501, H502, H503, H504: MountingHole_Pad; MountingHole_3.2mm_M3_Pad_Via
R501, R502: 1K; R_Axial_DIN0207_L6.3mm_D2.5mm_P10.16mm_Horizontal
R503, R506: 10K; R_Axial_DIN0207_L6.3mm_D2.5mm_P10.16mm_Horizontal
R504, R507, R509: 100K; R_Axial_DIN0207_L6.3mm_D2.5mm_P7.62mm_Horizontal
R505: 100; R_Axial_DIN0207_L6.3mm_D2.5mm_P10.16mm_Horizontal
R508, R510: 3.3K; R_Axial_DIN0207_L6.3mm_D2.5mm_P7.62mm_Horizontal
R511: 10M; R_Axial_DIN0207_L6.3mm_D2.5mm_P10.16mm_Horizontal
R512: 220K; R_Axial_DIN0207_L6.3mm_D2.5mm_P10.16mm_Horizontal
SW501, SW503: SW_Push; SW_Tactile_Straight_KSL0Axx1LFTR
SW502: sw rotary; SW_Rotary_1x9_Alpha_SR1712F-0109
U501: 74HC14; DIP-14_W7.62mm_Socket
U502: 4060; DIP-16_W7.62mm_Socket
Y501: 32.768KHz; PinSocket_1x02_P2.00mm_Vertical

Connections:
CLK_CPU: U501.8, U501.11; also elsewhere on the board
GND: C501.2, C502.2, C503.1, C504.2, C505.2, C506.2, D501.1 (K), D502.1 (K), H501.1 (1_1), H502.1 (1_1), H503.1 (1_1), H504.1 (1_1), R509.2, SW501.1, SW503.1, U501.7 (GND), U501.13, U502.8 (VSS); also elsewhere on the board
unnamed: C501.1, R503.2, R504.1
unnamed: C502.1, R506.2, R507.1
unnamed: D501.2 (A), R508.2
unnamed: D502.2 (A), R510.2
unnamed: R501.2, R503.1, SW501.2
unnamed: R502.2, R506.1, SW503.2
unnamed: R504.2, U501.5
unnamed: R505.1, U501.6
unnamed: R505.2, SW502.2
unnamed: R507.2, U501.1
unnamed: R509.1, R510.1, SW502.1, U501.9
unnamed: R512.1, Y501.2
unnamed: SW502.10, U502.7 (Q4)
unnamed: SW502.9, U502.5 (Q5)
unnamed: SW502.8, U502.4 (Q6)
unnamed: SW502.7, U502.14 (Q8)
unnamed: SW502.6, U502.13 (Q9)
unnamed: SW502.5, U502.15 (Q10)
unnamed: SW502.4, U502.1 (Q12)
unnamed: SW502.3, U502.2 (Q13)
unnamed: C506.1, R511.2, R512.2, U502.11 (~Φ1)
unnamed: C505.1, R511.1, U502.10 (Φ0), Y501.1
RST: R508.1, U501.2, U501.3, U502.12 (CLR)
VDD: C503.2, C504.1, R501.1, R502.1, U501.14 (VCC), U502.16 (VDD); also elsewhere on the board
~CLK_CPU: U501.10; also elsewhere on the board
~RST: U501.4; also elsewhere on the board

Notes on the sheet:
Auto
Manual
Slow
Fast


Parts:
C1001, C1002, C1003, C1004: 0.1u; C_Disc_D4.3mm_W1.9mm_P5.00mm
D1001, D1002, D1003, D1004, D1005, D1006, D1007, D1008, D1009, D1010, D1011, D1012, D1013, D1014, D1015, D1016: LED; LED_D3.0mm_Clear
J1001, J1002, J1003, J1004: Conn_01x06_Socket; PinSocket_1x06_P2.54mm_Vertical
RN1001, RN1002: 4.7K; R_Array_SIP9
RN1009, RN1010: 10K; R_Array_SIP9
SW1001, SW1002, SW1003, SW1004: SW_DIP_x04; SW_DIP_SPSTx04_Slide_9.78x12.34mm_W7.62mm_P2.54mm
U1001, U1002, U1003, U1004: 74HC244; DIP-20_W7.62mm_Socket

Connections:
GND: C1001.1, C1002.1, C1003.1, C1004.1, J1001.6, J1002.6, J1003.6, J1004.6, RN1001.1 (R1), RN1002.1 (R1), RN1009.1 (R1), RN1010.1 (R1), U1001.10 (GND), U1001.11 (2A3), U1001.13 (2A2), U1001.15 (2A1), U1001.17 (2A0), U1002.10 (GND), U1002.11 (2A3), U1002.13 (2A2), U1002.15 (2A1), U1002.17 (2A0), U1003.10 (GND), U1003.11 (2A3), U1003.13 (2A2), U1003.15 (2A1), U1003.17 (2A0), U1004.10 (GND), U1004.11 (2A3), U1004.13 (2A2), U1004.15 (2A1), U1004.17 (2A0); also elsewhere on the board
IN0_0: D1001.2 (A), J1001.4, RN1009.5 (R4.2), SW1001.4, U1001.2 (1A0); also elsewhere on the board
IN0_1: D1003.2 (A), J1001.3, RN1009.4 (R3.2), SW1001.3, U1001.4 (1A1); also elsewhere on the board
IN0_2: D1002.2 (A), J1001.2, RN1009.3 (R2.2), SW1001.2, U1001.6 (1A2); also elsewhere on the board
IN0_3: D1004.2 (A), J1001.1, RN1009.2 (R1.2), SW1001.1, U1001.8 (1A3); also elsewhere on the board
IN1_0: D1005.2 (A), J1002.4, RN1009.9 (R8.2), SW1002.4, U1002.2 (1A0); also elsewhere on the board
IN1_1: D1006.2 (A), J1002.3, RN1009.8 (R7.2), SW1002.3, U1002.4 (1A1); also elsewhere on the board
IN1_2: D1007.2 (A), J1002.2, RN1009.7 (R6.2), SW1002.2, U1002.6 (1A2); also elsewhere on the board
IN1_3: D1008.2 (A), J1002.1, RN1009.6 (R5.2), SW1002.1, U1002.8 (1A3); also elsewhere on the board
IN2_0: D1009.2 (A), J1003.4, RN1010.5 (R4.2), SW1003.4, U1003.2 (1A0); also elsewhere on the board
IN2_1: D1010.2 (A), J1003.3, RN1010.4 (R3.2), SW1003.3, U1003.4 (1A1); also elsewhere on the board
IN2_2: D1011.2 (A), J1003.2, RN1010.3 (R2.2), SW1003.2, U1003.6 (1A2); also elsewhere on the board
IN2_3: D1012.2 (A), J1003.1, RN1010.2 (R1.2), SW1003.1, U1003.8 (1A3); also elsewhere on the board
IN3_0: D1013.2 (A), J1004.4, RN1010.9 (R8.2), SW1004.4, U1004.2 (1A0); also elsewhere on the board
IN3_1: D1014.2 (A), J1004.3, RN1010.8 (R7.2), SW1004.3, U1004.4 (1A1); also elsewhere on the board
IN3_2: D1015.2 (A), J1004.2, RN1010.7 (R6.2), SW1004.2, U1004.6 (1A2); also elsewhere on the board
IN3_3: D1016.2 (A), J1004.1, RN1010.6 (R5.2), SW1004.1, U1004.8 (1A3); also elsewhere on the board
INPUT0: U1001.1 (1OE), U1001.19 (2OE); also elsewhere on the board
INPUT1: U1002.1 (1OE), U1002.19 (2OE); also elsewhere on the board
INPUT2: U1003.1 (1OE), U1003.19 (2OE); also elsewhere on the board
INPUT3: U1004.1 (1OE), U1004.19 (2OE); also elsewhere on the board
MD0: U1001.18 (1Y0), U1002.18 (1Y0), U1003.18 (1Y0), U1004.18 (1Y0); also elsewhere on the board
MD1: U1001.16 (1Y1), U1002.16 (1Y1), U1003.16 (1Y1), U1004.16 (1Y1); also elsewhere on the board
MD2: U1001.14 (1Y2), U1002.14 (1Y2), U1003.14 (1Y2), U1004.14 (1Y2); also elsewhere on the board
MD3: U1001.12 (1Y3), U1002.12 (1Y3), U1003.12 (1Y3), U1004.12 (1Y3); also elsewhere on the board
MD4: U1001.3 (2Y0), U1002.3 (2Y0), U1003.3 (2Y0), U1004.3 (2Y0); also elsewhere on the board
MD5: U1001.5 (2Y1), U1002.5 (2Y1), U1003.5 (2Y1), U1004.5 (2Y1); also elsewhere on the board
MD6: U1001.7 (2Y2), U1002.7 (2Y2), U1003.7 (2Y2), U1004.7 (2Y2); also elsewhere on the board
MD7: U1001.9 (2Y3), U1002.9 (2Y3), U1003.9 (2Y3), U1004.9 (2Y3); also elsewhere on the board
unnamed: D1001.1 (K), RN1001.2 (R1.2)
unnamed: D1002.1 (K), RN1001.4 (R3.2)
unnamed: D1003.1 (K), RN1001.3 (R2.2)
unnamed: D1004.1 (K), RN1001.5 (R4.2)
unnamed: D1005.1 (K), RN1001.6 (R5.2)
unnamed: D1006.1 (K), RN1001.7 (R6.2)
unnamed: D1007.1 (K), RN1001.8 (R7.2)
unnamed: D1008.1 (K), RN1001.9 (R8.2)
unnamed: D1009.1 (K), RN1002.2 (R1.2)
unnamed: D1010.1 (K), RN1002.3 (R2.2)
unnamed: D1011.1 (K), RN1002.4 (R3.2)
unnamed: D1012.1 (K), RN1002.5 (R4.2)
unnamed: D1013.1 (K), RN1002.6 (R5.2)
unnamed: D1014.1 (K), RN1002.7 (R6.2)
unnamed: D1015.1 (K), RN1002.8 (R7.2)
unnamed: D1016.1 (K), RN1002.9 (R8.2)
VDD: C1001.2, C1002.2, C1003.2, C1004.2, J1001.5, J1002.5, J1003.5, J1004.5, SW1001.5, SW1001.6, SW1001.7, SW1001.8, SW1002.5, SW1002.6, SW1002.7, SW1002.8, SW1003.5, SW1003.6, SW1003.7, SW1003.8, SW1004.5, SW1004.6, SW1004.7, SW1004.8, U1001.20 (VCC), U1002.20 (VCC), U1003.20 (VCC), U1004.20 (VCC); also elsewhere on the board


Board: 2 copper layers, 135.0 x 150.0 mm, 110 parts (0 on the bottom side), 112 nets.

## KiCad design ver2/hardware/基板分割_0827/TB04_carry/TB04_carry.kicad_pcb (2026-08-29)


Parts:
C1: 0.1u; C_Disc_D4.3mm_W1.9mm_P5.00mm
C2: 100u; CP_Radial_D5.0mm_P2.00mm
D1: LED; LED_D3.0mm_Clear
H1, H2, H3, H4: MountingHole_Pad; MountingHole_3.2mm_M3_Pad_Via
J2: Conn_02x10_Odd_Even; PinSocket_2x10_P2.54mm_Vertical
J3, J4, J5, J6: Conn_02x05_Odd_Even; PinSocket_2x05_P2.54mm_Vertical
J1602: Screw_Terminal_01x02; TerminalBlock_MaiXu_MX126-5.0-02P_1x02_P5.00mm
R1: 3.3K; R_Axial_DIN0207_L6.3mm_D2.5mm_P7.62mm_Horizontal

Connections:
DIG_D0_0: J2.6, J3.8
DIG_D0_1: J2.5, J3.6
DIG_D0_2: J2.4, J3.4
DIG_D0_3: J2.3, J3.2
DIG_D1_0: J2.10, J4.8
DIG_D1_1: J2.9, J4.6
DIG_D1_2: J2.8, J4.4
DIG_D1_3: J2.7, J4.2
DIG_D2_0: J2.14, J5.8
DIG_D2_1: J2.13, J5.6
DIG_D2_2: J2.12, J5.4
DIG_D2_3: J2.11, J5.2
DIG_D3_0: J2.18, J6.8
DIG_D3_1: J2.17, J6.6
DIG_D3_2: J2.16, J6.4
DIG_D3_3: J2.15, J6.2
GND: C1.2, C2.2, D1.1 (K), H1.1 (1_1), H2.1 (1_1), H3.1 (1_1), H4.1 (1_1), J2.2, J2.19, J3.9, J3.10, J4.9, J4.10, J5.9, J5.10, J6.9, J6.10, J1602.2
unnamed: D1.2 (A), R1.2
VDD: C1.1, C2.1, J2.1, J3.1, J4.1, J5.1, J6.1, J1602.1, R1.1


Board: 2 copper layers, 100.0 x 30.0 mm, 14 parts (0 on the bottom side), 19 nets.

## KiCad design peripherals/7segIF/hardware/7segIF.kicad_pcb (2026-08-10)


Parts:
AFF1: LTS-6960HR; 7SegmentLED_LTS6760_LTS6780
C1: 100u; CP_Radial_D4.0mm_P2.00mm
C2: 0.1u; C_0603_1608Metric_Pad1.08x0.95mm_HandSolder
D1: LED; LED_D3.0mm
J1: Conn_02x05_Odd_Even; PinSocket_2x05_P2.54mm_Vertical
J2: Conn_02x05_Odd_Even; PinHeader_2x05_P2.54mm_Vertical
R1, R2, R3, R4, R5, R6, R7, R8, R9: 3.3K; R_0603_1608Metric_Pad0.98x0.95mm_HandSolder
U1: CH32V003F4P6; TSSOP-20_4.4x6.5mm_P0.65mm

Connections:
GND: C1.2, C2.2, D1.1 (K), J1.6, J2.9, J2.10, U1.7 (VSS)
unnamed: AFF1.5 (DP), R8.2
unnamed: AFF1.7 (a), R1.2
unnamed: AFF1.6 (b), R2.2
unnamed: AFF1.4 (c), R7.2
unnamed: AFF1.2 (d), R6.2
unnamed: AFF1.1 (e), R5.2
unnamed: AFF1.9 (f), R4.2
unnamed: AFF1.10 (g), R3.2
unnamed: D1.2 (A), R9.2
unnamed: J2.2, U1.13 (PC3)
unnamed: J2.4, U1.12 (PC2)
unnamed: J2.6, U1.11 (PC1)
unnamed: J2.8, U1.10 (PC0)
unnamed: R1.1, U1.8 (PD0)
unnamed: R7.1, U1.19 (PD2)
unnamed: R6.1, U1.20 (PD3)
unnamed: R5.1, U1.1 (PD4)
unnamed: R8.1, U1.4 (PD7)
RX: J1.3, R3.1, U1.3 (PD6)
SWDIO: J1.4, R2.1, U1.18 (PD1)
TX: J1.1, R4.1, U1.2 (PD5)
VDD: AFF1.3 (C.A.), AFF1.8 (C.A.), C1.1, C2.1, J1.10, J2.1, R9.1, U1.9 (VDD)

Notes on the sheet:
もとの回路図との違い ・J1を左右逆にした
WCH-Link E
SWCLK SWDIO GND 3V3 5V
RX TX GND 3V3 5V


Board: 2 copper layers, 23.0 x 41.5 mm, 16 parts (0 on the bottom side), 23 nets.

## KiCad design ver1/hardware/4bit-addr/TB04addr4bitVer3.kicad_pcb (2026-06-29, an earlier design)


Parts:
C1, C25, C26: 0.1u; C_Disc_D4.3mm_W1.9mm_P5.00mm
C7: 100u; CP_Radial_D5.0mm_P2.00mm
D21: LED; LED_D3.0mm_Clear
J1: USB_C_Receptacle_PowerOnly_6P; USB_C_receptacle_onlypower_tanuki
R1: 1K; R_Axial_DIN0207_L6.3mm_D2.5mm_P10.16mm_Horizontal
R2, R3, R4, R5, R8, R10, R11, R12, R13, R14, R15, R16, R17, R18, R19, R20: 47; R_Axial_DIN0207_L6.3mm_D2.5mm_P10.16mm_Horizontal
R6, R7: 5.1K; R_Axial_DIN0207_L6.3mm_D2.5mm_P10.16mm_Horizontal
R9: 3.3K; R_Axial_DIN0207_L6.3mm_D2.5mm_P7.62mm_Horizontal
SW1: SW_SPDT; sw_slide
U15: 74HC138; DIP-16_W7.62mm_Socket
U16: 74HC00; DIP-14_W7.62mm_Socket

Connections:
/RS00/OUT0a: R12.1; also elsewhere on the board
/RS00/OUT0b: R10.1; also elsewhere on the board
/RS00/OUT1a: R5.1; also elsewhere on the board
/RS00/OUT1b: R3.1; also elsewhere on the board
/RS00/OUT2a: R11.1; also elsewhere on the board
/RS00/OUT2b: R8.1; also elsewhere on the board
/RS00/OUT3a: R4.1; also elsewhere on the board
/RS00/OUT3b: R2.1; also elsewhere on the board
/RS01/OUT0a: R20.1; also elsewhere on the board
/RS01/OUT0b: R18.1; also elsewhere on the board
/RS01/OUT1a: R16.1; also elsewhere on the board
/RS01/OUT1b: R14.1; also elsewhere on the board
/RS01/OUT2a: R19.1; also elsewhere on the board
/RS01/OUT2b: R17.1; also elsewhere on the board
/RS01/OUT3a: R15.1; also elsewhere on the board
/RS01/OUT3b: R13.1; also elsewhere on the board
/RS01/~Ena: U16.3; also elsewhere on the board
/RS01/~Enb: U16.6; also elsewhere on the board
CNTABL: U16.11; also elsewhere on the board
DOa0: R12.2, R20.2; also elsewhere on the board
DOa1: R5.2, R16.2; also elsewhere on the board
DOa2: R11.2, R19.2; also elsewhere on the board
DOa3: R4.2, R15.2; also elsewhere on the board
DOb0: R10.2, R18.2; also elsewhere on the board
DOb1: R3.2, R14.2; also elsewhere on the board
DOb2: R8.2, R17.2; also elsewhere on the board
DOb3: R2.2, R13.2; also elsewhere on the board
Decord: U16.9; also elsewhere on the board
Execute: U15.6 (E2); also elsewhere on the board
GND: C1.2, C7.2, C25.2, C26.2, D21.1 (K), J1.1 (B_12_GND), J1.6 (A12_GND), R1.2, R6.1, R7.1, U15.5 (~E1), U15.8 (GND), U16.7 (GND); also elsewhere on the board
NOT_JMP: U16.10; also elsewhere on the board
unnamed: D21.2 (A), R9.2
unnamed: J1.3 (A5_CC1), R7.2
unnamed: J1.2 (B9_VBUS), J1.5 (A9_VBUS), SW1.2 (B)
unnamed: J1.4 (B5_CC2), R6.2
unnamed: U16.8, U16.12, U16.13
Reg_RD_SEL2a: U16.1, U16.2; also elsewhere on the board
Reg_RD_SEL2b: U16.4, U16.5; also elsewhere on the board
Reg_WE_SEL0: U15.1 (A0); also elsewhere on the board
Reg_WE_SEL1: U15.2 (A1); also elsewhere on the board
Reg_WE_SEL2: U15.3 (A2); also elsewhere on the board
VDD: C1.1, C7.1, C25.1, C26.1, R1.1, R9.1, SW1.3 (C), U15.16 (VCC), U16.14 (VCC); also elsewhere on the board
~Reg_WE0: U15.15 (~Y0); also elsewhere on the board
~Reg_WE1: U15.14 (~Y1); also elsewhere on the board
~Reg_WE2: U15.13 (~Y2); also elsewhere on the board
~Reg_WE3: U15.12 (~Y3); also elsewhere on the board
~Reg_WE4: U15.11 (~Y4); also elsewhere on the board
~Reg_WE5: U15.10 (~Y5); also elsewhere on the board
~Reg_WE6: U15.9 (~Y6); also elsewhere on the board
~Reg_WE7: U15.7 (~Y7); also elsewhere on the board
~WE: U15.4 (~E0); also elsewhere on the board

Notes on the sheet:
rev.1 タイミングを考慮した結果変更


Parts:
C6, C20, C23, C24, C28, C29, C30, C31, C34, C35, C36: 0.1u; C_Disc_D4.3mm_W1.9mm_P5.00mm
D38, D39, D40, D41, D42, D43: LED; LED_D3.0mm_Clear
IC9: 74HC161N; DIP-16_W7.62mm_Socket; Manufacturer_Part_Number 74HC161N
R21, R22: 3.3K; R_Axial_DIN0207_L6.3mm_D2.5mm_P7.62mm_Horizontal
RN8: 4.7K; R_Array_SIP5
U5, U22, U23: 28C256; DIP-28_W15.24mm_Socket
U11, U18, U19: 74LS273; DIP-20_W7.62mm_Socket
U14: 74HC238; DIP-16_W7.62mm_Socket
U20: 74HC273; DIP-20_W7.62mm_Socket
U21: 74HC74; DIP-14_W7.62mm_Socket
U24: 28C256; DIP_Socket-28_W11.9mm_W12.7mm_W15.24mm_W17.78mm_W18.5mm_3M_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

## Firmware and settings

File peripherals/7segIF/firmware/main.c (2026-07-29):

/*
 * 7segIF firmware  ―  TB-04 の 4bit OUT を 0..F の7セグ表示にデコード
 *
 * MCU        : CH32V003F4P6 (RISC-V, QingKe V2A)
 * Toolchain  : MounRiver Studio ＋ WCH 標準ペリフェラルライブラリ(SPL)
 * Display    : LTS-6960HR（コモンアノード・赤）
 *
 * 実配線（2026-07-20 ネットリストで確定）:
 *   入力  TB-04 OUT → J1:  D0=PC0  D1=PC1  D2=PC2  D3=PC3   … PORTC[3:0]
 *   出力  → 7セグ(各3.3K):  a=PD0 b=PD1 c=PD2 d=PD3 e=PD4 f=PD5 g=PD6 DP=PD7 … PORTD[7:0]
 *   コモンアノード → セグメントは MCU ピン LOW(0) で点灯。
 *
 * 注意（回路は問題なし・ソフト/書込側の制約）:
 *   - PD1(seg b) は SWIO。GPIO 使用中はライブデバッグ不可。再書込は
 *     WCH-Link のパワーサイクル or ダウンローダの「ByPass/解除」で対応。
 *   - PD7(seg DP) は既定 NRST。オプションバイト RST_MODE を GPIO 側に
 *     設定するまで DP は光らない。数字 0..F(a..g) は設定なしでも動作する。
 *     MounRiver では書込時のダウンロード設定 or WCHISPTool で RST_MODE を変更する。
 *
 * MounRiver での使い方:
 *   1. 新規に CH32V003F4P6 のプロジェクトを作成。
 *   2. 生成される User/main.c を本ファイルで置き換える。
 *   3. Peripheral(SPL) の GPIO/RCC が有効なテンプレートであること（既定で可）。
 */

#include "debug.h"   /* ch32v00x.h / GPIO / RCC などを取り込む標準テンプレートヘッダ */
#include <stdint.h>

/*
 * セグメントパターン。bit0=a, bit1=b, ... bit6=g, bit7=DP。
 * 「1 = 点灯」で定義（コモンカソード表記）。
 * 実出力はコモンアノードなので main で反転し 0=点灯 にする。DP(bit7) は常に消灯。
 */
static const uint8_t SEG_ON[16] = {
    0x3F, /* 0 : a b c d e f   */
    0x06, /* 1 : b c           */
    0x5B, /* 2 : a b d e g     */
    0x4F, /* 3 : a b c d g     */
    0x66, /* 4 : b c f g       */
    0x6D, /* 5 : a c d f g     */
    0x7D, /* 6 : a c d e f g   */
    0x07, /* 7 : a b c         */
    0x7F, /* 8 : a b c d e f g */
    0x6F, /* 9 : a b c d f g   */
    0x77, /* A : a b c e f g   */
    0x7C, /* b : c d e f g     */
    0x39, /* C : a d e f       */
    0x5E, /* d : b c d e g     */
    0x79, /* E : a d e f g     */
    0x71, /* F : a e f g       */
};

int main(void)
{
    GPIO_InitTypeDef GPIO_InitStructure = {0};

    SystemCoreClockUpdate();

    /* GPIO ポート C / D ＋ AFIO のクロック供給 */
    RCC_APB2PeriphClockCmd(RCC_APB2Periph_GPIOC | RCC_APB2Periph_GPIOD
                         | RCC_APB2Periph_AFIO, ENABLE);

    /*
     * PD1(seg b) は既定で SDI(単線デバッグ)。SDI を無効化して PD1 を GPIO に開放する。
     *   これをしないと GPIO_Init しても SDI がピンを握り続け、PD1 は駆動されない
     *   （seg b が常に消灯・PD1 が H 固定になる）。
     * 代償：以後ライブデバッグ不可。再書込は WCH-Link の power-off unlock、
     *   または PD1 を GND に落として電源投入し SWIO に戻してから行う。
     */
    GPIO_PinRemapConfig(GPIO_Remap_SDI_Disable, ENABLE);

    /*
     * PORTC PC0..PC3 = 入力フローティング
     *   TB-04 の 74HC 出力（プッシュプル・5V）が常にドライブするので pull 不要。
     *   断線時にブランク固定したいなら GPIO_Mode_IPD（内部プルダウン）に変更。
     */
    GPIO_InitStructure.GPIO_Pin   = GPIO_Pin_0 | GPIO_Pin_1 | GPIO_Pin_2 | GPIO_Pin_3;
    GPIO_InitStructure.GPIO_Mode  = GPIO_Mode_IN_FLOATING;
    GPIO_InitStructure.GPIO_Speed = GPIO_Speed_10MHz;
    GPIO_Init(GPIOC, &GPIO_InitStructure);

    /*
     * PORTD PD0..PD7 = 出力プッシュプル 10MHz
     *   off 状態は High 出力＝アノードもカソードも VDD 付近で消灯。
     */
    GPIO_InitStructure.GPIO_Pin   = GPIO_Pin_0 | GPIO_Pin_1 | GPIO_Pin_2 | GPIO_Pin_3
                                  | GPIO_Pin_4 | GPIO_Pin_5 | GPIO_Pin_6 | GPIO_Pin_7;
    GPIO_InitStructure.GPIO_Mode  = GPIO_Mode_Out_PP;
    GPIO_InitStructure.GPIO_Speed = GPIO_Speed_10MHz;
    GPIO_Init(GPIOD, &GPIO_InitStructure);

    /* 起動時は全消灯（コモンアノード＝全 High） */
    GPIO_Write(GPIOD, 0x00FF);

    while (1)
    {
        uint8_t v = (uint8_t)(GPIO_ReadInputData(GPIOC) & 0x0F);  /* D0..D3 → 0..15 */
        GPIO_Write(GPIOD, (uint16_t)(uint8_t)~SEG_ON[v]);         /* 0=点灯 に反転出力 */
    }
}

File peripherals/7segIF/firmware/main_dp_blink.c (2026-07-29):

/*
 * 7segIF firmware（お遊び版）  ―  数字表示 ＋ DP を 0.5秒ごとに点滅
 *
 * MCU        : CH32V003F4P6 (RISC-V)
 * Toolchain  : MounRiver Studio ＋ WCH 標準ペリフェラルライブラリ(SPL)
 * Display    : LTS-6960HR（コモンアノード・赤）
 *
 * 通常版 main.c との違い:
 *   - a..g（数字 0..F）は入力に追従してリアルタイム表示（同じ）。
 *   - DP(PD7) だけ 0.5秒周期で点滅させる。
 *   - 表示を止めないよう 10ms 刻みでループし、50回(=500ms)ごとに DP をトグル。
 *
 * ※ main.c と本ファイルは両方 main() を持つ。ビルドに含めるのは
 *   どちらか一方だけにすること（片方をプロジェクトのビルド対象から除外）。
 *
 * ※ DP(PD7) は既定 NRST。オプションバイト RST_MODE を GPIO 側に設定するまで
 *   DP は光らない（＝この点滅も見えない）。MounRiverの書込設定 or WCHISPTool で変更する。
 *
 * 実配線: 入力 D0=PC0..D3=PC3 / 出力 a=PD0 b=PD1 c=PD2 d=PD3 e=PD4 f=PD5 g=PD6 DP=PD7
 *         コモンアノード → セグメントは MCU ピン LOW(0) で点灯。
 */

#include "debug.h"
#include <stdint.h>

/* bit0=a..bit6=g,bit7=DP、1=点灯（コモンカソード表記）。出力時に反転する。 */
static const uint8_t SEG_ON[16] = {
    0x3F, 0x06, 0x5B, 0x4F, 0x66, 0x6D, 0x7D, 0x07, /* 0-7 */
    0x7F, 0x6F, 0x77, 0x7C, 0x39, 0x5E, 0x79, 0x71, /* 8-F */
};

#define DP_BIT      0x80u   /* PD7 = DP */
#define STEP_MS     10u     /* 表示更新の刻み */
#define BLINK_STEPS 50u     /* 10ms × 50 = 500ms でトグル */

int main(void)
{
    GPIO_InitTypeDef GPIO_InitStructure = {0};
    uint8_t  dp_on = 0;
    uint16_t tick  = 0;

    SystemCoreClockUpdate();
    Delay_Init();

    RCC_APB2PeriphClockCmd(RCC_APB2Periph_GPIOC | RCC_APB2Periph_GPIOD
                         | RCC_APB2Periph_AFIO, ENABLE);

    /* PD1(seg b) の SDI(単線デバッグ)を無効化して GPIO に開放（詳細は main.c 参照） */
    GPIO_PinRemapConfig(GPIO_Remap_SDI_Disable, ENABLE);

    /* PC0..PC3 = 入力フローティング（TB-04 の 74HC 出力が常時ドライブ） */
    GPIO_InitStructure.GPIO_Pin   = GPIO_Pin_0 | GPIO_Pin_1 | GPIO_Pin_2 | GPIO_Pin_3;
    GPIO_InitStructure.GPIO_Mode  = GPIO_Mode_IN_FLOATING;
    GPIO_InitStructure.GPIO_Speed = GPIO_Speed_10MHz;
    GPIO_Init(GPIOC, &GPIO_InitStructure);

    /* PD0..PD7 = 出力プッシュプル */
    GPIO_InitStructure.GPIO_Pin   = GPIO_Pin_0 | GPIO_Pin_1 | GPIO_Pin_2 | GPIO_Pin_3
                                  | GPIO_Pin_4 | GPIO_Pin_5 | GPIO_Pin_6 | GPIO_Pin_7;
    GPIO_InitStructure.GPIO_Mode  = GPIO_Mode_Out_PP;
    GPIO_InitStructure.GPIO_Speed = GPIO_Speed_10MHz;
    GPIO_Init(GPIOD, &GPIO_InitStructure);

    GPIO_Write(GPIOD, 0x00FF);   /* 起動時 全消灯 */

    while (1)
    {
        uint8_t v   = (uint8_t)(GPIO_ReadInputData(GPIOC) & 0x0F);
        uint8_t out = (uint8_t)~SEG_ON[v];   /* bit7=1 → DP は消灯状態 */

        if (dp_on) {
            out &= (uint8_t)~DP_BIT;         /* DP 点灯（bit7=0） */
        }
        GPIO_Write(GPIOD, out);

        Delay_Ms(STEP_MS);
        if (++tick >= BLINK_STEPS) {
            tick  = 0;
            dp_on ^= 1;                       /* 0.5秒ごとに DP をトグル */
        }
    }
}

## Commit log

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2026-06-27 チャンネル数の整合性を修正した
2026-06-29 4bitCPU回路図の修正とPCB工事中の旨をREADMEに注記
2026-06-29 4bitCPUの回路図を修正（PCBは工事中）
    [ROM_ALU_Decoder.kicad_sch, TB04addr4bitVer3.kicad_pcb, TB04addr4bitVer3.kicad_sch]
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2026-07-17 ver2: クロック・フラグ・ROM_ALU等の回路図を追加
    - clk_rst: 32.768kHz水晶+74HC4060分周(8Hz=1命令/秒・64Hz=8命令/秒・1024/2048Hz等をタップ引出し)、
    555+74HC14でマニュアル手送り、リセット回路(いずれもver1同型)
    - フラグDFF(74HC74): C_WE/Z_WEを正論理化してゲート、EXEを直接クロック源とする
    (ver1同様CLK_CPUとのANDは取らない)
    - ROM_ALU: 命令ROM×1+ALU ROM×1、フェーズ生成(74HC161/74HC238)、命令レジスタ(273)、フラグ
    - 1命令=8クロック(固定2語)を前提に確定
    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
    [ALU.kicad_sch, AddrDecord.kicad_sch, Decoder.kicad_sch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]
2026-07-18 ver2: レジスタファイル(RS00/RS01)とルート配線・発振回路定数を追加
    - clk_rst: 74HC4060発振のRf=10M/Rs=220K/C=22p×2に確定
    - RS00/RS01: R0-R7の具体回路(74HC161×4+74LS253×4)を追加
    ※図面は74LS253だがシンボル都合で実装はHC(74HC253)
    - ルート: 書込デコード/読出セレクト/RegAddrSrc MUX/データ入出力の
    外側グルーを配線(DI/DOa/DOb/Reg_WE0-7/sel_a)
    - PC_mAddrは作業中(Reg_WE8-11未結線)
    [PC_mAddr.kicad_sch, ROM_ALU.kicad_sch, TB04addr8bit.kicad_sch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]
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2026-07-29 7segIF: ファームでPD1のSDIを無効化しseg bをGPIO開放
    CH32V003のPD1(seg b)は既定でSDI(単線デバッグ)ピンのため、
    GPIO_Initより優先されseg bが点灯しない(PD1がH固定)問題を修正。
    main.c/main_dp_blink.c 両方の冒頭でAFIOクロックを有効化し
    GPIO_PinRemapConfig(GPIO_Remap_SDI_Disable, ENABLE)でSDIを無効化。
    実機で0〜F全セグメント点灯を確認(2026-07-30)。
    [main.c, main_dp_blink.c]
2026-08-10 7segIF: hardware(回路図・基板)とLICENSE/READMEを公開
    - hardware/: KiCAD現物(7segIF.kicad_sch/.kicad_pcb/.kicad_pro)を取り込み。
    README/LICENSEが適用範囲として示すパスに合わせフォルダ名をhardware/に統一。
    - sch/pcb両方のタイトルブロックに帰属を記載。CC BY-SA 4.0のURI、
    出典(ちぇりーたくあん氏 nlp/nlp-16a/Hardware/debug)、改変した旨を明記。
    これでLICENSE/README/タイトルブロックの帰属3系統がそろった。
    - LICENSE: CC BY-SA 4.0(正文URI参照+帰属+適用範囲)。適用はhardware/のみで
    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
    [7segIF.kicad_pcb, 7segIF.kicad_sch]
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2026-08-10 ver2: PC_mAddr中心に回路図の配線を更新
    7/18のコミット以降の結線作業を反映。部品・ラベルの増減はなく、
    配線(wire)とジャンクションの変更のみ。
    - PC_mAddr.kicad_sch: 配線36箇所
    - sp.kicad_sch / ROM_ALU.kicad_sch / ルートシート: 数箇所ずつ
    - TB04addr8bit.kicad_pro: KiCAD 10がERC重要度・last_pathsの
    既定値を追記したもの(設定の書き戻しで設計内容の変化ではない)
    なおこの状態のネットリストを ai-review で出力してレビュー済み。
    要修正5件と残作業は ver2/DEVLOG.md(2026-08-10)に記録した(未着手)。
    [PC_mAddr.kicad_sch, ROM_ALU.kicad_sch, TB04addr8bit.kicad_sch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]
2026-08-10 ver1: ROM_ALU_Decoderの配線を修正
    ジャンクション位置と配線経路の見直し(部品・ラベルの増減なし)。
    .kicad_pro はKiCADが書き戻した設定差分。
    [ROM_ALU_Decoder.kicad_sch]
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2026-08-11 ver2: 回路図の要修正5件を修正しアノテーションを掛け直し
    - 74HC193(旧U39/新U38)の~CO・~BOをVDD直結から開放に(出力短絡の回避)
    - 電源未接続だった4IC(74HC00/74LS32/74AHC04/74LS08)にVCC/GNDを配線
    し、バイパスコンデンサ0.1u×4を追加
    - ネット名 Decord を DCR に統一(デコーダ制御信号のラッチ不成立を解消)
    - PC_LAOD の綴りを PC_LOAD に修正
    - 書込デコーダ138の入力を OPR8-10 から sel_a0-2 へ付け替え
    (LD Ri,[Im8] が別レジスタに書く不具合の解消)
    - ver1基板由来だった参照記号をアノテーション掛け直しで整理
    (部品216個・名前付きネット146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
    [ALU.kicad_sch, AddrDecord.kicad_sch, Decoder.kicad_sch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]
2026-08-11 ver2: SPのCU/CDに相ゲートを追加、74HC00の電源ユニットを置き直し
    - CU=NAND(DCR, SP_CU&!(SP==7)) / CD=NAND(EXE, SP_CD&(SP!=0)) とし、
    74HC193をアイドルHigh・相の終わりの立ち上がりで1回だけ数える形に変更
    (POP/RETはDCR末のpre-inc、PUSH/CALLはEXE末のpost-dec)
    従来のAND直結ではPUSHがpre-decになり、連続PUSH/POPで
    レベルが継続して2回目のカウントを取りこぼす問題があった
    - 空いていた74HC00(U5)の2ゲートを使用。spシートのERCが6件減少
    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
    [TB04addr8bit.kicad_sch, sp.kicad_sch]
2026-08-11 ver2: クロック選択をロータリースイッチ化、PCの桁上げ配線に着手
    - クロック選択をDIP4連から1回路9接点ロータリー(SW7)へ変更
    左端=マニュアル、以降Q13/Q12/Q10/Q9/Q8/Q6/Q5/Q4の順で
    1→2→8→16→32→128→256→512命令/秒と右回りに高速化
    DIPのコモン短絡問題が構造的に解消。コモンに100Kプルダウン(R17)を追加し
    切替時の浮きを防止。取付ピン(MP)はGNDへ
    - PC_mAddr: CNTABLラベルを廃止し、161×4のCEPを共通ネットにまとめ
    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
    [PC_mAddr.kicad_sch, clk_rst.kicad_sch]
2026-08-11 ver2: addrMUXシートを新設、リセット起点をFCH1へ、mAddr専用レジスタを廃止
    - addrMUX.kicad_sch を新設。74HC138(U41)で SEL_M からアドレス源の
    イネーブルをワンホット生成し、74HC244×5(U42-U46)を配置
    mAddr用(U43)の入力は byte2ラッチのOPR4-11から直取り
    - mAddr専用レジスタ(IC11/IC12)を削除。byte2ラッチが mAddr を兼ねる
    これまで消費先ゼロだった OPR7/OPR11 の浮きも解消
    - 74HC238の出力割付を1つ回してリセット起点を EXE から FCH1 へ
    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
    [AddrDecord.kicad_sch, PC_mAddr.kicad_sch, ROM_ALU.kicad_sch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]
2026-08-12 ver2: 命令ラッチを1相ずらし、アドレスMUXを完成、I/Oと周辺ICを配置
    - 命令ラッチの取り込みエッジを1相ずらし(U20 Cp=FCH1→FCH2 /
    U26 Cp=FCH2→DCR)。EXE中はアドレスバスがmAddrになるため、
    従来はEXE→FCH1の境目でROMのアクセスが間に合わなかった
    - /OE_ROM のゲート入力を ~WE から ~WR へ付け替え
    (レジスタ書込許可ではなくメモリ書込で判定するのが正)
    - PCの161出力をアドレスバスから切り離し、244経由に変更
    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
    [PC.kicad_sch, ROM_ALU.kicad_sch, ROM_ALU_Decoder.kicad_sch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]
2026-08-13 ver2: 要修正5件を修正し共通データバス・オペランド源MUX・I/Oを結線
    - 6116の/CS極性を修正し、スタック域を含むRAM_STK_SEL(0xC0-0xF7)に統一
    - ALU出力をDI0-3へ直結、U21はYドライバ源として残す(LD/POP/RET対策)
    - 共通8bitデータバスMD0-7を新設(ROM/RAM/Yドライバ/IN244が排他駆動)
    - aポートMUX(74LS253x2)・IN用244・Yドライバ制御ゲートを追加
    - IN実行時のROM競合を/OE_ROMに~OE_iAddrを足して回避
    - 4bit書込時にMD4-7が浮くのをU17 bank2で0駆動
    - 74LS157のEをGND固定、孤立したPC_mAddrシートを削除
    [PC.kicad_sch, PC_mAddr.kicad_sch, ROM_ALU.kicad_sch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]
2026-08-13 ver2: ゲートICをgatesシートへ集約しアノテーションを掛け直し
    - 分散していた8パッケージ(U1/U2/U5/U25/U35/U36/U37/U51)をgatesシートへ集約
    - シートをまたぐ11本をグローバルラベル化(~P4/~P5/~OUT_SEL/~CS_RAM/
    ~OE_ROM/CLK_C/CLK_Z/PC_CNT_EN/~PC_PE/~Ena_RS01/~Enb_RS01)
    - U40のP2入力がROM_SELに吸着していたのを修正(RAM_SELが逆条件だった)
    - !P5の重複インバータを解消、未使用ゲート入力7本をGNDへ
    - ALU入力MUXをinPut→PC、PCカウンタをaddrMUX→PCへ移動
    - 全体を再アノテーション(シート順採番)。旧→新の対応は電気的変化なしを確認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
    [ALU.kicad_sch, AddrDecord.kicad_sch, Decoder.kicad_sch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]
2026-08-13 ver2: 掃除とタイミング是正(ROMのEXEゲート・フラグクロックをFCH1へ)
    - 消費先ゼロだったU1302(RAM_SEL/STACK_SEL/IN_SEL/P6)を削除し空きゲート入力をGNDへ
    - /OE_ROMの条件を生の~WRから~WR_EXE(=!(WR&EXE))へ変更
    書込命令の次のフェッチでROMが閉じる問題を解消
    - フラグDFFのクロックゲートをEXEからFCH1へ(CLK_C=FCH1&C_WE)
    INのZが間に合わない件と、Cin=C_prevの帰還でADD/SUBの結果が壊れる件を解消
    - いずれもネットリストで接続変化を照合済み。ERCはエラー98(全てwire_dangling)・警告0
    [AddrDecord.kicad_sch, clk_rst.kicad_sch, gates.kicad_sch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]
2026-08-13 ver2: Yドライバ/PCドライバを1チップ1機能に整理
    - ram: 74HC244×2を組み替え。U1102=Yドライバ専用(YD0-3→MD0-3、
    bank2はGND→MD4-7で上位0埋め、OE2本とも~YEN_Y)、U1103=PCドライバ
    専用(PC_Q0-7→MD0-7、OE2本とも~YEN_PC)。接続の集合は変更前と完全
    一致で機能等価。PCの8bitが1チップに揃いビット間スキューが揃う
    - inPut: U1001のbank2イネーブル(pin19)をVDDから~OE_iAddrへ。
    出力2Y0-3はno_connectのままなので効果は未発現
    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
    [addrMUX.kicad_sch, gates.kicad_sch, inPut.kicad_sch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]
2026-08-14 ver2: CALLの書込タイミングを是正(RAM書込パルスをCLK_CPUでゲート)
    ~WE_RAM = !(RAM_STK_SEL & EXE & WR & CLK_CPU) に変更し、
    EXE前半のCLK立下りで書込を確定させる。CALLが戻り番地でなく
    分岐先をスタックに書く問題を解消。gatesシートの空きゲート
    (U1502インバータ・U1505 NAND g3)を使い追加ICは0個。
    [gates.kicad_sch]
2026-08-15 ver2: I/Oを4ch化しアドレスバスの浮きを解消(OUTは377化・RAMのCSをEXEゲート)
    - I/Oアドレス源244・port位置MUX157・portデコード139を追加し、IN244×4/OUT×4に拡張。
    IN/OUT実行中も 0xF8|port / 0xFC|port をアドレスバスへ出すことで、全相・全命令で
    アドレスバスが必ず1つに駆動される状態にした(OUTのRAM誤書込・INのMD衝突を構造的に解消)。
    - OUTポートを74HC273→74HC377へ。~E=139出力・CP=~CLK_CPUとし、クロックゲートなしで
    EXE中間の1回だけ取り込む(取り込み余裕が15ns→半相)。
    - ~CS_RAM を !(RAM_STK_SEL & EXE) に変更(CS_RAMノード新設)。EXE末に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
    [PC.kicad_sch, RS00.kicad_sch, TB04addr8bit.kicad_sch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]
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2026-08-23 ver2: SPアップカウントのヒゲを除去(CUをCLK_CPUでマスク)
    CU=!(CU_pre & DCR)のCU_preがDCR自身でクロックされる制御ラッチU701から
    来ているため、POP/RETの次の命令のDCR立上りで幅22-46nsのヒゲが出てSPが
    余分に+1されていた(3段以上のネストで戻り番地がずれる)。
    U1506の空きORゲートでCU=!(CU_pre & DCR & ~CLK_CPU)とし、DCR開始時は
    CLK_CPUがHなのでヒゲをマスクする。カウント用の立上りは従来どおり
    DCR→EXEの境目に出るのでプリインクリメントの意味は変わらない。
    [gates.kicad_sch]
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2026-08-24 ver2: inPortの入力負荷を軽減しDIPの電源短絡を解消
    ・プルダウンを10K x16 から 47K x16 へ(R_Network04 x4 を
    R_Network08_Split x2 に集約)。VIH点の負荷 0.71mA→0.44mA
    ・DIPスイッチとVDDの間に1KΩ x16 を直列に挿入。外部機器を
    挿したままONにしたときの短絡(実質無限大)を4.7mAに制限
    [inPut.kicad_sch]
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2026-08-24 ver2: アドレス基板を分割し4枚すべて完了(要修正1件)
    TB04_3_addr を分割。45部品・56信号すべてバスへ引き出し済み。
    署名が変わったのは J101 のみ(USB-C→バスヘッダ)。
    旧トップシート TB04addr8bit.kicad_sch も削除。
    要修正: 3_addr の J103 で INPUT/OUTPUT のビット順が 4_io と逆
    (pin25=INPUT0 になっている。正は pin25=INPUT3)
    [ALU.kicad_sch, AddrDecord.kicad_sch, Decoder.kicad_sch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]
2026-08-24 ver2: 3_addrのINPUT/OUTPUTのビット順を修正し4枚の整合が取れた
    120ピン全数の突合で不一致0。基板4分割が完了。
    [TB04_3_addr.kicad_sch]
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2026-09-13 ver2: 制御板のVDDを配線(200本・全103パッド連結)とパスコン14個の向きを修正
    Claude-Session: https://claude.ai/code/session_01PWwKiTMfe5EEhTD3nUUg46
    [TB04addr8bit_ctrl.kicad_pcb]
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2026-09-17 ver2: IF板のDIPスイッチ1番ピン表示を修正(DRC 0/0)
    [TB04addr8bit_if.kicad_pcb]
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2026-09-18 ver2: 制御板のシルクが完成＝基板3枚すべて完成(DRC 0/0)
    シルク111個とロゴを追加。検証でOPR7-0→OPR7-4、SP3-0→SP2-0、
    取付穴に重なったPOWERの移動の3件を修正。
    [TB04addr8bit_ctrl.kicad_pcb]
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

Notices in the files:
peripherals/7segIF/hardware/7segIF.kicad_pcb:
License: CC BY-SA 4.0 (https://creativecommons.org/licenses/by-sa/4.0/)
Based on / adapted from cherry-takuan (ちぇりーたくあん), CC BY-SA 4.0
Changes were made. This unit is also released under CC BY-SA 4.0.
